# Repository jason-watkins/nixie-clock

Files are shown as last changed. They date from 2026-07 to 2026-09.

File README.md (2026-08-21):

[][cc-by-sa]

# Nixie Clock

USB-C powered nixie tube clock. Four IN-12B digits, two INS-1 colon lamps, K155ID1 BCD decoder/drivers.

## Boards

### Clock Face

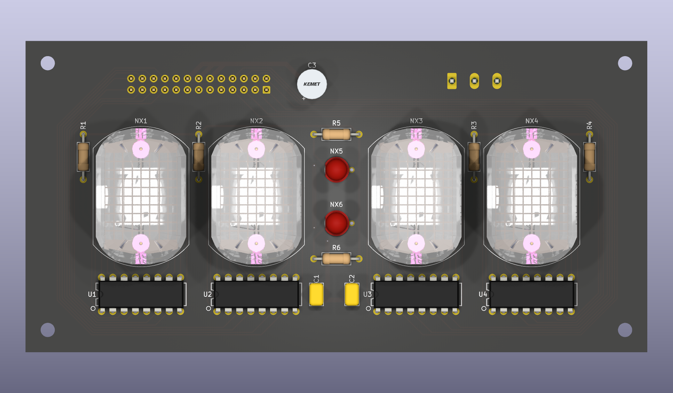
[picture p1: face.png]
Clock face board


### 170V Flyback converter

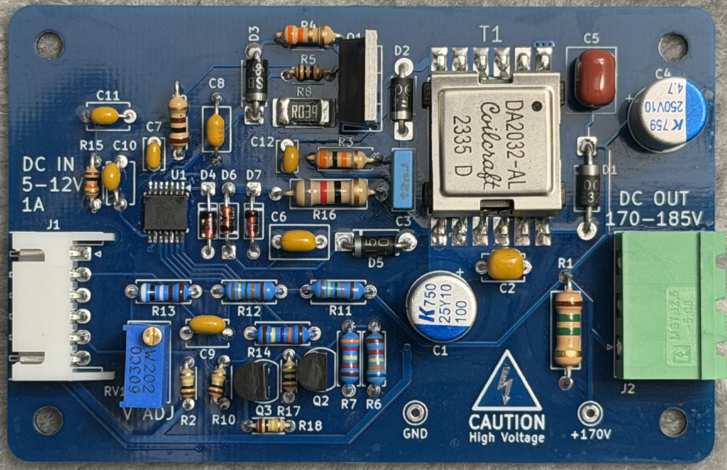
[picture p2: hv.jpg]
170 V flyback converter board


## Power

USB-PD negotiates 5-12V supply and feeds it into 3 converters:

- Flyback boost: 170V for the tube anodes
- 3.3V buck boost for the MCU. Boost exists to make sure a 3.3V FTDI type UART adapter provides the
  full 3.3V to the rail.
- 5V buck for the BCD drivers, bypassed if the source itself is 5V

## Firmware

Written in Rust, bakes in a list of SSID/password pairs at build time, tries
them until one connects, then syncs time from well-known NTP servers and
displays US Pacific time in 24 hour format.

## BCD/Tube Wiring Note

Tube cathodes are not wired to the decoder outputs in numerical order. The layout connects each
cathode to whichever decoder output it reaches most directly. The K155ID1's output order around its
package does not match the IN-12B's cathode order around its pin circle, so wiring it that way is
more trouble than it's worth. Firmware maps from BCD number to tube number in `nixie::Bcd`.

## Repository layout

- `pcb/` KiCad projects. One project each for the clock face, high voltage flyback converter and the
  main board with the MCU, USB-PD, 3.3V and 5V converters.
- `pcb/lib/` project libraries; origins and local changes in [pcb/lib/README.md](pcb/lib/README.md)
- `firmware/` firmware source code
- `docs/` design doc and vendor datasheets
- `scripts/` [make_release.py](scripts/make_release.py), fab exports with enforced revision bookkeeping

## Fab files

    python scripts/make_release.py --check
    python scripts/make_release.py

Writes gerbers, BOM, and placement files in several formats tailored for
different fab houses under `fab/` and tags the commit. The script's docstring
explains the revision rules it enforces.

## Credits

The K155ID1 symbol and its DIP16 footprint started as imports from
[judge2005's Eagle-and-KiCAD-Nixie-Libs](https://github.com/judge2005/Eagle-and-KiCAD-Nixie-Libs)
and were modified here. Full library inventory: [pcb/lib/README.md](pcb/lib/README.md).

## AI use

AI assistance is used to write and edit documentation, build symbols/footprints, and as a sounding
board for design work. All schematic drawing, PCB layout and code is done by hand.

## License

This work is licensed under a
[Creative Commons Attribution-ShareAlike 4.0 International License][cc-by-sa].

[][cc-by-sa]

[cc-by-sa]: http://creativecommons.org/licenses/by-sa/4.0/
[cc-by-sa-image]: https://licensebuttons.net/l/by-sa/4.0/88x31.png
[cc-by-sa-shield]: https://img.shields.io/badge/License-CC%20BY--SA%204.0-lightgrey.svg

except for third-party material carrying its own terms:

- `docs/datasheets/` — manufacturer datasheets and scanned Soviet tube
  documentation, redistributed for reference; sources in
  [docs/tube_notes.md](docs/tube_notes.md).
- `docs/design_analysis/fonts/` — PT Serif and IBM Plex Mono, under the SIL
  Open Font License 1.1.
- The K155ID1 symbol and DIP16 footprint, from judge2005 (no license stated,
  used with attribution); the manufacturer 3D models in
  `pcb/lib/nixie_clock.3dshapes/`; and the section data in
  `cad/ins1/shoulder_profile.py`, sampled from a third-party model. Provenance
  in [pcb/lib/README.md](pcb/lib/README.md).

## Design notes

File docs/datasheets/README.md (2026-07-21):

# Tube datasheets and extracted design values

Scans vendored from Dieter's Nixie Tube Data Archive (tube-tester.com) and
GRA & AFCH. The Soviet originals are image scans (no embedded text).

## IN-12B (ИН-12Б) — digit tubes, NX1–NX4

Source: `IN-12A_IN-12B.pdf` (original scan), `IN-12_english_gra-afch.pdf` (English summary).

| Parameter | Value |
|---|---|
| Typical maintaining (plate) voltage | ~145 V |
| Cathode current, digits | 2.5–3.5 mA |
| Decimal point (LHDP) current | 0.3–0.7 mA |
| Ignition voltage | verify in scan; NOS tubes drift upward with age |
| Digit height | 18 mm |

**Ballast (digit anodes):** R = (170 − 145) / 3 mA ≈ 8.2 kΩ.
At 2.5 mA use 10 kΩ. Dissipation ≈ 75 mW → 0.25 W part is fine.

## IN-6 (ИН-6) — colon dots, NX5–NX6

Source: `IN-6.pdf` (original label sheet, GOST 17821-75).

**Three electrodes** (footprint/symbol updated 2026-07-19 to match):
lead 1 = anode (A), lead 2 = indicator cathode (K), lead 3 = auxiliary
priming cathode (KA). Lead 1 is the physically separate one; count from it.

| Parameter | Value |
|---|---|
| Ignition voltage (either gap) | ≤ 140 V |
| Maintaining voltage @ 0.7 mA | ≤ 88–90 V |
| Permissible anode current | 0.6–0.85 mA |
| Indication current, min | 0.25 mA |
| Factory reference circuit | 200 kΩ from +180 V |

**Ballast (colon anodes):** R = (170 − 88) / 0.7 mA ≈ 117 kΩ → **120 kΩ**
gives ~0.68 mA, mid-range of permissible. Dissipation ≈ 56 mW.
One resistor per tube — never share ballast between gas tubes.

**KA handling:** auxiliary cathode exists to prime fast switching; unused in
always-on service. Leave NC (no-connect flag). Alternative if the third lead
is unwanted: clip it at the tube and leave the KA pad empty.

## Supply-rail note

IN-12 ignition worst case may approach the +170 V rail (some sources quote
up to ~200 V for aged/dark tubes). Design the HV supply with headroom:
adjustable 170–190 V, or verify strike on the actual NOS stock before
freezing the rail at 170 V. IN-6 strikes at ≤140 V — no concern.

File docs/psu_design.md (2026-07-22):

# Power system design

## Summary

The clock runs from a USB-C Power Delivery adapter. A resistor-configured
sink controller negotiates 12 V (9 V fallback) and gates it through a
back-to-back PFET load switch. Three converters hang off the switched rail:

- a 150 kHz flyback producing the nominal 170 V tube-anode rail,
  trimmable 160-196 V
- a fixed 5 V buck for the four K155ID1 binary-coded-decimal drivers
- a fixed 3.3 V buck for the MCU (ESP32 class)

Total draw is about 3 W, dominated by 15 mA at 175 V. The board uses a
single unified ground net.

The high-voltage converter is designed to match the nixie tube aesthetic.
While it is a modern flyback for efficiency, its supporting parts are
primarily through-hole, the chunkier the better, to give the converter a
somewhat retro look. The USB-C and buck sections make no such attempt;
USB-C is anachronistic on this board by definition, so those sections
follow current SMD practice.

Where SMD parts are used, the design is meant to remain hand-solderable.
As a rule of thumb, all SMD components are 0805 or larger. Hand soldering
is the requirement, not necessarily the plan: having the fab populate the
basic parts is an equally valid build path.

## USB-PD input

### Goal and strategy

Accept any Power Delivery adapter without firmware or a host processor.
The controller is configured entirely by resistor straps: it requests 12 V
when offered, falls back to 9 V, and rejects anything else. Downstream
circuits see no voltage until a contract exists, because the output passes
through a load switch the controller only closes after negotiation. On a
plain 5 V charger the board stays off rather than browning out;
the flyback's undervoltage lockout enforces this independently of the
controller. Hot-plugging is the normal operating procedure, so the
connector lines carry dedicated electrostatic-discharge protection. A
single red LED reports faults; there is no power-good indicator because
the display itself shows normal operation.

### Driving part: CYPD3176

The CYPD3176 (Infineon EZ-PD BCR-Plus) does all Power Delivery work in
hardware. Configuration:

| Strap | Setting | Divider (from VDDD) |
|---|---|---|
| VBUS_MIN | 9 V | 5.1 k / 1 k |
| VBUS_MAX | 12 V | 5.1 k / 2.4 k |
| ISNK_COARSE | 1 A | 5.1 k / 1 k |
| ISNK_FINE | +0 mA | strap to ground |
| CHARGING_MODE | float | enables all legacy charger protocols |

The strap dividers source from the chip's own VDDD pin, not the 3.3 V
rail: the pins are read ratiometrically against VDDD (canceling its
tolerance), and the 3.3 V buck sits downstream of the load switch, which
closes only after the contract the straps configure. D+ and D− route from
the connector to the chip because the legacy-protocol support uses them
for charger handshakes; the signaling is quasi-static, so they need no
differential-pair treatment. The connector's duplicate D+/D− pins are
commoned at the receptacle.

The sink-side current trip (CSP pin) is disabled by tying it to VSS.
Recovering from that trip requires an I2C host command, and this board has
no host; a trip would latch the supply off until power cycle. Overcurrent
coverage comes from the adapter's own limit, the chip's overvoltage and
undervoltage monitors, and each converter's cycle-by-cycle current limit.

FAULT drives the indicator LED. It asserts on any failed or lost contract
(no agreement, voltage out of window, insufficient offered current).

### Load switch

Two P-channel MOSFETs share a common gate, sources tied together, so
their body diodes oppose and block in both directions when off. The
chip's VBUS_CTRL output drives the gate with a microamp-class controlled
slew, which is the inrush limiter for the downstream capacitor bank. Gate
network: 1 kΩ series from VBUS_CTRL, 49.9 kΩ gate-source, 10 kΩ gate
pull-up to the raw bus for default-off, two 1 µF ramp capacitors, and a
10 V gate-source zener to protect the gate oxide during surge clamping.

Part requirements: dual PFET, drain-source rating of −30 V so the TVS
clamp voltage (about 24 V) lands inside it, gate-source rating of ±20 V
because the driver swings the gate the full rail, and on-resistance under
100 mΩ per device (the DMP3085LSD class fits). Switching speed is
irrelevant.

### Protection and support sizing

**Bus transient suppressor.** Three voltages define it: standoff at or
above the 13 V maximum rail so it never conducts in operation, breakdown
above standoff, and clamp below every victim rating downstream (the
−30 V switch pair, the flyback controller's 45 V BIAS pin, 25 V
capacitors). A 15 V-standoff unidirectional part clamping near 24 V
satisfies all three.

**Line protection.** One 5 V-standoff unidirectional
electrostatic-discharge diode per line on CC1, CC2, D+, and D−, placed in
the trace path at the connector. These cover discharge strikes only;
VBUS-to-CC cable faults are within the CC pins' 22 V rating.

**Fault LED.** 220 Ω from the FAULT pin. At the pin's guaranteed drive
point (4 mA at VDDD − 0.6 V, roughly 150 Ω effective pin impedance) the
LED runs near 4 mA; a shorted LED draws 9 mA against a 25 mA pin limit.
The LED must be red: only about 2.7 V of drive is guaranteed, which rules
out higher-forward-voltage colors.

**Bypass.** 4.7 µF plus 1 µF on the raw bus at the connector (inside the
USB-C spec's 1-10 µF attach window; capacitance behind the load switch
does not count against it), 1 µF plus two 100 nF on VDDD, 1 µF on VCCD.

## HV flyback converter

### Goal and strategy

Produce the tube-anode rail: nominally 175 V at up to 15 mA (four digits
at 3 mA plus two colon lamps at 0.7 mA is 13.4 mA). The output is
adjustable 160-196 V with a multiturn trimmer to account for unreliable
strike voltage in new-old-stock Soviet tubes.

The converter is a current-mode flyback running in discontinuous
conduction, meaning the transformer transfers all stored energy to the
output every cycle and idles at zero current before the next one. The
mode simplifies the control loop and eliminates diode reverse-recovery
loss. The design window for input is 8.5-13 V,
covering both negotiated voltages with margin.

The converter enables only above 8.1 V input, so a non-Power-Delivery
source leaves the high-voltage section cleanly off.

### Driving parts and configuration

**LM5155** (TI current-mode boost/flyback controller): 1.000 V feedback
reference, 100 mV current-limit sense threshold, 6.85 V internal
gate-drive rail, 45 V-rated BIAS input fed directly from the bus.
Configured for 150 kHz (RT = 147 kΩ), 4.7 ms soft-start (47 nF),
undervoltage lockout via a 143 kΩ / 32.4 kΩ divider (on at 8.1 V, off
near 7.4 V from the pin's 5 µA hysteresis current). PGOOD is pulled up to
VCC through 100 kΩ and broken out for the MCU.

**DA2032-AL** (Coilcraft flyback transformer): 1:10 ratio, 10 µH primary,
3 A peak rating, 0.15 µH maximum leakage. Primary windings paralleled;
secondary returns to the common ground (non-isolated use, shared-ground
feedback). The output reflects 17.5 V onto the primary during
demagnetization.

### Key sizing

**Operating point.** P_out = 2.63 W; at an assumed 85 % efficiency,
P_in ≈ 3.1 W (360 mA at 9 V). Energy per cycle 20.6 µJ gives a 2.0 A
primary peak. Worst-case conduction check at 8.5 V input: 2.39 µs on-time
plus 1.16 µs demagnetization is 3.55 µs of the 6.67 µs period, deep in
discontinuous conduction everywhere.

**Current sense.** 39 mΩ, 1 %. The controller's 100 mV ±7 % threshold
puts the current limit at 2.38-2.74 A: 17 % above the operating peak,
9 % under the core's 3 A rating. Dissipation 19 mW. The sense connection
is Kelvin-routed: the sense trace taps the resistor's own pads so trace
and solder resistance stay out of the measurement.

**Switch.** Off-state stress is input plus reflected voltage plus the
clamped leakage spike, about 48 V worst case. A 100 V logic-level TO-220
FET (IRL540N fits) leaves better than 2× margin. Losses total roughly
0.15 W (conduction 40 mW, gate 73 mW, small switching loss since turn-on
happens at zero current), no heat sink. A 10 Ω series gate resistor damps
the gate loop; turn-on at zero current means the slower edge adds no loss.

**Rectifier.** Reverse stress is V_out plus the turns ratio times maximum
input: 175 + 130 = 305 V, so a 600 V part. It must be ultra fast (about
75 ns recovery); a standard-recovery rectifier at 150 kHz would dissipate
watts. Average current is trivial. A UF4005-class axial part fills the
slot.

**Snubber.** Leakage inductance dumps 0.31 µJ per cycle (46 mW) at
switch-off. A resistor-capacitor-diode clamp across the primary holds the
spike 45 V above the input rail: 27 kΩ (0.5 W part), 10 nF film, and a
fast 100 V diode. The clamp voltage is deterministic, and at this leakage
energy the parts run well inside their ratings.

**Output capacitance.** 4.7 µF 250 V solid polymer plus 100 nF 250 V
film. Droop between demagnetization pulses is 21 mV; capacitance is not
the constraint. The polymer part's equivalent series resistance (its
internal resistance, about 0.5 Ω) lets through 100 mV edges, which the
film bypass absorbs. Polymer rather than wet electrolytic eliminates the
dry-out wear mechanism; the 250 V rating keeps 32 % margin at the trim
ceiling.

**Input capacitance.** 100 µF polymer plus 4.7 µF ceramic at the primary
loop. The 2 A triangular primary pulses must come from local capacitance,
not the cable; ripple demand is about 0.6 A against a multi-amp rating.

**Feedback divider.** Sized for about 100 µA of divider current. The top
leg is two 866 kΩ resistors in series so each body sees 87 V, inside the
element rating of a standard through-hole resistor (small chip resistors
are rated 50-75 V per element, so the divider is through-hole).
Bottom leg 8.87 kΩ plus a 2 kΩ multiturn trimmer spans 160-196 V.

**Bleeder.** 470 kΩ across the output serves two purposes: it discharges
the rail below 50 V within about 3 s of unplugging (2.2 s time constant),
and its 0.37 mA is a minimum load that keeps the loop in regulation with
the tubes unplugged from their sockets. 65 mW, 250 V-rated body.

**Compensation.** The error-amplifier network is 10 kΩ and 100 nF with a
220 pF high-frequency capacitor cancelling the output capacitor's
equivalent-series-resistance zero. Against the roughly 6 Hz load pole
this places the loop zero near 160 Hz and crossover near 1 kHz.

### Bench tuning

The compensation values are starting values. To verify: step the load
between blanked and full display (or switch a resistive dummy load) while
watching the rail. The target is monotonic
recovery with no ringing. If the response rings, increase the 100 nF or
reduce the 10 kΩ; if it is sluggish and margin allows, raise the 10 kΩ.

Two other bench checks. Strike voltage: raise the
trimmer until every digit of the actual tube stock strikes reliably, then
set the rail about 10 V above that point. Lockout: on a 5 V source the
converter must remain completely off.

## LV buck converters

### Goal and strategy

Two copies of one synchronous buck block, identical except for the
regulator: 5 V for the binary-coded-decimal drivers (about 0.1 A, nearly
static), 3.3 V for the MCU (ESP32-class Wi-Fi bursts of 300-500 mA). Identical blocks keep the bill of materials to one set of
support parts. Both rails are switched rather than linear: at 12 V input
a linear 5 V regulator dissipates more power than it delivers, and the
3.3 V rail must supply Wi-Fi bursts without sagging.

The K155ID1 drivers are TTL, which accepts 3.3 V CMOS logic levels
directly (2.0 V input-high threshold), so the rails need no level
shifting between them.

Both bucks switch at 1.1 MHz, two decades above the flyback; the
converters do not interact.

### Driving parts and configuration

AP63205 (5 V) and AP63203 (3.3 V): fixed-output synchronous bucks,
TSOT-26, 2 A rated, internally compensated, 1.1 MHz, built-in 4 ms
soft-start, 22 µA quiescent. Per block: feedback pin tied directly to the
output (fixed-output variants), enable tied to input (auto-start;
sequencing is handled upstream by the load switch), 100 nF bootstrap
capacitor between BST and SW.

### Key sizing

**Inductor.** 4.7 µH, the same part on both rails. Ripple at
12 V input is 0.56 A on the 5 V rail and 0.46 A on 3.3 V, 23-28 % of the
2 A rating. Saturation current must exceed the regulator's worst-case
3.1 A cycle-by-cycle limit (not the load), since the limit is ineffective
once the inductor saturates; the part is specified at 4 A. Shielded or semi-shielded construction, placed away from
the Configuration Channel lines and feedback nets.

**Input capacitor.** 10 µF, 25 V, X7R per block. At 12 V bias a
small-case ceramic delivers roughly half its rated capacitance;
acceptable at these loads with the attach capacitance on the same rail
upstream.

**Output capacitors.** Two 22 µF, 25 V per block. After bias derating
the banks deliver about 26 µF effective at 5 V and 33 µF at 3.3 V,
against a load-transient requirement of 9.5 µF and 21 µF respectively at
the full 2 A rating, inside the recommended 22-68 µF window.
The 25 V rating preserves the capacitance: derating scales with the
fraction of rated voltage in use.

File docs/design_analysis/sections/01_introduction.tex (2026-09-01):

\section{Introduction}
\label{sec:introduction}

The board drives six cold-cathode gas-discharge indicator tubes from a USB-C
Power Delivery source. Four IN-12B tubes show the hours and minutes. Two INS-1
tubes make the colon. One K155ID1 BCD decoder/driver controls each numeric
tube. The MCU commands the driver to select one of ten cathodes.

The 170~V supply powers the tube anodes. The 5~V supply powers the drivers. The
3.3~V supply powers the MCU. The USB-PD input stage supplies all three
converters. Thus, the tube and driver ratings set the requirements for each
upstream converter.

The analysis first derives the tube and driver requirements
(\cref{sec:tubes,sec:bcd-driver}). It then derives the 170~V flyback converter
(\cref{sec:hv-components,sec:hv-converter}). The next sections derive the 5~V
and 3.3~V supplies
(\cref{sec:lv-components,sec:5v-converter,sec:3v3-converter}). The last section
derives the USB-PD input stage.

\paragraph{Method.} Each parameter for a critical named component comes from a
datasheet in \texttt{docs/datasheets/}. Each parameter includes a file and page
reference. Datasheet ranges, tolerances, and test conditions remain with the
parameter. These details identify guaranteed limits, typical values, and test
values.

Parameters without a local datasheet use standard engineering practice. This
rule applies to common resistors, capacitors, and diodes. Package constraints
apply only when a critical part is available in one package. Otherwise, the
analysis applies at the schematic level.

\paragraph{Construction.} The 170~V converter, tube circuits, and driver
circuits use through-hole parts when possible. Larger parts are preferred when
multiple parts meet the requirements. The USB-PD circuit and low-voltage
supplies use surface-mount parts. The assembly supplier installs these parts.
Construction preferences do not change the derived electrical requirements.

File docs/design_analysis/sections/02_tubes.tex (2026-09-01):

\section{Nixie tube characteristics}
\label{sec:tubes}

The design uses six cold-cathode gas-discharge indicator tubes. Four tubes show
the hours and minutes. Two tubes make the colon. \Cref{tab:tube-designators}
defines their designators.

\begin{table}[htbp]
\centering
\caption{Nixie tube designators}\label{tab:tube-designators}
\begin{tabular}{|l|l|}
\hline
\textbf{Designator} & \textbf{Component} \\
\hline
NX1 to NX4 & IN-12B digit tubes (HH:MM display) \\
\hline
NX5 to NX6 & INS-1 colon tubes (colon separator) \\
\hline
\end{tabular}
\end{table}

Both parts have scanned Soviet factory datasheets. The tables copy the values
from these scans. They include the Russian parameter name when the English
meaning is not clear. The datasheets do not always give minimum, typical, and
maximum values. Some values are one-sided limits. The anode-supply design uses
these limits conservatively.

\subsection{IN-12B (digit tubes, NX1 to NX4)}
\label{sec:in12b}

Sources: \texttt{IN-12A\_IN-12B.pdf}, identified as [RU], is the Soviet factory
datasheet for the IN-12A and IN-12B. The IN-12B adds a decimal-point cathode.
The \texttt{IN-12\_english\_gra-afch.pdf} summary, identified as [EN], provides
an English cross-check.

{\footnotesize
\begin{longtable}{|L{3.6cm}|c|c|c|c|L{4.4cm}|c|}
\caption{IN-12B electrical and physical characteristics}\label{tab:in12b}\\
\hline
\textbf{Parameter} & \textbf{Min} & \textbf{Typ} & \textbf{Max} & \textbf{Units} & \textbf{Conditions} & \textbf{Source} \\
\hline
\endfirsthead
\caption[]{IN-12B electrical and physical characteristics (continued)}\\
\hline
\textbf{Parameter} & \textbf{Min} & \textbf{Typ} & \textbf{Max} & \textbf{Units} & \textbf{Conditions} & \textbf{Source} \\
\hline
\endhead
Maintaining (plate) voltage & & \num{145} & & \si{\volt} & ``Typical Plate Voltage'' & [EN] p.1 \\
\hline
Ignition voltage & & & \num{170} & \si{\volt} & discharge-onset voltage (``Напряжение возникновения разряда''); not split by variant & [RU] p.4 \\
\hline
Cathode (digit) current, DC operating & \num{2.5} & & \num{3.5} & \si{\milli\ampere} & ``Ток рабочий, постоянный, для цифр'' & [RU] p.4 \\
\hline
Cathode (digit) current, average (unfiltered half-wave AC) & \num{1} & & \num{2} & \si{\milli\ampere} & ``Ток рабочий, средний\ldots для цифр'' & [RU] p.4 \\
\hline
Cathode (digit) overload current & & & \num{5} & \si{\milli\ampere} & Time-limited; see overload duration below & [RU] p.4 \\
\hline
Decimal-point cathode current, DC operating & \num{0.3} & & \num{0.5} & \si{\milli\ampere} & IN-12B only (pin 12); IN-12A pin 12 unconnected & [RU] p.4 \\
\hline
Decimal-point overload current & & & \num{0.7} & \si{\milli\ampere} & & [RU] p.4 \\
\hline
Overload duration limit, IN-12A & & & \num{30} & min & Applies to the \SI{5}{\milli\ampere} digit overload above & [RU] p.5 \\
\hline
Overload duration limit, IN-12B & & & \num{33} & min & Applies to the \SI{5}{\milli\ampere} digit / \SI{0.7}{\milli\ampere} decimal-point overload above & [RU] p.5 \\
\hline
Anode supply voltage & \num{200} & \num{250} & & \si{\volt} & DC or half-wave-rectified AC; the \num{250}~V recommended value reduces discharge-onset delay time & [RU] p.4, p.5 \\
\hline
Conditioning current, pulsed & \num{1} & & \num{2} & \si{\milli\ampere} & $\geq$\SI{1}{\minute}/cathode, applied once after storage & [RU] p.5 \\
\hline
Conditioning current, DC & \num{2.5} & & \num{3} & \si{\milli\ampere} & $\geq$\SI{1}{\minute}/cathode, applied once after storage & [RU] p.5 \\
\hline
Continuous single-cathode life rating & & & \num{1000} & h & ``Longevity'' mode, one cathode continuously lit & [RU] p.5 \\
\hline
Digit height & & \num{18} & & mm & & [EN] p.1 \\
\hline
Envelope diameter & \num{29} & & \num{31} & mm & $-2$~mm tolerance [RU]; [EN] gives \SI{32}{\milli\meter} & [RU] p.3, [EN] p.1 \\
\hline
\end{longtable}
}

\paragraph{Data not specified.} Neither source specifies total anode current,
interelectrode capacitance, anode-to-cathode capacitance, a ballast resistance,
or a target anode current in the \SIrange{2.5}{3.5}{\milli\ampere} range.

\paragraph{Open item: anode supply voltage.} The datasheet specifies a minimum
anode supply of \SI{200}{\volt} and recommends \SI{250}{\volt}. The derived
anode-rail range is \SIrange{164.8}{191.5}{\volt}
(\cref{sec:hv-converter}). Thus, the design does not meet the specified minimum.

The factory value can apply to unfiltered half-wave AC (inferred). In this
mode, the supply stays near zero during approximately half of each mains cycle.
The peak voltage must then exceed the \SI{145}{\volt} typical maintaining
voltage. This condition gives sufficient average current and reliable ignition.
A regulated DC supply does not have this waveform. The datasheet does not
explain the difference.

\Cref{sec:hv-converter} keeps this item open. During bench adjustment, increase
the output until all installed digits ignite reliably. Then set the output
approximately \SI{10}{\volt} above this value.

\subsection{INS-1 (colon tubes, NX5 to NX6)}
\label{sec:ins1}

Source: \texttt{INS-1.pdf}, Soviet factory datasheet ODO.334.095 TU. Count the
two leads from the indicator dot. Lead 1 is the anode, which is the small
cylinder. Lead 2 is the cathode, which is the large cylinder. The tube has no
auxiliary or priming electrode.

{\footnotesize
\begin{longtable}{|L{4.6cm}|c|c|c|c|L{3.6cm}|c|}
\caption{INS-1 electrical characteristics}\label{tab:ins1}\\
\hline
\textbf{Parameter} & \textbf{Min} & \textbf{Typ} & \textbf{Max} & \textbf{Units} & \textbf{Conditions} & \textbf{Page} \\
\hline
\endfirsthead
\caption[]{INS-1 electrical characteristics (continued)}\\
\hline
\textbf{Parameter} & \textbf{Min} & \textbf{Typ} & \textbf{Max} & \textbf{Units} & \textbf{Conditions} & \textbf{Page} \\
\hline
\endhead
Striking voltage & \num{65} & & \num{90} & \si{\volt} & Discharge-onset voltage (``Напряжение возникновения разряда''); no test current given & 2 \\
\hline
Maintaining voltage & & & \num{55} & \si{\volt} & ``Напряжение поддержания разряда''; single-sided limit, no minimum given & 2 \\
\hline
Optimal indication current & & \num{0.5} & & \si{\milli\ampere} & ``Оптимальным током, обеспечивающим достаточную яркость свечения''; a brightness recommendation, with no band around it & 3 \\
\hline
\end{longtable}
}

\paragraph{Conditioning after storage.} After long storage, operate the tube at
its nominal discharge current for one to two minutes. The datasheet refers to
GOST 11163-84 and OST 11~339.003-75. The IN-12B has a similar instruction
(\cref{sec:in12b}).

\paragraph{Data not specified.} The datasheet gives no minimum maintaining
voltage. It gives no operating-current range around the
\SI{0.5}{\milli\ampere} brightness value. It also gives no maximum switching
frequency, interelectrode capacitance, ballast value, or envelope dimensions.

\Cref{sec:hv-load-colon} sizes the ballast from the
\SI{0.5}{\milli\ampere} value. It also gives the current range caused by output
adjustment. A tube with a maintaining voltage below \SI{55}{\volt} draws more
current through a fixed ballast. The datasheet gives no lower limit for this
calculation.

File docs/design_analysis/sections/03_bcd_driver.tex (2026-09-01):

\section{BCD decoder/driver characteristics}
\label{sec:bcd-driver}

One K155ID1 BCD decoder/driver controls each IN-12B tube
(\cref{sec:tubes}). U1 to U4 are Soviet functional equivalents of the Texas
Instruments SN74141. Each driver has ten open-collector outputs. Each output
connects directly to one tube cathode. The selected output sinks current and
pulls its cathode low. The other nine outputs are high impedance. The circuit
has no high-voltage buffer between the driver and the tube. Thus, the driver
output must tolerate the voltage on an unselected cathode.

\paragraph{Substitution.} No K155ID1 datasheet is in
\texttt{docs/datasheets/}. This analysis assumes that the K155ID1 is
electrically equivalent to the SN74141 (inferred). The values come from
\texttt{SN74141\_TI.pdf}, published in 1972 and revised in 1983. The source has
separate absolute-maximum and operating-characteristic tables. The following
tables keep this separation. \Cref{sec:bcd-voltage-risk} depends on the source
of each off-state voltage. Tags \textbf{[ROC]} and \textbf{[EC]} identify the
two operating tables.

{\footnotesize
\begin{longtable}{|L{4.6cm}|c|c|c|L{4.2cm}|c|}
\caption{SN74141 absolute maximum ratings (substituting for K155ID1)}\label{tab:sn74141-max}\\
\hline
\textbf{Parameter} & \textbf{Min} & \textbf{Max} & \textbf{Units} & \textbf{Conditions} & \textbf{Page} \\
\hline
\endfirsthead
\caption[]{SN74141 absolute maximum ratings (substituting for K155ID1) (continued)}\\
\hline
\textbf{Parameter} & \textbf{Min} & \textbf{Max} & \textbf{Units} & \textbf{Conditions} & \textbf{Page} \\
\hline
\endhead
Supply voltage \(V_{CC}\) & & \num{7} & \si{\volt} & relative to network ground & 2 \\
\hline
Input voltage & & \num{5.5} & \si{\volt} & & 2 \\
\hline
Current into any output (off-state) & & \num{2} & \si{\milli\ampere} & & 2 \\
\hline
Operating free-air temperature & \num{0} & \num{70} & \si{\celsius} & & 2 \\
\hline
Storage temperature & \num{-65} & \num{150} & \si{\celsius} & & 2 \\
\hline
\end{longtable}
}

{\footnotesize
\begin{longtable}{|L{4.6cm}|c|c|c|c|L{3.4cm}|c|}
\caption{SN74141 recommended operating conditions and electrical characteristics (substituting for K155ID1)}\label{tab:sn74141}\\
\hline
\textbf{Parameter} & \textbf{Min} & \textbf{Typ} & \textbf{Max} & \textbf{Units} & \textbf{Conditions} & \textbf{Source} \\
\hline
\endfirsthead
\caption[]{SN74141 recommended operating conditions and electrical characteristics (substituting for K155ID1) (continued)}\\
\hline
\textbf{Parameter} & \textbf{Min} & \textbf{Typ} & \textbf{Max} & \textbf{Units} & \textbf{Conditions} & \textbf{Source} \\
\hline
\endhead
Supply voltage \(V_{CC}\) & \num{4.75} & \num{5} & \num{5.25} & \si{\volt} & & [ROC] p.2 \\
\hline
\textbf{Off-state output voltage} & & & \textbf{\num{60}} & \si{\volt} & & \textbf{[ROC] p.2} \\
\hline
\(V_{IH}\), high-level input voltage & \num{2} & & & \si{\volt} & & [EC] p.2 \\
\hline
\(V_{IL}\), low-level input voltage & & & \num{0.8} & \si{\volt} & & [EC] p.2 \\
\hline
\(V_{IK}\), input clamp voltage & & & \num{-1.5} & \si{\volt} & \(V_{CC}=\)min, \(I_I=-5\)~mA & [EC] p.2 \\
\hline
\(V_{O(on)}\), on-state output voltage & & & \num{2.5} & \si{\volt} & \(V_{CC}=\)min, \(I_O=7\)~mA & [EC] p.2 \\
\hline
\textbf{\(V_{O(off)}\), off-state output voltage, counts 0 to 9} & \textbf{\num{60}} & & & \si{\volt} & \(V_{CC}=\)max, \(I_O=0.5\)~mA & \textbf{[EC] p.2} \\
\hline
\(I_{O(off)}\), off-state reverse current & & & \num{50} & \si{\micro\ampere} & \(V_{CC}=\)max, \(V_O=55\)~V, \(T_A=55\)\si{\celsius} & [EC] p.2 \\
\hline
\(I_{O(off)}\), off-state reverse current, counts 10 to 15 & & \num{5} & \num{15} & \si{\micro\ampere} & \(V_O=30\)~V, \(T_A=70\)\si{\celsius} & [EC] p.2 \\
\hline
\(I_I\), input current at max input voltage & & & \num{1} & \si{\milli\ampere} & \(V_{CC}=\)max, \(V_I=5.5\)~V & [EC] p.2 \\
\hline
\(I_{IH}\), A input & & & \num{40} & \si{\micro\ampere} & \(V_{CC}=\)max, \(V_I=2.4\)~V & [EC] p.2 \\
\hline
\(I_{IH}\), B/C/D input & & & \num{80} & \si{\micro\ampere} & \(V_{CC}=\)max, \(V_I=2.4\)~V & [EC] p.2 \\
\hline
\(I_{IL}\), A input & & & \num{-1.6} & \si{\milli\ampere} & \(V_{CC}=\)max, \(V_I=0.4\)~V & [EC] p.2 \\
\hline
\(I_{IL}\), B/C/D input & & & \num{-3.2} & \si{\milli\ampere} & \(V_{CC}=\)max, \(V_I=0.4\)~V & [EC] p.2 \\
\hline
\(I_{CC}\), supply current & & \num{16} & \num{25} & \si{\milli\ampere} & \(V_{CC}=\)max, inputs grounded, outputs open & [EC] p.2 \\
\hline
\end{longtable}
}

Pin mapping for the 16-pin DIP: BCD inputs A, B, C, and D are on pins 3, 6, 7,
and 4. \(V_{CC}\) is on pin 5. Ground is on pin 12. Outputs 0 to 9 are on pins
16, 15, 8, 9, 13, 14, 11, 10, 1, and 2. The datasheet does not specify package
thermal resistance, maximum junction temperature, ESD rating, or propagation
delay.

\subsection{Off-state output voltage}
\label{sec:bcd-voltage-risk}

The absolute-maximum table gives no off-state output-voltage limit. It gives
only a \SI{2}{\milli\ampere} off-state output-current limit. The only off-state
voltage is \SI{60}{\volt}. This value is a guaranteed operating condition. The
electrical-characteristics table also guarantees no breakdown at
\SI{60}{\volt} with a \SI{0.5}{\milli\ampere} test load. The datasheet does not
specify operation above \SI{60}{\volt}.

Two leakage-current tests use lower voltages. The maximum leakage is
\SI{50}{\micro\ampere} at \SI{55}{\volt}. The typical and maximum leakage is
\SI{5}{\micro\ampere} and \SI{15}{\micro\ampere} at \SI{30}{\volt}. These test
values are not standoff-voltage limits.

The anode rail spans \SIrange{164.8}{191.5}{\volt}
(\cref{sec:hv-converter}). An unselected cathode can see approximately
\SIrange{145}{191.5}{\volt}. This range is 2.4 to 3.2 times the guaranteed
\SI{60}{\volt} standoff.

Amateur Nixie clocks commonly use direct cathode drive at similar rail voltages
(inferred). This use does not prove compliance with the SN74141 rating. The
actual breakdown voltage can exceed the guaranteed value (inferred). Also, an
unselected cathode floats in the tube discharge field (inferred). A resistive
model can therefore overestimate its voltage. These explanations have no cited
source. The item remains open until a K155ID1 datasheet or a measurement gives
a higher verified rating.

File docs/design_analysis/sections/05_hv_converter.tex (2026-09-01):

\section{170~V flyback converter derivation}\label{sec:hv-converter}

The 170~V supply uses an LM51561H flyback controller
(\cref{sec:lm5156h}). This section specifies its circuit requirements and
component values. \Cref{sec:tubes} defines NX1 to NX6.
\Cref{tab:hv-designators} defines the remaining designators.

{\footnotesize
\begin{table}[htbp]
\centering
\caption{170~V flyback converter: component designators}\label{tab:hv-designators}
\begin{tabular}{|l|l|}
\hline
\textbf{Designator} & \textbf{Function} \\
\hline
\des{T}{HV} & Flyback transformer \\

\hline
\des{R}{BALDIG} & Digit-tube anode ballast, one per tube (NX1 to NX4) \\

\hline
\des{R}{BALCOL} & Colon-tube anode ballast, one per tube (NX5 and NX6) \\

\hline
\des{Q}{HVSW} & Primary-side switching FET \\

\hline
\des{R}{HVCS} & Current-sense resistor \\

\hline
\des{R}{HVCSF}, \des{C}{HVCSF} & CS-pin filter \\

\hline
\des{R}{HVD1}, \des{R}{HVD2} & Feedback divider, upper (fixed) \\

\hline
\des{R}{HVD3}, \des{RV}{HVTRIM} & Feedback divider, lower (fixed \& trim) \\

\hline
\des{R}{HVRT} & RT (switching-frequency-set) resistor \\

\hline
\des{R}{HVCOMP}, \des{C}{HVC1}, \des{C}{HVC2} & COMP-pin compensation network \\

\hline
\des{R}{HVGON} & Gate-drive resistor (turn-on) \\

\hline
\des{R}{HVGOFF}, \des{D}{HVGOFF} & Turn-off speedup network (bypasses \des{R}{HVGON} on turn-off only) \\

\hline
\des{D}{HVRECT} & Output rectifier diode \\

\hline
\des{R}{HVCL}, \des{C}{HVCL}, \des{D}{HVCL} & RCD clamp (snubber) network \\

\hline
\des{R}{HVBLEED} & Bleeder resistor \\

\hline
\des{C}{HVSS} & Soft-start capacitor \\

\hline
\des{R}{HVUV1}, \des{R}{HVUV2} & Input UVLO divider \\

\hline
\des{Q}{HVINH}, \des{R}{HVINHPU}, \des{R}{HVINHPD} & Display inhibit shunt and its gate divider \\

\hline
\des{Q}{HVREL}, \des{R}{HVRELPD} & Inhibit release switch and its gate pull-down \\

\hline
\des{R}{HVPG} & PGOOD pull-up resistor \\

\hline
\des{C}{HVVCC} & VCC regulator bypass capacitor \\

\hline
\des{C}{HVPUMP}, \des{R}{HVPUMP} & Bias charge-pump coupling capacitor and series resistor \\

\hline
\des{D}{HVPUMP}, \des{D}{HVRESET} & Charge-pump delivery and reset diodes \\
\hline
\des{D}{HVSTART} & BIAS start-up diode from $V_{\mathrm{BUS}}$ \\
\hline
\des{D}{HVZ} & BIAS clamp zener \\
\hline
\des{C}{HVBIAS} & BIAS reservoir capacitor \\
\hline
\des{C}{HVI1}, \des{C}{HVI2} & Input bulk / high-frequency capacitance \\
\hline
\des{C}{HVO1}, \des{C}{HVO2} & Output capacitance \\

\hline
\end{tabular}
\end{table}
}

\begin{figure}[htbp]
  \centering
  
  \caption{170~V flyback converter: reference schematic}\label{fig:hv}
\end{figure}

\Cref{fig:hv} shows the connections. It does not show the tubes or ballast
resistors \des{R}{BALDIG} and \des{R}{BALCOL}. \Cref{sec:hv-load} derives these
loads on $V_{\mathrm{HV}}$.

The input $V_{\mathrm{BUS}}$ spans \SIrange{4.75}{12.6}{\volt}
(\cref{sec:pd-classes}). The lower limit is the \SI{5}{\volt} contract at
$-5\,\%$. The upper limit is the \SI{12}{\volt} contract at $+5\,\%$. The
nominal input is \SI{9}{\volt}.

Operation at \SI{4.75}{\volt} adds three requirements. The converter needs the
auxiliary bias supply in \cref{sec:hv-house-pump}. It needs the UVLO threshold
in \cref{sec:hv-uvlo}. It also needs the display inhibit in
\cref{sec:hv-inhibit}. The inhibit uses the negotiated current limit because
the contract voltage does not identify the available current.

\subsection{Preliminaries}\label{sec:hv-prelim}

\subsubsection{Switching frequency}\label{sec:hv-fsw-choice}

In DCM, $L_p f_{\mathrm{sw}} I_{\mathrm{pk}}^2 = 2 P_{\mathrm{in}}$. The
transformer sets $L_p$ (\cref{sec:da2032}). The load sets $P_{\mathrm{in}}$
(\cref{sec:hv-budget}). Thus, the switching frequency sets the peak current.
It also sets the margin below the \SI{3.0}{\ampere} saturation rating. Two
constraints limit the frequency. Both scale with $\sqrt{f_{\mathrm{sw}}}$.

Both $t_{\mathrm{on}}$ and $t_{\mathrm{dem}}$ are proportional to
$f_{\mathrm{sw}}^{-1/2}$. The period is proportional to
$f_{\mathrm{sw}}^{-1}$. Therefore, the conduction fraction increases with
$\sqrt{f_{\mathrm{sw}}}$. At the worst condition in \cref{sec:hv-dcm}, DCM
ends at \SI{185}{\kilo\hertz}. The idle fraction falls to $5\,\%$ at
\SI{168}{\kilo\hertz}.

At low frequency, the permitted current-sense resistance decreases
(\cref{sec:hv-cs-sense}). Core protection requires \des{R}{HVCS} to be at least
\SI{37.8}{\milli\ohm}. The power-delivery limit is
$\SI{93}{\milli\volt}/I_{\mathrm{pk}}^{(L\min)}$. This limit increases with
$\sqrt{f_{\mathrm{sw}}}$. The two limits are equal at
\SI{132}{\kilo\hertz}. The specified \SI{39}{\milli\ohm} resistor meets the
power-delivery limit above \SI{141}{\kilo\hertz}.

The loss model does not add a tighter frequency constraint. The design uses
\SI{150}{\kilo\hertz}. This value is inside both permitted ranges. The implemented frequency
is \SI{149.4}{\kilo\hertz}. At this frequency, the commanded peak current is
\SI{2.18}{\ampere}, or $73\,\%$ of $I_{\mathrm{sat}}$.

\subsubsection{RT resistor}\label{sec:hv-fsw}

For the \SI{150}{\kilo\hertz} target of \cref{sec:hv-fsw-choice}, the RT
equation of \cref{sec:lm5156h} gives

\begin{align*}
  R_T &= \frac{2.21\times10^{10}}{f_{RT}} - 955
       = \frac{2.21\times10^{10}}{1.5\times10^{5}} - 955
       = \SI{146.4}{\kilo\ohm}.
\end{align*}
The nearest standard value is $\des{R}{HVRT} = \SI{147}{\kilo\ohm}$. It gives
\begin{align*}
  f_{RT} &= \frac{2.21\times10^{10}}{147\,000 + 955} = \SI{149.4}{\kilo\hertz}
\end{align*}
All subsequent arithmetic uses \SI{149.4}{\kilo\hertz}.

The DA2032-AL is characterized only at \SI{100}{\kilo\hertz}
(\cref{sec:da2032}). The analysis applies its inductance and saturation data at
\SI{149.4}{\kilo\hertz} (inferred). It does not apply the core-loss data at
this frequency. \Cref{sec:hv-op} includes a core-loss allowance.

\subsubsection{Input UVLO}\label{sec:hv-uvlo}

UVLO must release below the \SI{4.75}{\volt} minimum input. The release voltage
must include the LM51561H threshold tolerance. A \SI{4.75}{\volt} release value
could prevent operation at the specified minimum. The design target is
\SI{4.4}{\volt}.

An external divider sets the UVLO/SYNC thresholds. The typical thresholds are
\SI{1.5}{\volt} rising and \SI{1.45}{\volt} falling
(\cref{sec:lm5156h}). The required divider ratio is:
\begin{align*}
  \frac{\des{R}{HVUV1}+\des{R}{HVUV2}}{\des{R}{HVUV2}}
  &= \frac{4.4}{1.5} = 2.93.
\end{align*}

The divider ratio does not set \des{R}{HVUV2}. A value of tens of kilohms gives
low quiescent current. It also gives useful hysteresis from the
\SI{5}{\micro\ampere} pin current (\cref{sec:lm5156h}). The design uses
\SI{32.4}{\kilo\ohm}:
\begin{align*}
  \des{R}{HVUV1} &= \des{R}{HVUV2}\left(\frac{4.4}{1.5} - 1\right)
  = 32.4 \times 1.933 = \SI{62.6}{\kilo\ohm}
  \;\rightarrow\; \SI{63.4}{\kilo\ohm}.
\end{align*}

The same pin has an EN comparator with an approximately
\SI{0.52}{\volt} rising threshold. The divider refers this threshold to
\SI{1.54}{\volt} at $V_{\mathrm{BUS}}$. Thus, EN becomes true before UVLO
releases during a monotonic input ramp. One divider serves both comparators.

\subsubsection{Display inhibit}\label{sec:hv-inhibit}

UVLO prevents operation before the input rail is present. It does not verify
that the source can supply the tube current. The MCU reads the negotiated
USB-PD contract and controls a display-inhibit signal. N-channel MOSFET
\des{Q}{HVINH} is across \des{R}{HVUV2}. It grounds UVLO/SYNC when it is on. The
MCU releases the inhibit. Two requirements set the gate circuit.

\begin{itemize}[nosep]
  \item \textbf{Assert the inhibit before converter operation.} The MCU and
    converter both use $V_{\mathrm{BUS}}$. However, the MCU 3.3~V rail starts
    after $V_{\mathrm{BUS}}$ appears (\cref{sec:3v3-converter}). A gate bias
    from the 3.3~V rail would depend on two converter start times. A gate bias
    from $V_{\mathrm{BUS}}$ rises with the UVLO divider. Resistor ratios then set
    the sequence.
  \item \textbf{Isolate the MCU control pin from the gate node.} The gate bias
    can reach \SI{11.5}{\volt}. The MCU pin limit is \(V_{DD}+0.3\)~V
    (\cref{sec:esp32}). Thus, the control pin and gate cannot use one node.
\end{itemize}

\des{R}{HVINHPU} and \des{R}{HVINHPD} divide $V_{\mathrm{BUS}}$ onto the gate of
\des{Q}{HVINH}. A second N-channel MOSFET, \des{Q}{HVREL}, pulls this gate to
ground when the MCU enables the display. \des{R}{HVRELPD} holds
\des{Q}{HVREL} off when the MCU pin is high impedance. Thus, a high-impedance
MCU pin keeps the display inhibited. \Cref{sec:esp32-usb} gives the same safe
state to the USB data switch.

\paragraph{Gate divider.} $\des{R}{HVINHPU} = \SI{100}{\kilo\ohm}$ and
$\des{R}{HVINHPD} = \SI{1}{\mega\ohm}$ put $0.909\,V_{\mathrm{BUS}}$ on the
gate nominally. The nominal gate voltage spans \SIrange{4.32}{11.5}{\volt}.
Thus, the required
gate rating is $V_{GS} \geq \pm\SI{12}{\volt}$. The pair draws a maximum of
\SI{11.5}{\micro\ampere}.

\paragraph{Ordering.} The earliest UVLO release includes both divider tolerances
and the minimum rising threshold. It occurs at
$V_{\mathrm{BUS}} = \SI{4.16}{\volt}$. The minimum inhibit-gate divider ratio is
0.900. The gate voltage is then \SI{3.74}{\volt}. Therefore, the shunt requires
$V_{GS(th)} \leq \SI{3.74}{\volt}$. The specified
$V_{GS(th)} \leq \SI{2}{\volt}$ meets this limit. It asserts the inhibit by
$V_{\mathrm{BUS}} = \SI{2.22}{\volt}$. The inhibit therefore becomes active at least
\SI{1.94}{\volt} before UVLO can
release. EN can become true first. Until inhibit assertion, the controller stays
in standby and does not switch (\cref{sec:lm5156h}).

\paragraph{Shunt conduction.} At maximum input, \des{Q}{HVINH} sinks
\SI{199}{\micro\ampere}. It must hold UVLO/SYNC below \SI{1.45}{\volt}. Thus,
its channel resistance must be less than \SI{7.3}{\kilo\ohm}. A part with
single-digit ohm resistance at the \SI{3.74}{\volt} minimum required drive meets this
requirement.

\paragraph{Release switch.} \des{Q}{HVREL} blocks a maximum of
\SI{11.5}{\volt} when off. It sinks a maximum of \SI{126}{\micro\ampere} when
on. The MCU supplies a \SI{3.3}{\volt} gate drive. Therefore,
$V_{GS(th)} \leq \SI{2}{\volt}$. One part can serve both switch positions. A
maximum channel resistance of \SI{4.8}{\kilo\ohm} keeps \des{Q}{HVINH} off.
$\des{R}{HVRELPD} = \SI{100}{\kilo\ohm}$ holds \des{Q}{HVREL} off. The MCU
sinks \SI{33}{\micro\ampere} when it turns \des{Q}{HVREL} on.

\subsubsection{Controller housekeeping (BIAS, VCC, PGOOD)}\label{sec:hv-house}

\paragraph{BIAS.}\label{sec:hv-house-bias}
BIAS supplies the internal regulator for the \SI{6.85}{\volt} VCC gate-driver
rail. The datasheet specifies the VCC output at
$V_{\mathrm{BIAS}} = \SI{8}{\volt}$ (\cref{sec:lm5156h}). A direct connection
to $V_{\mathrm{BUS}}$ cannot maintain this condition below approximately
\SI{8}{\volt}. Therefore, the charge pump in \cref{sec:hv-house-pump} supplies
BIAS. A diode-OR connection from $V_{\mathrm{BUS}}$ supplies start-up current.

\paragraph{VCC regulator capacitor.}\label{sec:hv-house-vcc} The datasheet
requires \SIrange{1}{4.7}{\micro\farad} (\ds{lm5156h.pdf}{14}). The design uses
$\des{C}{HVVCC} = \SI{2.2}{\micro\farad}$. This value allows for the DC-bias
derating of a small ceramic capacitor.

\paragraph{PGOOD pull-up.}\label{sec:hv-house-pgood} PGOOD is an open-drain
output (\cref{sec:lm5156h}). The datasheet recommends a pull-up of at least
\SI{10}{\kilo\ohm}. The pull-up must also charge the pin before the
\SI{25}{\micro\second} deglitch interval ends. The design uses
$\des{R}{HVPG} = \SI{100}{\kilo\ohm}$ to the 3.3~V rail. With
\SI{20}{\pico\farad} of stray capacitance, the time constant is approximately
\SI{2}{\micro\second}. The pull-up voltage meets the PGOOD voltage limits. The
low-state current is \SI{33}{\micro\ampere}, below the
\SI{1}{\milli\ampere} limit.

\paragraph{Spread spectrum (DITHOFF).}\label{sec:hv-house-dithoff}
DITHOFF controls the spread-spectrum function (\ds{lm5156h.pdf}{3}). The
modulation span is $0.156 f_{\mathrm{sw}}$, or approximately
\SI{23}{\kilo\hertz}. It combines a triangular sweep with cycle-to-cycle random
modulation (\ds{lm5156h.pdf}{17}).

The dither decreases the DCM idle time. At the top of the dither range,
$t_{\mathrm{on}}+t_{\mathrm{dem}}$ decreases by $3.7\,\%$. The period decreases
by $7.2\,\%$. Thus, the minimum DCM idle fraction decreases from $10.5\,\%$ to
$7.0\,\%$ (\cref{sec:hv-dcm}). The design does not need spread-spectrum
operation. DITHOFF connects to VCC to disable this function.

\subsubsection{Auxiliary bias charge pump}\label{sec:hv-house-pump}

\paragraph{Requirement.} The gate drive above the Miller plateau turns
\des{Q}{HVSW} off. The plateau and \des{D}{HVGOFF} drop subtract
\SI{3.5}{\volt} from VCC. The remaining voltage drives
$\des{R}{HVGOFF}+R_{\mathrm{int}} = \SI{4.8}{\ohm}$. Thus,
$t_{\mathrm{ovl}} = Q_{GD}/I_{\mathrm{gate}}$. Turn-off overlap is the largest
loss term. The commanded peak current must remain below the
\SI{2.36}{\ampere} minimum current limit (\cref{sec:hv-cs-sense}). Solving the
loss iteration limits overlap to \SI{118}{\nano\second}. This condition
requires at least \SI{4.52}{\volt} of gate drive. A direct BIAS feed from
$V_{\mathrm{BUS}}$ gives only \SI{4.20}{\volt} at minimum input. It cannot meet
the requirement.

Therefore, the switch node supplies BIAS through a charge pump. During the off
time, the node is one tenth of the output voltage above $V_{\mathrm{BUS}}$
(\cref{sec:hv-op-converge}). This level is approximately \SI{24}{\volt} at
minimum input. The pump keeps BIAS above \SI{8}{\volt}. At this voltage, the
datasheet specifies the regulated \SI{6.85}{\volt} VCC output.

\paragraph{Topology.} \des{C}{HVPUMP} and \des{R}{HVPUMP} couple the switch
drain to the pump node. \des{D}{HVPUMP} transfers charge to BIAS.
\des{C}{HVBIAS} stores the charge. \des{D}{HVRESET} returns the pump node to
ground during each on time. \des{D}{HVSTART} supplies BIAS from
$V_{\mathrm{BUS}}$ before switching starts.

During the on time, the drain is near ground. \des{D}{HVRESET} holds the pump
node one diode drop below the drain. This condition charges \des{C}{HVPUMP} to
approximately \SI{0.9}{\volt}. At turn-off, the drain rises to
$V_{\mathrm{BUS}} + V_{\mathrm{refl}}$. The pump node rises with it.
\des{D}{HVPUMP} conducts until the node falls to $V_{\mathrm{BIAS}} + V_F$.

The pump needs no regulation loop, because the controller fixes the charge it
must deliver:
\begin{align*}
  Q_{\mathrm{BIAS}} &= Q_G + \frac{I_Q}{f_{\mathrm{sw}}}
  = 40 + \frac{580\,\si{\micro\ampere}}{149.4\,\si{\kilo\hertz}}
  = \SI{43.9}{\nano\coulomb}
  \quad (I_{\mathrm{BIAS}} = \SI{6.56}{\milli\ampere}),
\end{align*}
so BIAS settles wherever the delivered packet equals that demand:
\begin{align*}
  V_{\mathrm{BIAS}} &= (V_{\mathrm{BUS}} + V_{\mathrm{refl}})
  - \SI{0.9}{\volt} - V_{F} - \frac{Q_{\mathrm{BIAS}}}{k\,\des{C}{HVPUMP}},
  &
  k &= 1 - e^{-t_{\mathrm{dem}}/(\des{R}{HVPUMP}\des{C}{HVPUMP})},
\end{align*}
with $k$ the fraction of the packet transferred inside the demagnetization
window. \des{D}{HVSTART} reverse-biases once the pump lifts BIAS past
$V_{\mathrm{BUS}}$, and must be a Schottky: at \SI{4.75}{\volt} a silicon drop
would leave only \SI{0.55}{\volt} above the controller's \SI{3.5}{\volt} BIAS
minimum during start-up.

\paragraph{Sizing.} \des{R}{HVPUMP}'s time constant must be long against the
\SI{10}{\nano\second} leakage spike (\cref{sec:hv-clamp}) and short against
$t_{\mathrm{dem}}$, so the packet completes inside the shelf. $\des{R}{HVPUMP} =
\SI{82}{\ohm}$ gives $\tau = \SI{385}{\nano\second}$, between that spike and a
$\ge\SI{940}{\nano\second}$ window, and limits the current drawn from the switch
node to \SI{118}{\milli\ampere}.

\des{C}{HVPUMP} is set by the worst delivery corner, the bottom of the input
window at the lowest trim setpoint (\SI{164.8}{\volt},
\cref{tab:hv-ballast-divider}), where the reflected shelf and the load are both
smallest, shortening $t_{\mathrm{dem}}$ to \SI{940}{\nano\second} and $k$ to
\num{0.92}. BIAS must stay at or above \SI{8}{\volt}, the condition at which the
datasheet specifies the \SI{6.85}{\volt} VCC output, and $\des{C}{HVPUMP} =
\SI{4.7}{\nano\farad}$ holds \SI{9.09}{\volt} there even at the $-5\,\%$ limit
of a C0G tolerance. The dielectric is specified because the pump meters charge:
a class-II part's voltage coefficient would change the delivered packet with
operating point.

Across the rest of the window BIAS rises with the input, reaching
\SI{20.4}{\volt} at \SI{12.6}{\volt} in, well inside the pin's \SI{60}{\volt}
recommended range. \des{D}{HVZ}, a \SI{30}{\volt} zener, bounds a fault that
drives the reflected voltage above that range and conducts no current in normal
operation. \des{Q}{HVSW} bounds the fault in turn: the drain reaches its
\SI{100}{\volt} rating at roughly \SI{520}{\volt} out, where the shelf is
\SI{65}{\volt} and the pump meters $k\,\des{C}{HVPUMP}(V_{\mathrm{shelf}} -
\SI{1.6}{\volt} - V_Z) = \SI{149}{\nano\coulomb}$ against the
\SI{43.9}{\nano\coulomb} demand. The zener sinks the \SI{105}{\nano\coulomb}
surplus, $30 \times 105\,\si{\nano\coulomb} \times 149.4\,\si{\kilo\hertz} =
\SI{471}{\milli\watt}$, and a \SI{0.5}{\watt} part covers it as a transient:
charging $C_{\mathrm{out}}$ to \SI{520}{\volt} at the current limit takes about
\SI{140}{\milli\second}.

\des{C}{HVBIAS} carries the controller between packets, at a droop of
$I_{\mathrm{BIAS}}/(\des{C}{HVBIAS} f_{\mathrm{sw}}) = \SI{88}{\milli\volt}$ for
\SI{0.5}{\micro\farad}, negligible against the regulator's \SI{2.2}{\volt} of
headroom at the worst corner, so \SI{0.5}{\micro\farad} \emph{effective} is the
floor. A class-II ceramic at \SI{20.4}{\volt} of bias retains well over half its
value on a \SI{50}{\volt} rating, so \SI{1}{\micro\farad} X7R keeps that floor.
The pump stops during pulse skipping at light load. BIAS then draws current
through \des{D}{HVSTART}. The reduced gate voltage increases turn-off loss, but
the peak current is low.

The pump diodes hold the pump node between $-V_F$ and
$V_{\mathrm{BIAS}}+V_F$. Each diode blocks at most \SI{21.1}{\volt} during
normal operation. \des{D}{HVZ} limits the fault stress to
\SI{30.7}{\volt}. With \SI{20}{\percent} derating, require a
\SI{40}{\volt} rating. Each diode must recover before the next switching edge.

\paragraph{Cost.} Charge enters at the shelf potential and leaves at the
\SI{6.85}{\volt} rail. Thus, the loss is
$Q_{\mathrm{BIAS}}f_{\mathrm{sw}}(V_{\mathrm{shelf}}-\SI{6.85}{\volt})$.
Relative to a direct BIAS feed from $V_{\mathrm{BUS}}$, the increment is:
\begin{align*}
  I_{\mathrm{BIAS}} V_{\mathrm{refl}}
  &= \SI{6.56}{\milli\ampere} \times \SI{19.25}{\volt}
  = \SI{126}{\milli\watt},
\end{align*}
constant across the input window because the shelf tracks $V_{\mathrm{BUS}}$.
\des{C}{HVPUMP} redistributes that loss without changing it: a larger value
settles BIAS higher, moving dissipation out of \des{R}{HVPUMP} and into the
controller's internal regulator. At \SI{12.6}{\volt} in, the split is
\SI{89}{\milli\watt} inside the package and the remainder in \des{R}{HVPUMP}.
Gate charge reduces the overhead because the pump supplies it from the shelf
potential. \Cref{sec:hv-summary} includes this effect.

\subsection{Output voltage}\label{sec:hv-setpoint}

\subsubsection{Output setpoint}\label{sec:hv-ignition}

The IN-12B ignition voltage is at most \SI{170}{\volt}
(\cref{sec:in12b}). This value sets the minimum converter output. The INS-1
limit of \SI{90}{\volt} does not constrain the design. A
\SI{15}{\volt} margin gives an adjustment range of
\SIrange{170}{185}{\volt}. One fixed digit ballast cannot keep the current in
range across this full voltage span (\cref{sec:hv-load-digit}). Therefore,
\cref{sec:hv-divider-split} specifies matched ballast and \des{R}{HVD3} values.
The INS-1 has no rated current range. One ballast value serves all output
settings.

\subsubsection{Interpretation of the datasheet's 200/250~V anode-supply figures}\label{sec:hv-anode-figures}

The IN-12B datasheet specifies a minimum anode supply of \SI{200}{\volt}. It
recommends \SI{250}{\volt} DC. Both values exceed the derived range. These
values can apply to unfiltered half-wave AC (inferred). In that mode, the tube
ignites during each mains cycle and conducts near the voltage peak. The supply
then needs more peak voltage to give sufficient average current.

\subsubsection{Operating points used throughout this section}\label{sec:hv-points}

Two operating points recur, bracketing the trim range:
\begin{description}
  \item[Nominal] $V_{\mathrm{BUS}} = \SI{9}{\volt}$, the intermediate USB-PD
  contract; output at \SI{170}{\volt}, the IN-12B's guaranteed ignition ceiling
  (\cref{sec:hv-ignition}); tube currents at their expected values.
  \item[Design-max envelope] $V_{\mathrm{BUS}} = \SI{4.75}{\volt}$ (bottom of
    the input window, worst case for duty cycle and primary conduction), output
    at \SI{191.5}{\volt}, and every digit tube simultaneously at its
    datasheet-maximum \SI{3.5}{\milli\ampere}, which is what the widest-ballast
    row of \cref{tab:hv-ballast-divider} reaches at exactly that current.
\end{description}

In DCM, the energy packet sets peak current:
$I_{\mathrm{pk}} = \sqrt{2P_{\mathrm{in}}/(L_p f_{\mathrm{sw}})}$. Checks that
depend on input voltage use both limits. The \SI{4.75}{\volt} limit maximizes
duty cycle, conduction loss, and on time. The \SI{12.6}{\volt} limit maximizes
commutation voltage, reverse stress, and sense-current slew rate.

\paragraph{Achieved tuning range.}\label{sec:hv-achieved-range}
Select the digit ballast and feedback resistor together from
\cref{tab:hv-ballast-divider}. Each row maps the rated
\SIrange{2.5}{3.5}{\milli\ampere} current range to a different voltage range.
Thus, $V_{\mathrm{HV}}$ can be set from \SI{164.8}{\volt} to
\SI{191.5}{\volt}. Component stress checks use this full range. Functional
checks use the required \SIrange{170}{185}{\volt} range.

\subsection{Ballast sizing}\label{sec:hv-load}

\subsubsection{Digit tubes (NX1 to NX4, ballast \des{R}{BALDIG})}\label{sec:hv-load-digit}

Each IN-12B anode connects to $V_{\mathrm{HV}}$ through its ballast. The
selected cathode returns through a K155ID1 output. The rated DC cathode current
is $I_K \in \SIrange{2.5}{3.5}{\milli\ampere}$ (\cref{sec:in12b}). The ballast
equation is
\begin{align*}
  R_A &= \frac{V_{\mathrm{rail}} - V_M - V_K}{I_K},
\end{align*}
with maintaining voltage $V_M = \SI{145}{\volt}$ (typical, no tabulated spread;
\cref{sec:in12b}) and $V_K$ the K155ID1's on-state drop at the selected output.
The driver specifies a maximum $V_K$ of \SI{2.5}{\volt} at
\SI{7}{\milli\ampere} (\cref{sec:bcd-driver}). The operating current is less
than half this test current. Therefore, the analysis uses an expected
\SI{1.0}{\volt} drop (inferred). At the smallest ballast, a
\SI{1.5}{\volt} error changes current by approximately
\SI{0.20}{\milli\ampere}. This error is less than the
\SI{0.5}{\milli\ampere} half-width of the rated range.

One ballast value cannot keep the cathode current in its rated range across all
output settings. \Cref{sec:hv-divider-split} therefore gives matched ballast
and \des{R}{HVD3} values. For each row, $V_{\mathrm{min}}$ and
$V_{\mathrm{max}}$ give exactly \SI{2.5}{\milli\ampere} and
\SI{3.5}{\milli\ampere}. The trimmer end stops extend past both targets with
worst-case component tolerances.

The installed \des{R}{BALDIG} value is \SI{7.50}{\kilo\ohm}. The table also
defines permissible alternative values through \SI{13.00}{\kilo\ohm}. Each
alternative requires the matching \des{R}{HVD3}. Calculations that depend on the
design envelope cover the full table. Worst-case dissipation grows with $R_A$ at the shared
\SI{3.5}{\milli\ampere} rated maximum, so the largest entry bounds every row:
\begin{align*}
  I_K^2 R_A = 3.5^2 \times 13.00 \approx \SI{159}{\milli\watt},
\end{align*}
still well inside a DIN0207 axial part's $\approx\SI{0.6}{\watt}$ rating
($\approx$27\,\%).

The IN-12B decimal-point cathode has no driver signal and carries no current.

\subsubsection{Colon tubes (NX5 and NX6, ballast \des{R}{BALCOL})}\label{sec:hv-load-colon}

Each INS-1 anode connects to $V_{\mathrm{HV}}$ through its ballast. Its cathode
connects directly to ground. The colon tubes have no driver. They illuminate
when the high-voltage rail is on. The ballast equation has no driver drop. One
resistor value serves both tubes.

The INS-1 maintaining voltage is at most \SI{55}{\volt}
(\cref{sec:ins1}). Use of this limit gives the minimum calculated current. The
datasheet gives no operating-current range. It gives only a
\SI{0.5}{\milli\ampere} optimum brightness current. The ballast gives this
current at the \SI{177.5}{\volt} center of the output range:
\begin{align*}
  R_A &= \frac{\SI{177.5}{\volt} - \SI{55}{\volt}}{\SI{0.5}{\milli\ampere}}
       = \SI{245}{\kilo\ohm}.
\end{align*}
The nearest standard value is $\des{R}{BALCOL} = \SI{240}{\kilo\ohm}$. Current
spans \SIrange{0.479}{0.542}{\milli\ampere} across the required output range.
It spans \SIrange{0.458}{0.569}{\milli\ampere} across the full adjustment
range. These limits are $8.5\,\%$ below and $14\,\%$ above the optimum.

The datasheet does not give a minimum maintaining voltage. A lower maintaining
voltage increases current through a fixed ballast. For example, a
\SI{45}{\volt} maintaining voltage gives \SI{0.61}{\milli\ampere} at maximum
output. The datasheet gives no maximum current for comparison. Therefore, this
upper current is open.

\paragraph{Ballast tolerance.} \des{R}{BALCOL} has a $5\,\%$ tolerance. This
tolerance gives a current range of \SIrange{0.436}{0.599}{\milli\ampere}. The
datasheet gives no rated range that this variation can exceed. Two resistors at
opposite tolerance limits differ in current by \SI{10.5}{\percent}. A $1\,\%$
pair would differ by $2\,\%$. The datasheet does not relate this current
difference to brightness. A \SI{5}{\volt} difference in maintaining voltage
also causes a $4\,\%$ current difference at midrange. The visible colon
ballasts use carbon-film bodies as a construction preference.

\subsection{Feedback divider design}\label{sec:hv-divider}

\subsubsection{Divider current selection}\label{sec:hv-divider-current}

Two limits set the divider current.

\textbf{Power loss.} The divider loads $V_{\mathrm{HV}}$ whenever the converter
operates. A divider current that is 100 times less than the tube current has a
small power cost.

\textbf{Feedback-node impedance.} A high resistance increases error from FB
bias or leakage current. It also increases coupling from switching noise. The
datasheet gives no FB leakage value. The analysis assumes nanoampere-scale
leakage for this device class (inferred). A \SI{100}{\micro\ampere} divider
current makes this leakage negligible.

At the \SI{170}{\volt} reference point that sets a target total divider
resistance of $(170-1)\,\si{\volt}/\SI{100}{\micro\ampere} \approx
\SI{1.69}{\mega\ohm}$.

\subsubsection{Resistor split and trim range}\label{sec:hv-divider-split}

The divider is $R_{\mathrm{upper}}$ to FB to $R_{\mathrm{lower}}$ to ground.
Its equation is $V_{\mathrm{out}} =
V_{\mathrm{REF}}(1+R_{\mathrm{upper}}/R_{\mathrm{lower}})$. At
\SI{170}{\volt}, the required ratio is 169. The lower resistance is less than
$1\,\%$ of the total. It sets the adjustment range but has little effect on
divider current. Two equal upper resistors share the voltage stress
(\cref{sec:hv-divider-stress}). Therefore, $\des{R}{HVD1} =
\des{R}{HVD2} = \SI{845}{\kilo\ohm}$.

$R_{\mathrm{lower}}$ contains fixed resistor \des{R}{HVD3} and trimmer
\des{RV}{HVTRIM} in series. A \SI{2}{\kilo\ohm} trimmer reaches each row's
$V_{\min}$ and $V_{\max}$ with worst-case divider tolerances. Select
\des{R}{HVD3} so that all three targets remain inside the usable trimmer span.
Adjust the output by measurement.

\begin{table}[htbp]
\centering
\caption{Digit-ballast / \des{R}{HVD3} pairing table (component tolerances: \des{R}{HVD1}/\des{R}{HVD2}
    $\pm1\,\%$ each, \des{R}{HVD3} $\pm1\,\%$, $V_{\mathrm{REF}}$ $\pm1\,\%$,
    \des{RV}{HVTRIM} total resistance assumed $\pm10\,\%$, all stacked
    worst-case additive)}
\label{tab:hv-ballast-divider}
\begin{tabular}{|c|c|c|c|c|c|c|}
\hline
\textbf{$R_A$} & \textbf{$V_{\min}$} & \textbf{$V_{\mathrm{typ}}$} &
\textbf{$V_{\max}$} & \textbf{\des{R}{HVD3}} & \textbf{$V_{\mathrm{floor,wc}}$} &

\textbf{$V_{\mathrm{ceil,wc}}$} \\
(\si{\kilo\ohm}) & (\si{\volt}) & (\si{\volt}) & (\si{\volt}) &
(\si{\kilo\ohm}) & (\si{\volt}) & (\si{\volt}) \\
\hline
7.50  & 164.8 & 168.5 & 172.2 & 9.09 & 146.5 & 192.6 \\
\hline
8.20  & 166.5 & 170.6 & 174.7 & 8.87 & 149.4 & 197.3 \\
\hline
9.10  & 168.8 & 173.3 & 177.8 & 8.87 & 149.4 & 197.3 \\
\hline
10.00 & 171.0 & 176.0 & 181.0 & 8.66 & 152.3 & 202.1 \\
\hline
11.00 & 173.5 & 179.0 & 184.5 & 8.45 & 155.3 & 207.1 \\
\hline
12.00 & 176.0 & 182.0 & 188.0 & 8.25 & 158.3 & 212.1 \\
\hline
13.00 & 178.5 & 185.0 & 191.5 & 8.25 & 158.3 & 212.1 \\
\hline
\end{tabular}
\end{table}

$V_{\min}$, $V_{\mathrm{typ}}$, and $V_{\mathrm{max}}$ are adjustment targets.
They give \SIlist{2.5;3.0;3.5}{\milli\ampere} through the applicable ballast.
Measure the output and adjust it to a target. Divider tolerance does not change
these measured targets. $V_{\mathrm{floor,wc}}$ and
$V_{\mathrm{ceil,wc}}$ are calculated end-stop limits. Start with the
smallest-$R_A$ row. Use a larger ballast only if the installed tubes do not
ignite in that row's range.

\paragraph{User-guide requirement.} The hardware user guide must include
\cref{tab:hv-ballast-divider}. It must identify each row as an acceptable
ballast and \des{R}{HVD3} pair. It must require voltage adjustment with the
tubes removed. The end-stop values are informational. Adjustment to an end stop
is not permitted. The guide must also state that the trimmer range compensates
for component tolerance. The end stops are excluded from operating and stress
analyses.

Divider current at each row's nominal point ranges
\SIrange{99.1}{108.9}{\micro\ampere}, matching the \SI{100}{\micro\ampere}
target of \cref{sec:hv-divider-current} across the whole table.

\subsubsection{Divider element stress}\label{sec:hv-divider-stress}

\des{R}{HVD1} and \des{R}{HVD2} split $(V_{\mathrm{out}}-1)$ evenly:
\SI{84.5}{\volt} each at the \SI{170}{\volt} reference point, \SI{95.25}{\volt}
at the \SI{191.5}{\volt} design-max envelope (\cref{sec:hv-achieved-range}),
against the \SI{250}{\volt} limiting element voltage of the specified DIN0207
axial metal film parts. Dissipation is $95.25^2/\SI{845}{\kilo\ohm} =
\SI{10.7}{\milli\watt}$. \des{R}{HVD3} and \des{RV}{HVTRIM} see about
\SI{1}{\volt}.

\subsection{Aggregate current and power budget}\label{sec:hv-budget}

The bleeder \des{R}{HVBLEED} completes the load list at \SI{1.5}{\mega\ohm},
sized in \cref{sec:hv-bleeder} against the output-discharge and minimum-load
requirements.

{\footnotesize
\begin{table}[htbp]
\centering
\caption{$V_{\mathrm{HV}}$: aggregate anode current budget}\label{tab:hv-current-budget}
\begin{tabular}{|l|r|r|}
\hline
\textbf{Load element} & \textbf{Nominal (\SI{170}{\volt})} & \textbf{Design-max (\SI{191.5}{\volt})} \\
\hline
NX1 to NX4 digit cathodes & $4 \times 3.20 = \SI{12.80}{\milli\ampere}$
  & $4 \times 3.50 = \SI{14.00}{\milli\ampere}$ \\
\hline
NX5 and NX6 colon anodes & $2 \times 0.479 = \SI{0.96}{\milli\ampere}$
  & $2 \times 0.569 = \SI{1.14}{\milli\ampere}$ \\
\hline
Bleeder \des{R}{HVBLEED} (\SI{1.5}{\mega\ohm}) & \SI{0.11}{\milli\ampere} & \SI{0.13}{\milli\ampere} \\

\hline
Feedback divider ($\approx\SI{1.70}{\mega\ohm}$) & \SI{0.10}{\milli\ampere} & \SI{0.11}{\milli\ampere} \\
\hline
Total $I_{\mathrm{out}}$ & \SI{13.97}{\milli\ampere} & \SI{15.38}{\milli\ampere} \\
\hline
$P_{\mathrm{out}} = V_{\mathrm{out}} I_{\mathrm{out}}$ & \SI{2.38}{\watt} & \SI{2.94}{\watt} \\
\hline
\end{tabular}
\end{table}
}

The nominal-point digit and colon currents follow from the specified ballast
values (\cref{sec:hv-load-digit,sec:hv-load-colon}) at \SI{170}{\volt}; the
divider's \SI{0.10}{\milli\ampere} is under 1\,\% of total output current at
either operating point, as \cref{sec:hv-divider-current} assumed.

\textbf{The maximum-design point can occur.} With a
\SI{13.00}{\kilo\ohm} ballast and a \SI{191.5}{\volt} output, each digit tube
draws \SI{3.5}{\milli\ampere}. Thus, all four tubes can operate at their rated
maximum current at the same time. The INS-1 has no rated maximum current
(\cref{sec:ins1}).

\subsection{Operating point and efficiency}\label{sec:hv-op}

\subsubsection{Component values for the loss model}\label{sec:hv-op-inputs}

The loss model uses the following values. Their cross-referenced sections
derive them from the converged peak current.
\begin{itemize}[nosep]
  \item \des{Q}{HVSW} is an IRL540N-type commodity through-hole logic-level power MOSFET;
  \item $\des{R}{HVGON} = \SI{10}{\ohm}$, governing turn-on;
  \item \des{D}{HVGOFF} (SB240S-E3/54) and $\des{R}{HVGOFF} = \SI{3.3}{\ohm}$,
    the turn-off speedup network, sized in
    \cref{sec:hv-op-losses,sec:hv-switch};
  \item $\des{R}{HVCS} = \SI{39}{\milli\ohm}$, the current-sense resistor,
    derived in \cref{sec:hv-cs};
  \item $\des{R}{HVCL} = \SI{30}{\kilo\ohm}$, $\des{C}{HVCL} =
    \SI{12}{\nano\farad}$, the RCD clamp network, sized in
    \cref{sec:hv-clamp}.
\end{itemize}

\subsubsection{Loss mechanisms}\label{sec:hv-op-losses}

In DCM, the converter transfers a fixed magnetizing-energy packet in each
cycle:
\begin{align*}
  P_{\mathrm{in}} = \tfrac{1}{2} L_p I_{\mathrm{pk}}^2 f_{\mathrm{sw}}
  \quad\Longrightarrow\quad
  I_{\mathrm{pk}} = \sqrt{\frac{2 P_{\mathrm{in}}}{L_p f_{\mathrm{sw}}}},
  \qquad
  P_{\mathrm{in}} = \frac{P_{\mathrm{out}}}{\eta}.
\end{align*}
Calculate efficiency by iteration. Start with an efficiency value. Calculate
$P_{\mathrm{in}}$ and $I_{\mathrm{pk}}$. Then calculate each loss and update
the efficiency. Repeat these calculations until they converge. The loss models
are as follows.
\begin{description}[style=nextline]
  \item[Primary conduction] Triangular current over $t_{\mathrm{on}}$:
    $I_{\mathrm{rms}} = I_{\mathrm{pk}}\sqrt{D/3}$ through
    $R_{DS(\mathrm{on})} + \des{R}{HVCS} + R_{\mathrm{DCR,pri}}
     = 55 + 39 + 13 = \SI{107}{\milli\ohm}$. The datasheet tabulates
    $R_{DS(\mathrm{on})}$ at only two $V_{GS}$ points, both at
    $T_J=\SI{25}{\celsius}$: \SI{53}{\milli\ohm} at $V_{GS}=\SI{5.0}{\volt}$ and
    \SI{44}{\milli\ohm} at $V_{GS}=\SI{10}{\volt}$
    (\ds{infineon-irl540n-datasheet-en.pdf}{2}), so interpolating to the
    \SI{6.85}{\volt} gate rail gives a cold value of
    $\approx\SI{49.7}{\milli\ohm}$. It then rises with junction temperature
    (\ds{infineon-irl540n-datasheet-en.pdf}{3}, Fig.\,4, read as a linear
    approximation between its $1.0\times$-at-\SI{25}{\celsius} and
    $2.4\times$-at-\SI{175}{\celsius} anchors), which \des{Q}{HVSW}'s own
    dissipation sets. Solved self-consistently against the design-max loss
    budget below (\SI{25}{\celsius} ambient assumed), the converged point is
    $T_J \approx \SI{37}{\celsius}$, $R_{DS(\mathrm{on})} \approx
    \SI{55}{\milli\ohm}$.

  \item[Turn-off overlap]
    The IRL540N datasheet (\ds{infineon-irl540n-datasheet-en.pdf}{2}) specifies
    the gate-drain (Miller) charge only as a guaranteed maximum, $Q_{GD} \le
    \SI{38}{\nano\coulomb}$, with no typical value tabulated; its gate-charge
    curve (\ds{infineon-irl540n-datasheet-en.pdf}{4}, Fig.\,6) shows the Miller
    plateau sitting at $V_{\mathrm{plateau}} \approx \SI{3}{\volt}$. The same
    datasheet's resistive-load switching-time table gives $t_f =
    \SI{62}{\nano\second}$ typical at its own test condition
    ($R_G=\SI{5.0}{\ohm}$, $V_{GS}$ pulse $=\SI{5.0}{\volt}$), which implies a
    typical $Q_{GD} \approx t_f \times (5.0-3.0)/5.0\,\si{\ohm} \approx
    \SI{25}{\nano\coulomb}$ at that test point. The LM51561H's output stage adds
    an internal pull-down resistance in series with $\des{R}{HVGON}$. Its datasheet
    (\ds{lm5156h.pdf}{6}, MOSFET DRIVER) gives the low-state output's voltage
    drop under an externally forced \SI{100}{\milli\ampere} as \SI{0.15}{\volt},
    implying $R_{\mathrm{int}} \approx \SI{1.5}{\ohm}$ for this pull-down path
    (the table's two rows are ambiguous about which pin state pairs with
    which current direction, so this is the best available reading).
    Turn-off overlap dominates the loss budget, so that edge is given a faster
    discharge path of its own. \des{D}{HVGOFF} in series with
    \des{R}{HVGOFF} bypasses $\des{R}{HVGON}$ for the discharge direction only:
    its anode sits at the gate, its cathode at the
    $\des{R}{HVGON}$/driver-output node, so it blocks during turn-on, leaving
    that edge unchanged, and conducts during turn-off. \des{R}{HVGOFF} is sized
    against the driver's \SI{1.5}{\ampere} peak source/sink capability
    (\ds{lm5156h.pdf}{29}), the binding current being the brief pre-plateau
    discharge from the fully-enhanced gate, which exceeds the plateau current:
    \begin{align*}
      I_{\mathrm{gate}}^{\mathrm{peak}} &= \frac{V_{\mathrm{drive}} -
        V_{F(\des{D}{HVGOFF})}}{\des{R}{HVGOFF} + R_{\mathrm{int}}}
        = \frac{6.85 - 0.5}{3.3+1.5} \approx \SI{1.32}{\ampere}
        \quad (88\,\% \text{ of the } \SI{1.5}{\ampere} \text{ rating}),
    \end{align*}
    using $V_{F(\des{D}{HVGOFF})} \approx \SI{0.5}{\volt}$, interpolated below
    the sole tabulated point ($\SI{0.55}{\volt}$ at \SI{2}{\ampere}). The
    \SI{12}{\percent} headroom rests on that interpolation and on the
    $R_{\mathrm{int}}$ estimate; both are derived, neither measured.
    At the lower Miller-plateau voltage, the turn-off gate current is
    $I_{\mathrm{gate}} = (6.85-3.0-0.5)/(3.3+1.5) \approx \SI{698}{\milli\ampere}$,
    giving
    \begin{align*}
      t_{\mathrm{ovl}}^{\mathrm{typ}} &= \frac{Q_{GD}^{\mathrm{typ}}}{I_{\mathrm{gate}}}
        \approx \SI{36}{\nano\second}, &
      t_{\mathrm{ovl}}^{\max} &= \frac{Q_{GD}^{\max}}{I_{\mathrm{gate}}}
        \approx \SI{54}{\nano\second}.
    \end{align*}
    With the commutation voltage $V_{\mathrm{com}} = V_{\mathrm{BUS}} +
    V_{\mathrm{refl}}$, $E_{\mathrm{off}} \approx \tfrac{1}{2} I_{\mathrm{pk}}
    V_{\mathrm{com}} t_{\mathrm{ovl}}$. The convergence below uses
    $t_{\mathrm{ovl}}^{\mathrm{typ}}$; \cref{sec:hv-switch} checks
    \des{Q}{HVSW}'s dissipation at $t_{\mathrm{ovl}}^{\max}$. Turn-on is
    near-lossless in DCM (zero current; $C_{oss}$ discharge contributes a few
    milliwatts) and is governed by $\des{R}{HVGON}$ alone.
    \item[Gate drive and controller]
    $P = (Q_G f_{\mathrm{sw}} + I_Q)(V_{\mathrm{BUS}} + V_{\mathrm{refl}})$
    with $Q_G \approx \SI{40}{\nano\coulomb}$ at the \SI{6.85}{\volt} VCC rail
    (scaled from the \SI{10}{\volt} datasheet point, inferred) and controller
    operating current $I_Q \le \SI{580}{\micro\ampere}$ (\ds{lm5156h.pdf}{5}). Gate
    charge is drawn through the internal VCC regulator from BIAS, which the
    charge pump of \cref{sec:hv-house-pump} lifts from the switch node, so the
    charge is drawn at the reflected shelf, well above $V_{\mathrm{BUS}}$. It is
    the largest single term in the budget below.

  \item[RCD clamp] Leakage energy $\tfrac{1}{2} L_{\mathrm{lk}} I_{\mathrm{pk}}^2$
    per cycle, dissipated in \des{R}{HVCL} with the clamp-voltage multiplier
    derived in \cref{sec:hv-clamp}.
  \item[Rectifier] $V_F \approx \SI{1.0}{\volt}$ (ultrafast-diode class figure at
    $\sim$\SI{0.2}{\ampere}) times $I_{\mathrm{out}}$; recovery loss is negligible
    because in DCM the secondary current reaches zero before the switch turns on.
  \item[Secondary conduction] $I_{s,\mathrm{rms}}^2 \times \SI{1.60}{\ohm}$ DCR.
  \item[Capacitor ESR] Input $\approx\SI{40}{\milli\ohm}$ and output
  $\approx\SI{0.5}{\ohm}$, both the polymer parts' own; \des{C}{HVI2}'s
  impedance stays above the input figure below \SI{850}{\kilo\hertz}, past the
  ripple's dominant harmonics.
  \item[Core] Uncharacterized at this frequency; a \SI{50}{\milli\watt} allowance
    is carried.
\end{description}

\subsubsection{Converged operating point (design-max envelope)}\label{sec:hv-op-converge}

Iterating at the design-max envelope ($P_{\mathrm{out}} = \SI{2.94}{\watt}$,
$V_{\mathrm{BUS}} = \SI{4.75}{\volt}$, $V_{\mathrm{out}} = \SI{191.5}{\volt}$,
reflected voltage $V_{\mathrm{refl}} = (191.5+1)/10 = \SI{19.25}{\volt}$,
$t_{\mathrm{ovl}} = t_{\mathrm{ovl}}^{\mathrm{typ}} = \SI{36}{\nano\second}$),
the loop converges to $\eta = \SI{83.3}{\percent}$:
\begin{align*}
  P_{\mathrm{in}} &= \frac{2.945}{0.833} = \SI{3.54}{\watt}, &
  E_{\mathrm{cyc}} &= \frac{3.54}{149.4\times10^{3}} = \SI{23.7}{\micro\joule},\\
  I_{\mathrm{pk}} &= \sqrt{\frac{2 \times 23.7\,\si{\micro\joule}}
  {\SI{10}{\micro\henry}}} = \SI{2.18}{\ampere}, &
  t_{\mathrm{on}} &= \frac{L_p I_{\mathrm{pk}}}{V_{\mathrm{BUS}}}
                   = \frac{10\,\si{\micro\henry} \times 2.18}{4.75}
                   = \SI{4.58}{\micro\second},\\
                   D &= t_{\mathrm{on}} f_{\mathrm{sw}} = 0.68, &
                   I_{\mathrm{rms,pri}} &= I_{\mathrm{pk}}\sqrt{D/3} = \SI{1.04}{\ampere},\\
                   I_{\mathrm{in}} &= \frac{P_{\mathrm{in}}}{V_{\mathrm{BUS}}}
                   = \SI{744}{\milli\ampere}.
\end{align*}
Converged loss budget at this point:

{\footnotesize
\begin{table}[htbp]
\centering
\caption{170~V flyback converter: loss budget at the design-max envelope}\label{tab:hv-loss-budget}
\begin{tabular}{|l|r|}
\hline
\textbf{Mechanism} & \textbf{Loss} \\
\hline
Bias draw through the charge pump (\cref{sec:hv-house-pump}) & \SI{157}{\milli\watt} \\

\hline
MOSFET turn-off overlap ($t_{\mathrm{ovl}}=\SI{36}{\nano\second}$) & \SI{140}{\milli\watt} \\

\hline
Primary conduction (FET 60, \des{R}{HVCS} 42, DCR 14) & \SI{116}{\milli\watt} \\

\hline
RCD clamp (\des{R}{HVCL}) & \SI{86}{\milli\watt} \\

\hline
Core allowance (uncharacterized) & \SI{50}{\milli\watt} \\
\hline
Capacitor ESR (input + output) & \SI{22}{\milli\watt} \\

\hline
Rectifier \des{D}{HVRECT} conduction & \SI{15}{\milli\watt} \\

\hline
Secondary DCR & \SI{4}{\milli\watt} \\
\hline
Total & \SI{590}{\milli\watt} \\

\hline
$\eta = 2.945/(2.945+0.590)$ & \SI{83.3}{\percent} \\

\hline
\end{tabular}
\end{table}
}

\paragraph{Efficiency curve.}\label{sec:hv-op-curve}
The charge pump holds the gate rail constant (\cref{sec:hv-house-pump}).
Turn-off overlap and bias loss increase with
$V_{\mathrm{BUS}} + V_{\mathrm{refl}}$. Together, they increase from
\SI{297}{\milli\watt} to \SI{400}{\milli\watt}. Primary conduction and
capacitor ESR decrease with duty cycle. Together, they decrease from
\SI{138}{\milli\watt} to \SI{57}{\milli\watt}. The other modeled losses total
\SI{155}{\milli\watt}. The total loss is
$A(V_{\mathrm{BUS}}+V_{\mathrm{refl}})+B/V_{\mathrm{BUS}}+C$. Here,
$A=\SI{12.4}{\milli\watt\per\volt}$ and
$B=\SI{683}{\milli\watt\volt}$. The minimum occurs at
$\sqrt{B/A}=\SI{7.4}{\volt}$:

{\footnotesize
  \begin{table}[htbp]
    \centering
    \caption{Design-max efficiency across the input window}\label{tab:hv-eta-line}
    \begin{tabular}{|l|c|c|c|c|c|}
      \hline
      $V_{\mathrm{BUS}}$ & \SI{4.75}{\volt} & \SI{7}{\volt} & \SI{9}{\volt} &
      \SI{11}{\volt} & \SI{12.6}{\volt} \\
      \hline
      Duty & 0.68 & 0.46 & 0.36 & 0.30 & 0.26 \\
      \hline
      Total loss & \SI{590}{\milli\watt} & \SI{578}{\milli\watt} &
      \SI{583}{\milli\watt} & \SI{596}{\milli\watt} & \SI{610}{\milli\watt} \\
      \hline
      $\eta$ & \SI{83.3}{\percent} & \SI{83.6}{\percent} & \SI{83.5}{\percent} &
      \SI{83.2}{\percent} & \SI{82.8}{\percent} \\
      \hline
    \end{tabular}
  \end{table}
}

The convergence above uses $t_{\mathrm{ovl}}^{\mathrm{typ}}$; across the
\SIrange{36}{54}{\nano\second} spread the design-max efficiency band runs
\SIrange{81.4}{83.3}{\percent}. \Cref{sec:hv-switch} checks \des{Q}{HVSW}'s
dissipation at $t_{\mathrm{ovl}}^{\max}$, and \cref{sec:hv-cs-sense} folds the
same spread into its current-limit margin as a tolerance term.

The two largest losses depend on the \des{Q}{HVSW} gate charge. Bias loss
depends on $Q_G$. Turn-off overlap depends on $Q_{GD}$. Together, these losses
are \SI{297}{\milli\watt} of the \SI{590}{\milli\watt} total. Both values are
derived. Measure converter efficiency to verify this loss model.

\subsubsection{Nominal-point efficiency}\label{sec:hv-op-nominal}

The same procedure at the nominal point ($\SI{2.38}{\watt}$, \SI{170}{\volt})
gives, at each contract:

{\footnotesize
  \begin{table}[htbp]
    \centering
    \caption{Nominal-point ($\SI{2.38}{\watt}$, \SI{170}{\volt}) operating figures}\label{tab:hv-nominal-line}
    \begin{tabular}{|l|c|c|c|}
      \hline
      $V_{\mathrm{BUS}}$ & \SI{4.75}{\volt} & \SI{9}{\volt} & \SI{12.6}{\volt} \\
      \hline
      $\eta$ & \SI{82.7}{\percent} & \SI{82.5}{\percent} & \SI{81.7}{\percent} \\
      \hline
      $P_{\mathrm{in}}$ & \SI{2.87}{\watt} & \SI{2.88}{\watt} & \SI{2.91}{\watt} \\
      \hline
      $I_{\mathrm{pk}}$ & \SI{1.96}{\ampere} & \SI{1.96}{\ampere} & \SI{1.97}{\ampere} \\
      \hline
      Duty & 0.62 & 0.33 & 0.23 \\
      \hline
      $I_{\mathrm{rms,pri}}$ & \SI{0.89}{\ampere} & \SI{0.65}{\ampere} & \SI{0.55}{\ampere} \\
      \hline
      $I_{\mathrm{in}}$ average & \SI{605}{\milli\ampere} & \SI{320}{\milli\ampere} &
      \SI{231}{\milli\ampere} \\
      \hline
    \end{tabular}
  \end{table}
}

Nominal efficiency is lower than maximum-load efficiency. The main losses are
proportional to $\sqrt{P}$. Bias current does not decrease with load. Therefore,
the \SIrange{143}{195}{\milli\watt} bias loss is a larger fraction of the
\SI{2.38}{\watt} nominal output. The nominal efficiency is
0.6 to 1.1 percentage points lower than the maximum-load efficiency.

The $I_{\mathrm{in}}$ row is what \cref{sec:hv-inhibit}'s current test is against.
A \SI{5}{\volt} contract must carry \SI{605}{\milli\ampere} at the nominal point
and \SI{744}{\milli\ampere} at the design-max envelope, so a
\SI{3}{\ampere} \SI{5}{\volt} contract qualifies and a default
\SI{500}{\milli\ampere} port does not.

\subsubsection{Peak current at minimum inductance}\label{sec:hv-op-lmin}

With the minimum-tolerance inductance ($L_p = \SI{9}{\micro\henry}$ at rated peak
current, \cref{sec:da2032}), the same energy packet requires
\begin{align*}
  I_{\mathrm{pk}}^{(L\min)} &= \sqrt{\frac{2 \times 23.7\,\si{\micro\joule}}
                                          {\SI{9}{\micro\henry}}}
                             = \SI{2.29}{\ampere},
\end{align*}
the worst-case commanded peak used in \cref{sec:hv-cs}.

\subsection{DCM verification}\label{sec:hv-dcm}

DCM requires $t_{\mathrm{on}} + t_{\mathrm{dem}} < T$. The remaining time must
include the drain ring-down. For the 1:10 turns ratio, the demagnetization time
is
\begin{align*}
  t_{\mathrm{dem}} &= \frac{n L_p I_{\mathrm{pk}}}{V_{\mathrm{out}} + V_F}.
\end{align*}
The binding corner maximizes $t_{\mathrm{on}} + t_{\mathrm{dem}}$: maximum
inductance ($\SI{11}{\micro\henry}$, $+10\,\%$), minimum input
(\SI{4.75}{\volt}), design-max load:
\begin{align*}
  I_{\mathrm{pk}} &= \sqrt{\frac{2\times23.7\,\si{\micro\joule}}{\SI{11}{\micro\henry}}}
  = \SI{2.07}{\ampere},\\
  t_{\mathrm{on}} &= \frac{11\,\si{\micro\henry}\times 2.07}{4.75}
  = \SI{4.80}{\micro\second}, &
  t_{\mathrm{dem}} &= \frac{10 \times 11\,\si{\micro\henry} \times 2.07}{192.5}
  = \SI{1.19}{\micro\second},\\
  t_{\mathrm{on}} + t_{\mathrm{dem}} &= \SI{5.99}{\micro\second}
  = 0.89\,T, &
  t_{\mathrm{idle}} &= \SI{0.71}{\micro\second}.
\end{align*}

\textbf{DCM has a minimum idle fraction of $10.5\,\%$.} The secondary circuit
sets demagnetization time, which does not depend on input voltage. On time is
inversely proportional to $V_{\mathrm{BUS}}$. Therefore, minimum input gives
the smallest idle fraction. At \SI{12.6}{\volt}, duty falls to 0.26. A lighter
load also increases the idle fraction.

CCM operation invalidates the energy-packet loss model and the single-pole
plant in \cref{sec:hv-comp}. It also invalidates the rectifier-recovery and
slope-compensation conclusions. The \SI{0.71}{\micro\second} idle time can end
during drain ring-down. This timing adds only a few milliwatts because DCM
turn-on current is zero.

The 0.72 duty cycle does not cause subharmonic oscillation in DCM. The
$D>0.5$ threshold applies to CCM. In DCM, the current returns to zero during
each cycle. Therefore, the design does not require $R_{SL}$
(\cref{sec:hv-cs}).

Duty at the worst corner remains under the controller's $\approx$0.91 maximum
near this frequency, and $t_{\mathrm{on}} \ge \SI{4.8}{\micro\second}$ is well
above the $\approx\SI{165}{\nano\second}$ minimum on-time (\cref{sec:lm5156h}).

\subsection{Current sensing and current limit}\label{sec:hv-cs}

\subsubsection{CS filter}\label{sec:hv-cs-filter}

With the \SI{100}{\milli\volt} (93 to 107) current-limit threshold of
\cref{sec:lm5156h} and \des{R}{HVCS} $= \SI{39}{\milli\ohm}$ (declared in
\cref{sec:hv-op-inputs}):
\begin{align*}
  I_{\mathrm{lim}}^{\mathrm{typ}} &= \frac{\SI{100}{\milli\volt}}{\SI{39}{\milli\ohm}}
    = \SI{2.56}{\ampere},\\
  I_{\mathrm{lim}}^{\min} &= \frac{\SI{93}{\milli\volt}}{39\,\si{\milli\ohm}\times1.01}
    = \SI{2.36}{\ampere}, &
  I_{\mathrm{lim}}^{\max} &= \frac{\SI{107}{\milli\volt}}{39\,\si{\milli\ohm}\times0.99}
    = \SI{2.77}{\ampere}.
\end{align*}
The CS pin connects to the sense node through \des{R}{HVCSF}.
\des{C}{HVCSF} connects the pin to ground. The circuit does not use $R_{SL}$.
Thus, the current-limit threshold does not depend on duty cycle. The minimum
on-time and off-time criteria have large margins. Two other requirements set
$\tau = \des{R}{HVCSF}\des{C}{HVCSF}$.

\textbf{Upper limit: current-limit error.} The filter delays the sampled current
by $\Delta I_{\mathrm{delay}} = (V_{\mathrm{BUS}}/L_p)\,\tau$. Current continues
to increase during this delay. Limit the increase to half of the current-limit
tolerance range, or \SI{0.205}{\ampere}:
\begin{align*}
  \tau < \frac{\SI{0.205}{\ampere}}{(V_{\mathrm{BUS}}/L_p)_{\max}}
       = \frac{\SI{0.205}{\ampere}}{\SI{1.40}{\ampere\per\micro\second}}
       = \SI{146}{\nano\second},
\end{align*}
evaluated at the fastest observed slope (\SI{12.6}{\volt}, \SI{9}{\micro\henry}).

\textbf{Lower limit: spike attenuation.} Gate current and $C_{oss}$ discharge
cause a turn-on current spike. The spike duration is tens of nanoseconds
(inferred). The filter time constant must be comparable to this duration.

$\des{R}{HVCSF} = \SI{100}{\ohm}$ and
$\des{C}{HVCSF} = \SI{470}{\pico\farad}$. Both values are in the TI
recommended ranges. Their time constant is
\begin{align*}
  \tau = \des{R}{HVCSF}\des{C}{HVCSF} = 100 \times 470\,\si{\pico\farad} = \SI{47}{\nano\second},
\end{align*}
This value is comparable to the inferred spike duration. It is less than the
\SI{146}{\nano\second} maximum. The resulting current error is approximately
\SI{66}{\milli\ampere}. A \SI{50}{\nano\second} comparator and driver delay
(inferred) adds \SI{70}{\milli\ampere}. The total overshoot is approximately
\SI{0.14}{\ampere}.
\Cref{sec:hv-cs-sense} uses this value.

\subsubsection{Sense resistor and limit thresholds}\label{sec:hv-cs-sense}

\des{R}{HVCS} carries the switch current to ground; with the current-limit
thresholds of \cref{sec:hv-cs-filter} and the filter's overshoot $\Delta I_{\mathrm{ovs}}
\approx \SI{0.14}{\ampere}$, the sense resistor must satisfy two opposing
constraints:
\begin{align*}
  \text{power delivery:}\quad
    R_{S} &< \frac{\SI{93}{\milli\volt}}{1.01 I_{\mathrm{pk}}^{(L\min)}}
          = \frac{93\,\si{\milli\volt}}{1.01\times2.29\,\si{\ampere}} = \SI{40.2}{\milli\ohm},\\
  \text{core protection:}\quad
    R_{S} &> \frac{\SI{107}{\milli\volt}}{0.99(I_{\mathrm{sat}} - \Delta I_{\mathrm{ovs}})}
          = \frac{107\,\si{\milli\volt}}{0.99(3.0 - 0.14)\,\si{\ampere}} = \SI{37.8}{\milli\ohm},
\end{align*}
a \SI{2.4}{\milli\ohm} nominal window; neither bound depends on
$V_{\mathrm{out}}$. \SI{39}{\milli\ohm} (declared in \cref{sec:hv-op-inputs})
sits inside it, \SI{1.2}{\milli\ohm} under the power-delivery ceiling and
\SI{1.2}{\milli\ohm} above the core-protection floor. Both bounds are
worst-case-additive: minimum datasheet threshold, \des{R}{HVCS} at its own
tolerance extreme, and, on the power-delivery side, $L_p$ at its $-10\,\%$
extreme, all stacked simultaneously in the same direction.

\SI{39}{\milli\ohm} is the only standard value in this range.

\textbf{Tolerance combination.} An insufficient margin causes the current
limit to end a switching cycle early. The result is reduced output energy and
display brightness. It does not cause component damage. Therefore, this check
also uses a root-sum-square (RSS) tolerance combination. Turn-off overlap is an
independent part-to-part variation. Include it in the RSS calculation.

The nominal margin is $M_{\mathrm{nom}}=\SI{0.389}{\ampere}$. It uses
$\SI{100}{\milli\volt}/\SI{39}{\milli\ohm}$ and nominal $L_p$. It also uses
the typical turn-off overlap. The individual changes are:
\begin{align*}
  \Delta_{\mathrm{threshold}} &= \SI{-0.180}{\ampere}, &
  \Delta_{R_S} &= \SI{-0.025}{\ampere}, &
  \Delta_{L_p} &= \SI{-0.118}{\ampere}, &
  \Delta_{t_{\mathrm{ovl}}} &= \SI{-0.026}{\ampere}.
\end{align*}
Worst-case-additive sums these directly: $M_{\mathrm{wc}} = 0.389 - 0.180 - 0.025
- 0.118 - 0.026 = \SI{+0.040}{\ampere}$ ($+1.7\,\%$ of $I_{\mathrm{lim,min}}$).
RSS combines the same four in quadrature:
\begin{align*}
  M_{\mathrm{RSS}} &= M_{\mathrm{nom}} - \sqrt{\Delta_{\mathrm{threshold}}^2 +
    \Delta_{R_S}^2 + \Delta_{L_p}^2 + \Delta_{t_{\mathrm{ovl}}}^2}
    = 0.389 - 0.218 = \SI{+0.171}{\ampere}
    \quad (+7.2\,\% \text{ of } I_{\mathrm{lim,min}}),
\end{align*}
The threshold specification dominates the combination. \textbf{The RSS treatment
is scoped to this one check}; every voltage- and thermal-rating margin elsewhere
remains worst-case-additive, because those checks guard against destructive
outcomes.

Both tolerance methods give a positive margin. The additive margin is
$1.7\,\%$. The RSS margin is $7.2\,\%$. The bias current decreases this margin
because it increases input power and commanded peak current.

\paragraph{What hiccup changes about that.}\label{sec:hv-cs-hiccup}
On the LM51561H, sixty-four \emph{consecutive} limited cycles trip the fault
timer (\cref{sec:hv-ss}), after which the converter stops for
\SI{219}{\milli\second} and retries. A board that exhausts this margin at the
top of its trim range on a \SI{5}{\volt} contract blinks at roughly
\SI{4.6}{\hertz}.

The fault requires 64 consecutive limited cycles. Eight unlimited cycles reset
the counter. Thus, intermittent limiting does not cause hiccup. Continuous
limiting requires the maximum load and output setting. A lower output setting
or a larger ballast decreases peak current.

\textbf{The hardware user guide must include this condition.} If the display
blinks at maximum adjustment on a \SI{5}{\volt} supply, decrease the output.
Alternatively, install a larger ballast. Measure current limit with the
selected transformer to verify the calculated margin.

On the other side, the maximum clamped peak plus overshoot reaches
$2.77 + 0.14 = \SI{2.91}{\ampere}$ against the \SI{3.0}{\ampere} transformer
rating: a 3\,\% margin, acceptable because the \SI{3.0}{\ampere} figure is a
soft-saturation point, with $L$ already specified at \SI{9}{\micro\henry}
there.

\des{R}{HVCS} dissipation is $I_{\mathrm{rms}}^2 R_S = 1.04^2 \times 0.039 =
\SI{42}{\milli\watt}$ at the design-max envelope, trivial in a 2512.

\subsection{RCD clamp}\label{sec:hv-clamp}

At turn-off, the leakage inductance carries $I_{\mathrm{pk}}$. This inductance
is not coupled to the secondary. \des{D}{HVCL} directs its current into
\des{C}{HVCL}. \des{R}{HVCL} discharges the capacitor between cycles. The
network returns to $V_{\mathrm{BUS}}$. Thus, \des{C}{HVCL} withstands only
$V_{\mathrm{cl}}$. The resistor also returns the discharged energy to the input
rail.

\subsubsection{Leakage energy and the sizing current}

Per cycle the leakage inductance delivers $E_{\mathrm{lk}} = \tfrac{1}{2}
L_{\mathrm{lk}} I_{\mathrm{pk}}^2$ into the clamp. Two currents matter:
\begin{itemize}[nosep]
  \item \textbf{Normal design-max operation}, $I_{\mathrm{pk}} =
    \SI{2.18}{\ampere}$ (\cref{sec:hv-op-converge}):
    $E_{\mathrm{lk}} = \tfrac{1}{2}\times\SI{0.15}{\micro\henry}\times 2.18^2
    \approx \SI{0.355}{\micro\joule}$, $E_{\mathrm{lk}} f_{\mathrm{sw}}
    \approx \SI{53.0}{\milli\watt}$. This sets the clamp's steady dissipation
    carried in the loss budget (\cref{sec:hv-op-losses}).
  \item \textbf{Worst case}: the current limit bounds the current at turn-off,
    so the sizing case is the guaranteed-maximum
    clamped peak including the CS filter's overshoot, \SI{2.91}{\ampere}
    (\cref{sec:hv-cs-sense}). Hiccup bounds how long the converter holds that
    peak (\cref{sec:hv-ss}) but not the peak itself.
    $E_{\mathrm{lk}} = \tfrac{1}{2}\times\SI{0.15}{\micro\henry}\times 2.91^2
    \approx \SI{0.635}{\micro\joule}$, $E_{\mathrm{lk}} f_{\mathrm{sw}}
    \approx \SI{94.9}{\milli\watt}$.
\end{itemize}
Clamp sizing controls the \des{Q}{HVSW} drain-voltage rating. Thus, it uses the
worst-case current. The loss budget uses the normal maximum-load current.

\subsubsection{Clamp energy multiplier}

The clamp absorbs more than the leakage energy. While \des{D}{HVCL} conducts,
the leakage current decreases linearly from $I_{\mathrm{pk}}$ to zero. The
driving voltage is $V_{\mathrm{cl}}-V_{\mathrm{refl}}$. Here,
$V_{\mathrm{refl}}=\SI{19.25}{\volt}$ (\cref{sec:hv-op-converge}):
\begin{align*}
  t_1 = \frac{L_{\mathrm{lk}} I_{\mathrm{pk}}}{V_{\mathrm{cl}} - V_{\mathrm{refl}}}.
\end{align*}
The delivered charge is $Q_{\mathrm{cl}}=\tfrac{1}{2}I_{\mathrm{pk}}t_1$.
It enters the clamp at $V_{\mathrm{cl}}$:
\begin{align*}
  E_{\mathrm{cl}} = V_{\mathrm{cl}} Q_{\mathrm{cl}}
    = \tfrac{1}{2} L_{\mathrm{lk}} I_{\mathrm{pk}}^2 \cdot
      \frac{V_{\mathrm{cl}}}{V_{\mathrm{cl}} - V_{\mathrm{refl}}}
    = E_{\mathrm{lk}} \cdot
      \frac{V_{\mathrm{cl}}}{V_{\mathrm{cl}} - V_{\mathrm{refl}}}.
\end{align*}
At steady state this equals \des{R}{HVCL}'s dissipation, giving the design
equation the rest of this section solves:
\begin{align*}
  \frac{V_{\mathrm{cl}}^2}{\des{R}{HVCL}}
    = E_{\mathrm{lk}} f_{\mathrm{sw}}
      \frac{V_{\mathrm{cl}}}{V_{\mathrm{cl}} - V_{\mathrm{refl}}}.
\end{align*}

\subsubsection{Target clamp voltage}

Clamp effectiveness sets the minimum $V_{\mathrm{cl}}$. Use at least twice the
reflected voltage (inferred). Switch stress sets the maximum. The total stress
includes $V_{\mathrm{BUS,max}}$, $V_{\mathrm{cl}}$, and the \des{D}{HVCL}
forward drop:
\begin{align*}
  V_{DS,\mathrm{pk}} = V_{\mathrm{BUS,max}} + V_{\mathrm{cl}} + V_{F(\des{D}{HVCL})}.
\end{align*}
This section limits semiconductor voltage stress to $80\,\%$ of the rating.
The analysis assumes a \SI{1.5}{\volt} \des{D}{HVCL} forward drop. This value
is near the high end for a small fast rectifier at ampere-level pulse current
(inferred). With $V_{\mathrm{BUS,max}} = \SI{12.6}{\volt}$:
\begin{align*}
  V_{\mathrm{cl}}^{\max} = (1-m)\times\SI{100}{\volt} - V_{\mathrm{BUS,max}}
    - V_{F(\des{D}{HVCL})} = 80 - 12.6 - 1.5 = \SI{65.9}{\volt}.
\end{align*}
This value is 3.4 times the reflected voltage. Therefore, switch stress sets the
limit. A higher clamp voltage decreases clamp loss and decreases switch margin.
The target is $V_{\mathrm{cl}} = \SI{65.9}{\volt}$.

\subsubsection{\des{R}{HVCL}}

Solving the energy-balance equation for \des{R}{HVCL} at the target, with the
worst-case-corner clamp power:
\begin{align*}
  \des{R}{HVCL} = \frac{V_{\mathrm{cl}}(V_{\mathrm{cl}} - V_{\mathrm{refl}})}
    {E_{\mathrm{lk}} f_{\mathrm{sw}}}
    = \frac{65.9 \times 46.65}{\SI{94.9}{\milli\watt}} \approx \SI{32.4}{\kilo\ohm}.
\end{align*}
Rounding down to the standard value $\des{R}{HVCL} = \SI{30}{\kilo\ohm}$
preserves margin; re-solving the same equation for the resulting clamp voltage
at each of the two operating points,
\begin{align*}
  V_{\mathrm{cl}}^2 - V_{\mathrm{refl}} V_{\mathrm{cl}}
    - E_{\mathrm{lk}} f_{\mathrm{sw}} \des{R}{HVCL} = 0
  \;\Longrightarrow\;
  V_{\mathrm{cl}}^{\mathrm{lim}} = \SI{63.8}{\volt}, \qquad
  V_{\mathrm{cl}}^{\mathrm{dm}} = \SI{50.7}{\volt}
\end{align*}
(sustained current-limit corner and normal design-max operation,
respectively). At the current-limit corner, switch stress is
$V_{DS,\mathrm{pk}} = 12.6 + 63.8 + 1.5 = \SI{77.9}{\volt}$ against the
\SI{100}{\volt} rating. The margin is \SI{22.1}{\percent}. During normal
operation, the clamp voltage is \SI{50.7}{\volt}. This is 2.6 times the
reflected voltage. The clamp dissipates \SI{85.5}{\milli\watt}
(\cref{sec:hv-op-losses}). At the current-limit corner, dissipation is
\SI{136}{\milli\watt}. Hiccup limits this condition to a
\SI{0.2}{\percent} duty cycle (\cref{sec:hv-ss}). Require a
\SI{0.18}{\watt} power rating and an \SI{80}{\volt} voltage rating.

\subsubsection{\des{C}{HVCL}}

The preceding calculations use a constant clamp voltage. Clamp ripple adds to
peak drain stress. Limit ripple to $2\,\%$ of $V_{\mathrm{cl}}$ at the
worst-case current. This limit keeps the stress error small.

The charge delivered during each cycle follows from
$E_{\mathrm{cl}}=V_{\mathrm{cl}}Q_{\mathrm{cl}}$:
\begin{align*}
  Q_{\mathrm{cl}} = \frac{E_{\mathrm{lk}}}{V_{\mathrm{cl}} - V_{\mathrm{refl}}}
    = \frac{\SI{0.635}{\micro\joule}}{44.55} \approx \SI{14.3}{\nano\coulomb}.
\end{align*}
At a $2\,\%$ ripple target ($\Delta V \le \SI{1.28}{\volt}$ at
$V_{\mathrm{cl}}^{\mathrm{lim}} = \SI{63.8}{\volt}$):
\begin{align*}
  \des{C}{HVCL}^{\min} = \frac{Q_{\mathrm{cl}}}{\Delta V}
    = \frac{\SI{14.3}{\nano\coulomb}}{\SI{1.28}{\volt}} \approx \SI{11.2}{\nano\farad}.
\end{align*}
Rounding up to $\des{C}{HVCL} = \SI{12}{\nano\farad}$ gives actual ripple
$Q_{\mathrm{cl}}/\des{C}{HVCL} \approx \SI{1.19}{\volt}$ ($1.9\,\%$) and a
discharge time constant $\tau = \des{R}{HVCL} \des{C}{HVCL} \approx
\SI{360}{\micro\second}$, about $54$ switching periods: the near-DC node the
treatment above assumes. Its voltage rating follows the corner clamp voltage,
$\ge\SI{80}{\volt}$.

\subsubsection{\des{D}{HVCL} requirements}

The design does not specify a part for \des{D}{HVCL}. It must meet these
requirements:
\begin{itemize}[nosep]
  \item \textbf{Reverse voltage.} It must block $V_{\mathrm{BUS,max}} +
    V_{\mathrm{cl}}^{\mathrm{lim}} = 12.6 + 63.8 = \SI{76.4}{\volt}$ during the
    on-time; at the same $20\,\%$ voltage-derating standard used throughout
    this section, that requires a rated reverse voltage of at least
    \SI{95.5}{\volt}, i.e.\ a $\ge\SI{100}{\volt}$-class part.
  \item \textbf{Forward current.} The leakage current decreases from
    \SI{2.91}{\ampere} to zero in approximately \SI{9.8}{\nano\second}. The
    charge is \SI{14.3}{\nano\coulomb}. Its average is approximately
    \SI{2.1}{\milli\ampere}. A rectifier that meets the voltage requirement will
    typically meet this short-pulse requirement (inferred).
  \item \textbf{Reverse recovery.} \des{D}{HVCL} must block again before the
    next turn-on, and the off-interval never falls below
    \SI{4.0}{\micro\second} (\cref{sec:hv-dcm}). A fast
    ($\le\SI{500}{\nano\second}$) or ultrafast ($\le\SI{75}{\nano\second}$) part
    clears that; a standard-recovery part is comparable to the window itself and
    is excluded.
\end{itemize}

\subsection{Switch (\des{Q}{HVSW}) stress and losses}\label{sec:hv-switch}

The clamp sets the maximum drain stress. The worst case is the sustained
current-limit condition (\cref{sec:hv-clamp}):
\begin{align*}
  V_{DS,\mathrm{pk}} &= V_{\mathrm{BUS,max}} + V_{\mathrm{cl}}^{\mathrm{lim}}
    + V_{F(\des{D}{HVCL})} = 12.6 + 63.8 + 1.5 = \SI{77.9}{\volt}
\end{align*}
This stress gives a $22.1\,\%$ margin below the IRL540N
\SI{100}{\volt} rating. It meets the $20\,\%$ derating target. In normal
maximum-load operation, the peak is approximately \SI{64.8}{\volt}. Peak current
spans \SIrange{2.2}{2.9}{\ampere}, below the \SI{36}{\ampere} rating. The
\SI{6.85}{\volt} gate supply fully enhances the logic-level MOSFET. It also
stays inside the $\pm\SI{16}{\volt}$ gate rating.

Total switch dissipation at design-max, at the typical turn-off overlap
($t_{\mathrm{ovl}}^{\mathrm{typ}}=\SI{36}{\nano\second}$, \cref{sec:hv-op-losses}):
conduction \SI{60}{\milli\watt} + turn-off \SI{140}{\milli\watt} + $C_{oss}$ few
\si{\milli\watt} $\approx \SI{0.20}{\watt}$, a rise of $\approx\SI{12}{\kelvin}$
on a free-standing vertical TO-220 at $\theta_{JA} \approx
\SI{62}{\kelvin\per\watt}$. At the maximum \SI{54}{\nano\second} turn-off
overlap, conduction loss is \SI{62}{\milli\watt}. Turn-off loss is
\SI{215}{\milli\watt}. Total dissipation is approximately
\SI{0.28}{\watt}, and the temperature rise is approximately
\SI{17}{\kelvin}.

\textbf{Turn-off overlap is the largest converter loss.}
\des{D}{HVGOFF} and \des{R}{HVGOFF} decrease gate-discharge resistance from
approximately \SI{11.5}{\ohm} to \SI{4.8}{\ohm}. They decrease overlap from
\SIrange{75}{114}{\nano\second} to
\SIrange{36}{54}{\nano\second}. \des{D}{HVGOFF} is reverse-biased during
turn-on. Thus, \des{R}{HVGON} controls turn-on.

\subsection{Output rectifier (\des{D}{HVRECT})}\label{sec:hv-rect}

Reverse stress occurs during the on-time:
\begin{align*}
  V_R &= V_{\mathrm{out}} + n V_{\mathrm{BUS,max}}
       = 191.5 + 10 \times 12.6 = \SI{317.5}{\volt}
\end{align*}
at the maximum output (\cref{sec:hv-achieved-range}). Secondary-side ringing
keeps the total below \SI{345}{\volt}. The UF4005 rating is
\SI{600}{\volt}, which gives at least \SI{42}{\percent} margin. Average forward
current is \SI{15}{\milli\ampere} (\cref{sec:hv-budget}). Peak forward current
is \SI{0.22}{\ampere}. Conduction loss is approximately
\SI{15}{\milli\watt}. In DCM, diode current reaches zero during the idle
interval. Thus, the switch does not hard-commutate the diode.

\subsection{Input and output capacitance}\label{sec:hv-caps}

\subsubsection{Input}

\des{C}{HVI1} is the \SI{100}{\micro\farad} polymer-aluminum bulk capacitor.
\des{C}{HVI2} is a \SI{4.7}{\micro\farad} ceramic capacitor. It closes the
high-frequency primary loop. \des{C}{HVBIAS} bypasses BIAS
(\cref{sec:hv-house-bias}). The primary RMS current is
\SI{1.04}{\ampere}. Its DC component is \SI{0.74}{\ampere}. Thus, the capacitor
bank carries \SI{0.73}{\ampere} RMS. \textbf{Use a polymer-aluminum bulk
capacitor.} A small general-purpose \SI{100}{\micro\farad} aluminum
electrolytic typically has a \SIrange{0.3}{0.5}{\ampere} ripple rating at
\SI{150}{\kilo\hertz} (inferred). This rating is insufficient. The calculated
bus ripple is
\begin{align*}
  \Delta V \approx
  \frac{(I_{\mathrm{pk}}/2 - I_{\mathrm{in}})\,t_{\mathrm{on}}}{C_{\mathrm{in}}}
  + I_{\mathrm{pk}}\,\mathrm{ESR}
  \approx \frac{\SI{1.57}{\micro\coulomb}}{\SI{105}{\micro\farad}} + 2.18\times0.04
  \approx \SI{102}{\milli\volt}\ \text{peak-to-peak},
\end{align*}
unobjectionable on a USB-PD input.

\subsubsection{Output}

$C_{\mathrm{out}} = \des{C}{HVO1}\,(\SI{4.7}{\micro\farad}$, radial polarized, polymer
aluminum$) + \des{C}{HVO2}\,(\SI{100}{\nano\farad}\ \text{film})$.

The tube ballasts make the load approximately constant current. The rail does
not need hold-up energy or a transient reservoir. It needs only
switching-ripple control. Capacitive ripple per cycle is
\begin{align*}
  \Delta V_{\mathrm{cap}} &=
  \frac{I_{\mathrm{out}}\,(T - t_{\mathrm{dem}})}{C_{\mathrm{out}}}
  = \frac{15.4\,\si{\milli\ampere} \times 5.6\,\si{\micro\second}}
         {\SI{4.8}{\micro\farad}}
  = \SI{18}{\milli\volt},
\end{align*}
exceeded by the ESR step $I_{s,\mathrm{pk}}\times\mathrm{ESR} \approx 0.22 \times
0.5 \approx \SI{108}{\milli\volt}$ peak-to-peak ($0.06\,\%$ of the rail) at
\des{C}{HVO1}'s $\approx\SI{0.5}{\ohm}$ ESR, with the film part shunting the
fast edges.
Through a \SI{10}{\kilo\ohm} ballast (\cref{sec:hv-load-digit}) this modulates
tube current by $\sim$\SI{11}{\micro\ampere} at \SI{150}{\kilo\hertz},
optically invisible. The small capacitance is sufficient, and beneficial: it
keeps the stored energy at \SI{69}{\milli\joule}, the start-up rise time at
\SI{17}{\milli\second} (\cref{sec:hv-ss}), and the bleed-down inside seconds
(\cref{sec:hv-bleeder}).

\textbf{\des{C}{HVO1} requires a \SI{250}{\volt} rating.} A
\SI{160}{\volt} part cannot withstand the \SI{191.5}{\volt} maximum setting.
The \SI{250}{\volt} rating gives at least $23\,\%$ margin. The selected part
must also have approximately \SI{0.5}{\ohm} ESR or less.

\subsection{Bleeder (\des{R}{HVBLEED}) and minimum load}\label{sec:hv-bleeder}

\des{R}{HVBLEED} discharges $C_{\mathrm{out}}$ after shutdown. It also supplies
the minimum load that prevents pulse skipping.

\subsubsection{Discharge}\label{sec:hv-bleeder-discharge}

Stored energy is modest, $\tfrac{1}{2} C_{\mathrm{out}} V^2 =
\tfrac{1}{2}\times\SI{4.8}{\micro\farad}\times 170^2 = \SI{69}{\milli\joule}$
(\cref{sec:hv-caps}), but the node must still bleed down after shutdown.
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

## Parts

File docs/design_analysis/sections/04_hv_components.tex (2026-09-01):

\section{170~V converter: driving component characteristics}
\label{sec:hv-components}

The 170~V anode supply uses a current-mode flyback converter. Its main parts
are a TI LM51561H controller and a Coilcraft DA2032-AL transformer.
\Cref{sec:hv-converter} uses these characteristics and assigns the designators.

\subsection{LM51561H flyback controller}
\label{sec:lm5156h}

Source: \texttt{lm5156h.pdf}, Texas Instruments SNVSBV2, 2020-09. The LM5156H
and LM51561H use the same datasheet and pinout. All table values apply to both
parts. The LM51561H enables hiccup-mode overload protection. The LM5156H
disables it (p.~2). \Cref{sec:hv-ss} specifies the LM51561H. Pin numbers apply
to the 14-pin HTSSOP PWP package.

{\footnotesize
\begin{longtable}{|L{4.4cm}|c|c|c|c|L{3.8cm}|c|}
\caption{LM51561H electrical characteristics}\label{tab:lm5156h}\\
\hline
\textbf{Parameter} & \textbf{Min} & \textbf{Typ} & \textbf{Max} & \textbf{Units} & \textbf{Conditions} & \textbf{Page} \\
\hline
\endfirsthead
\caption[]{LM51561H electrical characteristics (continued)}\\
\hline
\textbf{Parameter} & \textbf{Min} & \textbf{Typ} & \textbf{Max} & \textbf{Units} & \textbf{Conditions} & \textbf{Page} \\
\hline
\endhead
FB reference voltage \(V_{REF}\) & \num{0.99} & \num{1.00} & \num{1.01} & \si{\volt} & \(T_J=-40\) to \SI{125}{\celsius} & 7 \\
\hline
Current-limit threshold \(V_{CLTH}\) (CS to PGND) & \num{93} & \num{100} & \num{107} & \si{\milli\volt} & \(R_T=9.09\)~k\(\Omega\), \(V_{BIAS}=12\)~V; fixed DC threshold & 7 \\
\hline
Peak slope-comp current \(I_{SLOPE}\) (optional, external \(R_{SL}\) only) & \num{22.5} & \num{30} & \num{37.5} & \si{\micro\ampere} & \(R_T=220\)~k\(\Omega\); \(I_{SLOPE}=30\,\si{\micro\ampere}\times f_{RT}/f_{SYNC}\) & 7, 20 \\
\hline
RT resistor equation & \multicolumn{4}{L{5.0cm}|}{\(R_T = \dfrac{2.21\times10^{10}}{f_{RT}\,[\mathrm{Hz}]} - 955\)~\(\Omega\)} & Characterized points: 220~k\(\Omega\)\(\to\)100~kHz, 9.09~k\(\Omega\)\(\to\)2.2~MHz & 16 \\
\hline
Soft-start current \(I_{SS}\) & \num{9} & \num{10} & \num{11} & \si{\micro\ampere} & & 7 \\
\hline
Soft-start time, boost topology & \multicolumn{4}{L{5.0cm}|}{\(t_{SS} = \dfrac{C_{SS}}{I_{SS}}\left(1-\dfrac{V_{SUPPLY}}{V_{LOAD}}\right)V_{REF}\)} & No flyback-specific equation given (see note) & 16 \\
\hline
Enable (EN) threshold, rising & \num{0.4} & \num{0.52} & \num{0.7} & \si{\volt} & Same physical pin as UVLO/SYNC (pin 14) & 5 \\
\hline
Enable (EN) threshold, falling & & \num{0.49} & & \si{\volt} & Same physical pin as UVLO/SYNC (pin 14) & 5 \\
\hline
UVLO/SYNC threshold, rising & \num{1.425} & \num{1.5} & \num{1.575} & \si{\volt} & Separate comparator, same pin as EN & 6 \\
\hline
UVLO/SYNC threshold, falling & \num{1.370} & \num{1.45} & \num{1.520} & \si{\volt} & Separate comparator, same pin as EN & 6 \\
\hline
UVLO hysteresis current \(I_{UVLO}\) & \num{4} & \num{5} & \num{6} & \si{\micro\ampere} & \(V_{UVLO}=1.6\)~V; sets external divider hysteresis & 6 \\
\hline
BIAS absolute maximum & \num{-0.3} & & \num{65} & \si{\volt} & & 4 \\
\hline
BIAS recommended operating & \num{3.5} & & \num{60} & \si{\volt} & When VCC is supplied from the internal regulator; \num{2.97} to \num{16}~V if BIAS is tied to VCC & 14 \\
\hline
VCC (internal gate-drive rail) regulation & \num{6.5} & \num{6.85} & \num{7} & \si{\volt} & \(V_{BIAS}=8\)~V, no load: the only condition at which the rail is specified & 5 \\
\hline
VCC regulation, loaded & \num{6.5} & & & \si{\volt} & \(V_{BIAS}=8\)~V, \(I_{VCC}=35\)~mA & 5 \\
\hline
VCC UVLO threshold, rising & \num{2.75} & \num{2.85} & \num{2.95} & \si{\volt} & \num{0.063}~V hysteresis falling & 5 \\
\hline
BIAS operating current \(I_{Q}\) & & \num{490} & \num{580} & \si{\micro\ampere} & \(V_{BIAS}=12\)~V, \(V_{FB}=V_{REF}\), \(R_T=220\)~k\(\Omega\) & 5 \\
\hline
VCC absolute maximum & \num{-0.3} & & \num{18}\footnotemark & \si{\volt} & or \(V_{BIAS}+0.3\)~V, whichever is lower & 4 \\
\hline
PGOOD absolute maximum & \num{-0.3} & & \num{18} & \si{\volt} & Open-drain; cannot exceed \(V_{BIAS}+0.3\)~V, internal diode path to BIAS & 4, 25 \\
\hline
PGOOD recommended pull-up & \num{10} & & & \si{\kilo\ohm} & & 25 \\
\hline
PGOOD pull-down \(r_{DS(on)}\) & & \num{90} & & \si{\ohm} & 1~mA sinking & 6 \\
\hline
PGOOD assert condition & \multicolumn{4}{L{5.0cm}|}{FB $>$ \(V_{UVTH}\) AND VCC $>$ VCC-UVLO AND UVLO/EN above threshold} & 25~\si{\micro\second} deglitch & 25 \\
\hline
PGOOD undervoltage threshold \(V_{UVTH}\) (\% of \(V_{REF}\), falling) & \num{87} & \num{90} & \num{93} & \% & \num{95}\% rising & 6 \\
\hline
Overvoltage threshold \(V_{OVTH}\) (\% of \(V_{REF}\), rising) & \num{107} & \num{110} & \num{113} & \% & \num{105}\% falling & 6 \\
\hline
Hiccup enable cycles & & \num{64} & & cycles & LM51561H only; counts current-limited cycles after soft start finishes & 6, 25 \\
\hline
Hiccup off-time & & \num{32768} & & cycles & LM51561H only; SS pulled down, then restart & 25 \\
\hline
Hiccup timer reset cycles & & \num{8} & & cycles & Consecutive cycles without current limiting & 6, 25 \\
\hline
Spread-spectrum modulation depth & & \multicolumn{2}{c|}{\(0.156 \times f_{SW}\)} & & Triangular sweep plus cycle-by-cycle randomization; disabled by tying DITHOFF to VCC & 17 \\
\hline
DITHOFF threshold, rising / falling & & \num{1.7} / \num{1.2} & & \si{\volt} & Dithers below 1.0~V, stops above 2.0~V & 6, 17 \\
\hline
Minimum on-time \(t_{ON(MIN)}\) & & \num{50} & & \si{\nano\second} & At \(R_T=9.09\)~k\(\Omega\) (2.2~MHz); \(\approx\)165~ns read from Fig.~8-12 near 150~kHz & 6, 9 \\
\hline
Maximum duty cycle \(D_{MAX}\), at \(R_T=9.09\)~k\(\Omega\) & \num{80} & \num{85} & \num{90} & \% & \(V_{BIAS}=4\)~V; frequency-dependent, \(\approx\)91 to 92\% typical near 150~kHz (inferred) & 6 \\
\hline
Maximum duty cycle \(D_{MAX}\), at \(R_T=220\)~k\(\Omega\) & \num{90} & \num{93} & \num{96} & \% & \(V_{BIAS}=4\)~V; frequency-dependent & 6 \\
\hline
GATE absolute maximum & \multicolumn{4}{c|}{No explicit positive max beyond VCC rail} & \(-1\)~V, 50~ns transient & 4 \\
\hline
CS absolute maximum (DC) & \num{-0.3} & & \num{0.3} & \si{\volt} & \(-1\)~V, 50~ns transient & 4 \\
\hline
RT, SS pin absolute maximum & \num{-0.3} & & \num{3.8} & \si{\volt} & FB is \num{4.0}~V; not intended for external drive & 4 \\
\hline
\end{longtable}
}
\footnotetext{Whichever is lower: \(\SI{18}{\volt}\) or \(V_{BIAS}+0.3\)~V.}

\paragraph{Current-limit slope compensation.} The \SI{100}{\milli\volt}
current-limit threshold is a fixed DC level at the CS pin. The peak-current
equation subtracts slope compensation only when optional resistor \(R_{SL}\) is
installed. TI recommends that the designer omit this resistor for an accurate
limit across \(V_{IN}\). A separate internal slope ramp enters only the PWM/COMP
comparator. It prevents subharmonic oscillation. It does not enter the
current-limit comparator. Thus, \cref{sec:hv-cs} uses the fixed
\SI{100}{\milli\volt} threshold.

\paragraph{Soft-start formula.} The datasheet gives soft-start equations only
for boost and SEPIC converters. Its nonisolated flyback example connects
FB, SS, and COMP as in the boost circuit. However, the boost equation assumes
an input-to-output conduction path. A flyback transformer has no such path.
Thus, \cref{sec:hv-ss} derives the time from the SS charging current. The
LM51561H soft start must continue until the output reaches regulation.
Otherwise, hiccup protection operates at each start.

\paragraph{EN and UVLO comparators.} Pin 14 has separate EN and UVLO
comparators. The approximately \SI{0.5}{\volt} EN threshold controls shutdown
and standby. The approximately \SI{1.5}{\volt} rising and
\SI{1.45}{\volt} falling UVLO thresholds control standby and operation. An
input divider sets the UVLO voltage. Its design uses the UVLO threshold and
hysteresis current.

\paragraph{Maximum duty cycle.} The frequency-dependent \(D_{MAX}\) is
approximately \SIrange{91}{92}{\percent} near \SI{150}{\kilo\hertz}
(inferred). This limit constrains the transformer turns ratio at minimum input
voltage. \Cref{sec:hv-dcm} checks the design against this limit.

\subsection{DA2032-AL flyback transformer}
\label{sec:da2032}

Source: \texttt{da2032.pdf} (Coilcraft).

{\footnotesize
\begin{longtable}{|L{4.6cm}|c|c|c|c|L{3.6cm}|c|}
\caption{DA2032-AL electrical characteristics}\label{tab:da2032}\\
\hline
\textbf{Parameter} & \textbf{Min} & \textbf{Typ} & \textbf{Max} & \textbf{Units} & \textbf{Conditions} & \textbf{Page} \\
\hline
\endfirsthead
\caption[]{DA2032-AL electrical characteristics (continued)}\\
\hline
\textbf{Parameter} & \textbf{Min} & \textbf{Typ} & \textbf{Max} & \textbf{Units} & \textbf{Conditions} & \textbf{Page} \\
\hline
\endhead
Turns ratio & \multicolumn{4}{c|}{1:10} & Only configuration offered; requires the two primary windings connected in parallel & 1 \\
\hline
Primary inductance \(L_P\), at 0~A & \num{9.0} & \num{10.0} & \num{11.0} & \si{\micro\henry} & 100~kHz, 0.1~V\textsubscript{rms}, 0~A\textsubscript{dc}; primaries in parallel (\(\pm10\%\)) & 1 \\
\hline
Primary inductance at \(I_{pk}\) & \num{9.0} & & & \si{\micro\henry} & At \(I_{pk}=3.0\)~A & 1 \\
\hline
Leakage inductance & & & \num{0.150} & \si{\micro\henry} & Referred to primary; primaries in parallel, secondary shorted & 1 \\
\hline
Peak primary current & & & \num{3.0} & \si{\ampere} & Rating point for the \(L_P\)-at-\(I_{pk}\) spec; no separate \(I_{sat}\) given & 1 \\
\hline
DCR, primary & & & \num{0.013} & \si{\ohm} & \SI{25}{\celsius}; primaries in parallel & 1 \\
\hline
DCR, secondary & & & \num{1.60} & \si{\ohm} & \SI{25}{\celsius} & 1 \\
\hline
Interwinding isolation & & & \num{1500} & \si{\volt_{rms}} & 1-minute withstand & 1 \\
\hline
Winding-to-core isolation & & & \num{750} & \si{\volt_{rms}} & 1-minute withstand & 1 \\
\hline
Interwinding capacitance & & \num{67} & & \si{\pico\farad} & 100~kHz, 0.1~V\textsubscript{rms}, pin 3 to pin 1 & 1 \\
\hline
Ambient/storage temperature, component & \num{-40} & & \num{125} & \si{\celsius} & & 1 \\
\hline
Ambient/storage temperature, tape \& reel & \num{-40} & & \num{80} & \si{\celsius} & & 1 \\
\hline
\end{longtable}
}

The secondary is on pins 1 and 12. The primary windings are on pins 3 to 10.
The polarity dot identifies pin 1. The datasheet gives no operating-frequency
range. It characterizes inductance and interwinding capacitance at
\SI{100}{\kilo\hertz}. Thus, operation at \SI{150}{\kilo\hertz} is an
extrapolation (inferred).

The datasheet gives no saturation current. It specifies a minimum inductance
of \SI{9.0}{\micro\henry} at \SI{3.0}{\ampere}. This analysis uses
\SI{3.0}{\ampere} as the effective peak-current rating (inferred). The
isolation ratings assume an isolated circuit. This board connects the
secondary return to primary ground. This external connection removes circuit
isolation. The transformer windings remain galvanically separate. The
datasheet does not prohibit this connection.

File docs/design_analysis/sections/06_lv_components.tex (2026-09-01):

\section{5~V and 3.3~V converters: driving component characteristics}
\label{sec:lv-components}

The two low-voltage supplies use different converter types. A TPS629203
synchronous buck converter supplies 5~V to the four K155ID1 drivers. Its input
is always higher than its output. A TPS63070 four-switch buck-boost converter
supplies 3.3~V to the MCU. Its input can be above or below 3.3~V
(\cref{sec:3v3-diodeor}). The following characteristics support both converter
designs.

\subsection{TPS629203 synchronous buck converter}
\label{sec:tps629203}

Source: \texttt{tps629203.pdf}, Texas Instruments SLVSGE2, 2022-03. The device
is a synchronous buck converter with internal compensation. DCS-Control changes
between pulse-width modulation and power-save operation. The device needs no
external bootstrap capacitor. A resistor at FB/VSET selects an external divider
or one of 18 preset output voltages. A resistor at MODE/S-CONF selects feedback,
frequency, output-discharge, and modulation options.

{\footnotesize
\begin{longtable}{|L{4.4cm}|c|c|c|c|L{3.6cm}|c|}
\caption{TPS629203 electrical characteristics}\label{tab:tps629203}\\
\hline
\textbf{Parameter} & \textbf{Min} & \textbf{Typ} & \textbf{Max} & \textbf{Units} & \textbf{Conditions} & \textbf{Page} \\
\hline
\endfirsthead
\caption[]{TPS629203 electrical characteristics (continued)}\\
\hline
\textbf{Parameter} & \textbf{Min} & \textbf{Typ} & \textbf{Max} & \textbf{Units} & \textbf{Conditions} & \textbf{Page} \\
\hline
\endhead
Input voltage range & \num{3.0} & & \num{17} & \si{\volt} & & 4 \\
\hline
Output voltage range & \num{0.4} & & \num{5.5} & \si{\volt} & & 4 \\
\hline
Output current & \num{0} & & \num{0.3} & \si{\ampere} & & 4 \\
\hline
VIN, EN, PG, MODE/S-CONF absolute maximum & \num{-0.3} & & \num{18} & \si{\volt} & & 4 \\
\hline
FB/VSET, VOS absolute maximum & \num{-0.3} & & \num{6} & \si{\volt} & & 4 \\
\hline
Effective input capacitance & \num{3} & \num{4.7} & & \si{\micro\farad} & & 4 \\
\hline
Effective output capacitance & \num{10} & \num{22} & \num{100} & \si{\micro\farad} & capacitors directly at the output & 4 \\
\hline
Output inductance & \num{1.0} & \num{2.2} & \num{4.7} & \si{\micro\henry} & nominal inductance value; \SI{1.0}{\micro\henry} not recommended for 1-MHz operation & 4 \\
\hline
Output voltage regulation & \num{-1} & & \num{1} & \% & VSET configuration; \(T_J=-40\) to \SI{125}{\celsius} & 5, 6 \\
\hline
Output voltage regulation & \num{-0.75} & & \num{0.75} & \% & VSET configuration; \(T_J=\SI{25}{\celsius}\) & 5 \\
\hline
Feedback regulation voltage \(V_{FB}\) & & \num{0.6} & & \si{\volt} & adjustable configuration selected & 6 \\
\hline
Feedback voltage regulation & \num{-1} & & \num{0.5} & \% & FB option; \(T_J=-40\) to \SI{125}{\celsius} & 6 \\
\hline
Switching frequency & & \num{2.5} & & \si{\mega\hertz} & 2.5-MHz selection, FPWM mode & 5 \\
\hline
Switching frequency & & \num{1.0} & & \si{\mega\hertz} & 1.0-MHz selection, FPWM mode & 5 \\
\hline
Minimum on time \(T_{ON(MIN)}\) & & \num{40} & & \si{\nano\second} & & 5 \\
\hline
High-side FET current limit \(I_{LIM}\) & \num{0.8} & \num{1.1} & \num{1.4} & \si{\ampere} & & 6 \\
\hline
Low-side FET current limit & \num{0.5} & \num{0.9} & \num{1.3} & \si{\ampere} & & 6 \\
\hline
Low-side FET sink current limit & \num{0.8} & \num{1} & \num{1.2} & \si{\ampere} & & 6 \\
\hline
High-side \(R_{DS(ON)}\) & & \num{250} & & \si{\milli\ohm} & & 6 \\
\hline
Low-side \(R_{DS(ON)}\) & & \num{85} & & \si{\milli\ohm} & & 6 \\
\hline
Quiescent current \(I_Q\) & & \num{4} & & \si{\micro\ampere} & \(I_{OUT}=0\)~mA, device not switching & 5 \\
\hline
Shutdown current into VIN & & \num{0.25} & \num{1.5} & \si{\micro\ampere} & EN = 0~V & 5 \\
\hline
Undervoltage lockout, rising & \num{2.85} & \num{2.95} & \num{3.0} & \si{\volt} & \(V_{IN}\) rising & 5 \\
\hline
Undervoltage lockout, falling & \num{2.65} & \num{2.75} & \num{2.85} & \si{\volt} & \(V_{IN}\) falling & 5 \\
\hline
EN input threshold, high & \num{0.97} & \num{1.0} & \num{1.03} & \si{\volt} & & 5 \\
\hline
EN input threshold, low & \num{0.87} & \num{0.9} & \num{0.93} & \si{\volt} & & 5 \\
\hline
EN input leakage current & & \num{3} & \num{300} & \si{\nano\ampere} & EN = \(V_{IN}\) & 5 \\
\hline
Start-up delay \(T_{delay}\) & & \num{1000} & \num{1800} & \si{\micro\second} & \(I_O=0\)~mA, EN rising edge until start switching, VSET configuration & 6 \\
\hline
Soft-start time \(T_{SS}\) & & \num{600} & \num{700} & \si{\micro\second} & \(I_O=0\)~mA after \(T_{delay}\), from first switching pulse until target \(V_O\) & 6 \\
\hline
Active discharge resistance & & \num{7.5} & \num{20} & \si{\ohm} & Discharge = ON option selected, EN = LOW & 6 \\
\hline
Thermal shutdown threshold & & \num{170} & & \si{\celsius} & \(T_J\) rising & 6 \\
\hline
Thermal shutdown hysteresis & & \num{20} & & \si{\celsius} & \(T_J\) falling & 6 \\
\hline
Minimum off time & & \num{80} & & \si{\nano\second} & & 17 \\
\hline
Internal propagation delay \(t_{PD}\) & & \num{50} & & \si{\nano\second} & & 14 \\
\hline
Maximum ripple current & & & \num{1.6} & \si{\ampere} & to avoid continuous operation of the negative current limit at \(I_O=0\)~A & 14 \\
\hline
Inductor saturation margin & \num{20} & & & \% & above the calculated maximum inductor current & 22 \\
\hline
Dynamic peak current & \multicolumn{4}{L{5.0cm}|}{\(I_{peak} = I_{LIMH} + \dfrac{V_{IN}-V_{OUT}}{L}\times t_{PD}\)} & & 14, 15 \\
\hline
Power-save on-time, 2.5-MHz selection & \multicolumn{4}{L{5.0cm}|}{\(T_{ON} = \SI{100}{\nano\second}\times\dfrac{V_{IN}}{V_{IN}-V_{OUT}}\)} & & 16 \\
\hline
Power-save peak inductor current & \multicolumn{4}{L{5.0cm}|}{\(I_{L(peak)} = \dfrac{V_{IN}-V_{OUT}}{L}\times T_{ON}\)} & & 16 \\
\hline
Power-save output ripple & \multicolumn{4}{L{5.0cm}|}{\(\Delta V = \dfrac{L\,V_{IN}^2}{200\,C}\left(\dfrac{1}{V_{IN}-V_{OUT}}+\dfrac{1}{V_{OUT}}\right)\)} & & 16 \\
\hline
Power-save entry threshold & \multicolumn{4}{L{5.0cm}|}{\(I_{load(PSM)} = \tfrac{1}{2}\Delta I_L\)} & suspended when \(V_{IN}\) falls within \SI{15}{\percent} of \(V_{OUT}\) & 16, 22 \\
\hline
Switching frequency with efficiency enhancement & \multicolumn{4}{L{5.0cm}|}{\(f_{SW}\,[\si{\mega\hertz}] = 10\,V_{OUT}\dfrac{V_{IN}-V_{OUT}}{V_{IN}^2}\)} & & 16 \\
\hline
Minimum input for regulation & \multicolumn{4}{L{5.0cm}|}{\(V_{IN(min)} = V_{OUT}+I_{OUT}(R_{DS(on)}+R_L)\)} & 100\,\% duty-cycle mode & 17 \\
\hline
Output voltage programming & \multicolumn{4}{L{5.0cm}|}{\(R_1 = R_2\left(\dfrac{V_{OUT}}{V_{FB}}-1\right)\)} & adjustable configuration; \(R_2\leq300\)~\si{\kilo\ohm} & 20 \\
\hline
VSET resistor for \SI{5.0}{\volt} output & & \num{80.6} & & \si{\kilo\ohm} & E96, 1\,\% accuracy, temperature coefficient at or better than $\pm200$~ppm/\si{\celsius} & 13 \\
\hline
MODE/S-CONF resistor, VSET with efficiency enhancement and discharge & & \num{27.4} & & \si{\kilo\ohm} & E96, 1\,\%, $\pm200$~ppm/\si{\celsius}; auto PFM/PWM, \(f_{SW}\) up to \SI{2.5}{\mega\hertz} & 11 \\
\hline
Effective capacitance derating & \num{-50} & & \num{20} & \% & basis of the recommended filter table & 21 \\
\hline
ESD rating, HBM & & & \num{2000} & \si{\volt} & $\pm$, either polarity & 4 \\
\hline
ESD rating, CDM & & & \num{500} & \si{\volt} & $\pm$, either polarity & 4 \\
\hline
\(\theta_{JA}\) (SOT-5X3, 8 pins) & & \num{120} & & \si{\celsius\per\watt} & JEDEC PCB & 4 \\
\hline
\(\theta_{JA}\) (SOT-5X3, 8 pins) & & \num{60} & & \si{\celsius\per\watt} & TPS6292xx EVM & 4 \\
\hline
\end{longtable}
}

\paragraph{Output-voltage tolerance.} The internal divider gives a
$\pm1\,\%$ output tolerance across the junction-temperature range. With an
external divider, the feedback-reference tolerance and divider-ratio tolerance
both affect the output. Therefore, \cref{sec:5v-vset} uses the internal divider.

\paragraph{Configuration sampling.} The device reads MODE/S-CONF and VSET once
during start-up. It does not read them during operation. Resistor configuration
also disables dynamic mode changes. Both resistors must be E96 $1\,\%$ parts.
Their temperature coefficient must be no more than
$\pm200$~ppm/\si{\celsius}.

\paragraph{Efficiency-enhancement frequency.} The device changes switching
frequency with conversion ratio. This action keeps inductor ripple approximately
constant. Therefore, \cref{sec:5v-op} calculates frequency across the input
range.

\paragraph{Ripple-current limit.} Inductor ripple must not exceed
\SI{1.6}{\ampere}. Above this value, the low-side negative current limit can
operate continuously at no load. This value sets the minimum inductance for a
given input voltage.

\subsection{TPS63070 buck-boost converter}
\label{sec:tps63070}

Source: \texttt{tps63070.pdf}, Texas Instruments SLVSC58B Rev. B, 2019-03. The
device is a four-switch buck-boost converter. It has synchronous rectification
and internal loop compensation. It changes automatically between buck and boost
operation. This design uses the adjustable variant. An external divider sets
the output from an \SI{800}{\milli\volt} reference.

{\footnotesize
\begin{longtable}{|L{4.4cm}|c|c|c|c|L{3.6cm}|c|}
\caption{TPS63070 electrical characteristics}\label{tab:tps63070}\\
\hline
\textbf{Parameter} & \textbf{Min} & \textbf{Typ} & \textbf{Max} & \textbf{Units} & \textbf{Conditions} & \textbf{Page} \\
\hline
\endfirsthead
\caption[]{TPS63070 electrical characteristics (continued)}\\
\hline
\textbf{Parameter} & \textbf{Min} & \textbf{Typ} & \textbf{Max} & \textbf{Units} & \textbf{Conditions} & \textbf{Page} \\
\hline
\endhead
Input voltage range, running & \num{2.0} & & \num{16} & \si{\volt} & once started; \(V_{OUT}\geq3.0\)~V & 6 \\
\hline
Input voltage range, start-up & \num{3.0} & & \num{16} & \si{\volt} & for start-up & 6 \\
\hline
Output voltage range & \num{2.5} & & \num{9} & \si{\volt} & & 7 \\
\hline
Feedback voltage \(V_{FB}\) & & \num{800} & & \si{\milli\volt} & & 7 \\
\hline
Output current & & & \num{2} & \si{\ampere} & \(V_{IN}\geq4.5\)~V or \(V_{OUT}\geq4.5\)~V, and boost factor \((V_{OUT}/V_{IN})\leq1\) & 6 \\
\hline
Feedback voltage accuracy, PWM & \num{-1} & & \num{1} & \% & TPS63070/TPS630702; PS/SYNC = GND (PWM mode) & 7 \\
\hline
Feedback voltage accuracy, PFM & \num{-1} & & \num{3} & \% & TPS63070/TPS630702; PS/SYNC = VIN (PFM mode); \(V_{IN}\geq3\)~V & 7 \\
\hline
Feedback leakage & & & \num{100} & \si{\nano\ampere} & for adjustable version; \(V_{FB}=0.8\)~V & 7 \\
\hline
Oscillator frequency & \num{2100} & \num{2400} & \num{2700} & \si{\kilo\hertz} & & 7 \\
\hline
Average positive input current limit & \num{3050} & \num{3600} & \num{4150} & \si{\milli\ampere} & \(V_{IN}=5.0\)~V; \(V_{OUT}=6.5\)~V; \(T_J=0\) to \SI{125}{\celsius} & 7 \\
\hline
Start-up current limit & & \num{1} & & \si{\ampere} & while power good is low & 15 \\
\hline
PFM-to-PWM transition & & \num{650} & & \si{\milli\ampere} & inductor current & 14 \\
\hline
Quiescent current into VIN & & \num{54} & \num{103} & \si{\micro\ampere} & \(I_{OUT}=0\)~mA, \(V_{EN}=V_{IN}=6\)~V, PFM, \(V_{OUT}=5\)~V & 6 \\
\hline
Quiescent current into VOUT & & \num{5} & \num{9} & \si{\micro\ampere} & \(I_{OUT}=0\)~mA, \(V_{EN}=6\)~V, \(V_{OUT}=5\)~V, PFM & 6 \\
\hline
Undervoltage lockout threshold & \num{1.7} & \num{1.85} & \num{1.95} & \si{\volt} & VIN voltage falling & 6 \\
\hline
Undervoltage lockout hysteresis & \num{525} & & \num{850} & \si{\milli\volt} & VIN voltage rising & 6 \\
\hline
EN, PS/SYNC threshold, rising & \num{0.77} & \num{0.8} & \num{0.83} & \si{\volt} & & 6 \\
\hline
EN, PS/SYNC threshold, falling & \num{0.67} & \num{0.7} & \num{0.73} & \si{\volt} & & 6 \\
\hline
EN, PS/SYNC, VSEL input current & & & \num{0.2} & \si{\micro\ampere} & & 6 \\
\hline
Power good threshold, rising & \num{94.5} & \num{96} & \num{98.5} & \% & rising \(V_{OUT}\) & 6 \\
\hline
Power good threshold, falling & \num{90} & \num{92} & \num{94.5} & \% & falling \(V_{OUT}\) & 6 \\
\hline
PG output low voltage \(V_{OL}\) & & & \num{0.4} & \si{\volt} & \(I_{PG}=-1\)~mA & 6 \\
\hline
PG sink current \(I_{PG}\) & & \num{1} & & \si{\milli\ampere} & & 6 \\
\hline
PG output leakage current & & & \num{0.2} & \si{\micro\ampere} & PG pin high impedance; \(V_{PG}=5\)~V & 6 \\
\hline
High-side \(R_{DS(ON)}\), buck & & \num{50} & \num{80} & \si{\milli\ohm} & \(V_{IN}=5\)~V & 7 \\
\hline
Low-side \(R_{DS(ON)}\), buck & & \num{100} & \num{160} & \si{\milli\ohm} & \(V_{IN}=5\)~V & 7 \\
\hline
High-side \(R_{DS(ON)}\), boost & & \num{40} & \num{70} & \si{\milli\ohm} & \(V_{IN}=5\)~V & 7 \\
\hline
Low-side \(R_{DS(ON)}\), boost & & \num{80} & \num{125} & \si{\milli\ohm} & \(V_{IN}=5\)~V & 7 \\
\hline
Soft-start time, buck mode & & \num{400} & & \si{\micro\second} & 5\% to 95\% of \(V_{OUT}\); \(V_{IN}=7.2\)~V, \(V_{OUT}=3.3\)~V, \(I_{OUT}=500\)~mA & 7 \\
\hline
Soft-start time, boost mode & & \num{850} & & \si{\micro\second} & 5\% to 95\% of \(V_{OUT}\); \(V_{IN}=3.0\)~V, \(V_{OUT}=3.3\)~V, \(I_{OUT}=250\)~mA & 7 \\
\hline
Start-up delay & & \num{70} & & \si{\micro\second} & from \(V_{EN}=V_{IH}\) to switching & 7 \\
\hline
Effective inductance & \num{0.7} & \num{1.5} & \num{2.8} & \si{\micro\henry} & & 4 \\
\hline
Effective inductance tolerance & \num{-30} & & \num{20} & \% & anticipated, including current derating & 17 \\
\hline
Capacitance at VIN pin & \num{4.7} & \num{10} & & \si{\micro\farad} & & 4 \\
\hline
Capacitance at VAUX pin & & \num{100} & & \si{\nano\farad} & & 4 \\
\hline
Total capacitance at VOUT pin & \num{15} & \num{47} & \num{470} & \si{\micro\farad} & for the nominal inductance of \SI{1.5}{\micro\henry} & 4 \\
\hline
Recommended output capacitance, \(L=\SI{1.5}{\micro\henry}\) & \multicolumn{4}{L{5.0cm}|}{\num{47}, \num{68}, or \SI{100}{\micro\farad} nominal} & typical application: \SI{47}{\micro\farad} & 17 \\
\hline
Duty cycle in buck mode & \num{30} & & & \% & over recommended operating conditions & 4 \\
\hline
Duty cycle in buck mode, relaxed & \num{20} & & & \% & effective \(C_{OUT}\geq40\)~\si{\micro\farad}; effective \(L=0.7\) to \(1.8\)~\si{\micro\henry} & 4 \\
\hline
Output filter ratio & \multicolumn{4}{L{5.0cm}|}{\(C_{OUT,\mathrm{eff}} \geq 10 \times L_{\mathrm{eff}}\)} & \si{\micro\farad} against \si{\micro\henry}; adjustable version & 17 \\
\hline
Output voltage programming & \multicolumn{4}{L{5.0cm}|}{\(R_1 = R_2\left(\dfrac{V_{OUT}}{0.8\,\mathrm{V}}-1\right)\)} & \(R_2\leq400\)~\si{\kilo\ohm} for \(\geq2\)~\si{\micro\ampere} divider current & 17 \\
\hline
Boost duty cycle & \multicolumn{4}{L{5.0cm}|}{\(D = \dfrac{V_{OUT}-V_{IN}}{V_{OUT}}\)} & & 18 \\
\hline
Boost peak inductor current & \multicolumn{4}{L{5.0cm}|}{\(I_{PEAK} = \dfrac{I_{OUT}}{\eta(1-D)} + \dfrac{V_{IN} D}{2 f L}\)} & evaluate at the minimum input reached in boost mode & 18 \\
\hline
Inductor saturation margin & \num{20} & & & \% & above the calculated peak & 18 \\
\hline
Right-half-plane zero & \multicolumn{4}{L{5.0cm}|}{\(f_{RHPZ} = \dfrac{(1-D)^2 V_{OUT}}{2\pi I_{OUT} L}\)} & recommended above \SI{400}{\kilo\hertz} & 18 \\
\hline
PFM output voltage offset & & \num{1} & & \% & above nominal & 14 \\
\hline
PFM output ripple & & \num{50} & & \si{\milli\volt} & peak-to-peak, \SI{22}{\micro\farad} effective capacitance & 14 \\
\hline
\(V_{IN}\), PS/SYNC, EN, VSEL absolute maximum & \num{-0.3} & & \num{20} & \si{\volt} & & 4 \\
\hline
L2, PG, VOUT, FB absolute maximum & \num{-0.3} & & \num{12} & \si{\volt} & & 4 \\
\hline
AUX absolute maximum & \num{-0.3} & & \num{7} & \si{\volt} & & 4 \\
\hline
ESD rating, HBM & & & \num{2000} & \si{\volt} & $\pm$, either polarity & 4 \\
\hline
ESD rating, CDM & & & \num{500} & \si{\volt} & $\pm$, either polarity & 4 \\
\hline
\(\theta_{JA}\) (VQFN, 13 pins) & & \num{63} & & \si{\celsius\per\watt} & & 5 \\
\hline
\end{longtable}
}

\paragraph{Input range.} The device takes its internal supply from the higher
of VIN and VOUT. It needs \SI{3.0}{\volt} to start. After start-up, it operates
to \SI{2.0}{\volt} input when VOUT is at least \SI{3.0}{\volt}. Therefore, an
input source must supply at least \SI{3.0}{\volt} at start-up.
\Cref{sec:3v3-diodeor} applies this requirement.

\paragraph{Output-current condition.} The \SI{2}{\ampere} value applies only in
buck operation when VIN or VOUT is at least \SI{4.5}{\volt}. The datasheet does
not give a guaranteed value outside these conditions. It gives only application
curves.

\paragraph{Power Save Mode.} Below approximately
\SI{650}{\milli\ampere} of inductor current, the converter skips cycles. The
output is then approximately \SI{1}{\percent} above nominal. Feedback tolerance
changes from $\pm1\,\%$ to $+3/-1\,\%$. PS/SYNC selects this mode. A low level
at PS/SYNC disables it.

\paragraph{Adjustable-variant tolerance.} For the adjustable part, the
datasheet specifies $V_{FB}$ tolerance. Divider-ratio tolerance and
\SI{100}{\nano\ampere} feedback leakage also affect the output.
\Cref{sec:3v3-fb,sec:3v3-cout} include both effects.

\paragraph{Package.} The part is available only in a 13-pin VQFN with a
$2.5\times3$~\si{\milli\meter} body. Therefore, this package is a design
requirement.

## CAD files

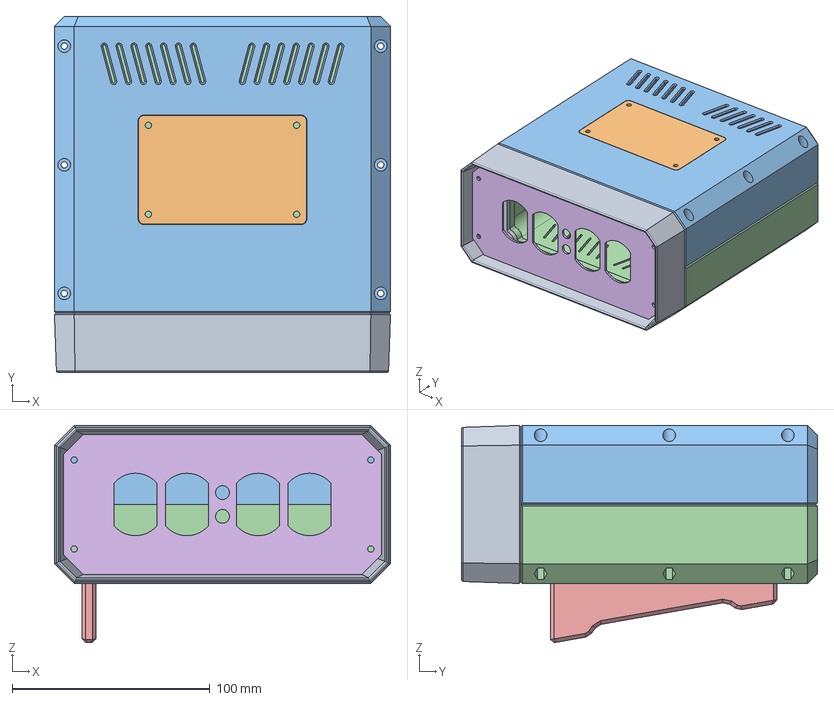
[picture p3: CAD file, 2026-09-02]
cad/case/Case.FCStd
170.0 x 180.0 x 109.9 mm
FaceFrame
AcryclicPanel
SleeveTop
SleeveBottom
Foot
FaceAcrylic

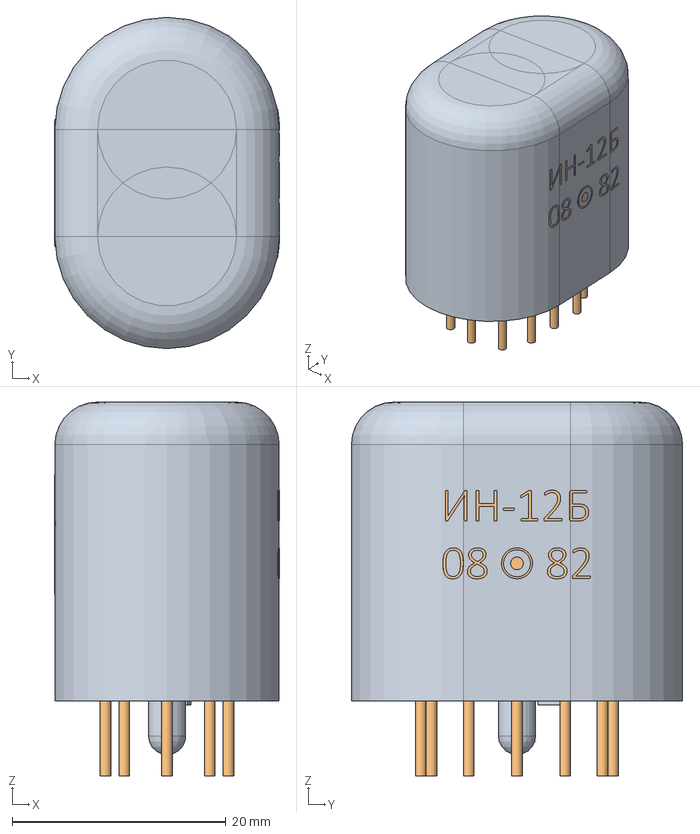
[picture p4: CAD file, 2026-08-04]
cad/in12/IN12.FCStd
21.1 x 31.0 x 35.0 mm
Glass
Pins
Anode
Cathodes
Shields
Bars
Plate
Spacers
Getter
Marks

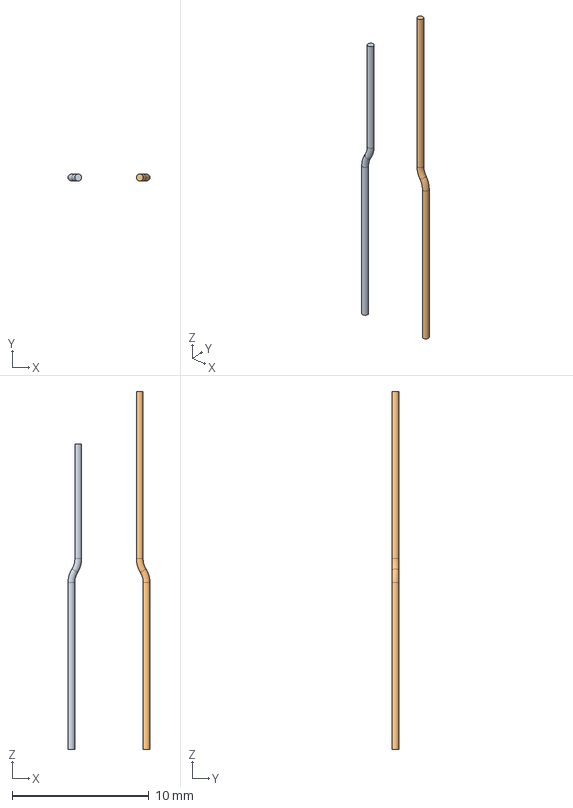
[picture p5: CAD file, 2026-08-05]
cad/ins1/INS1-Wires.step
6.00 x 0.5 x 26.2 mm

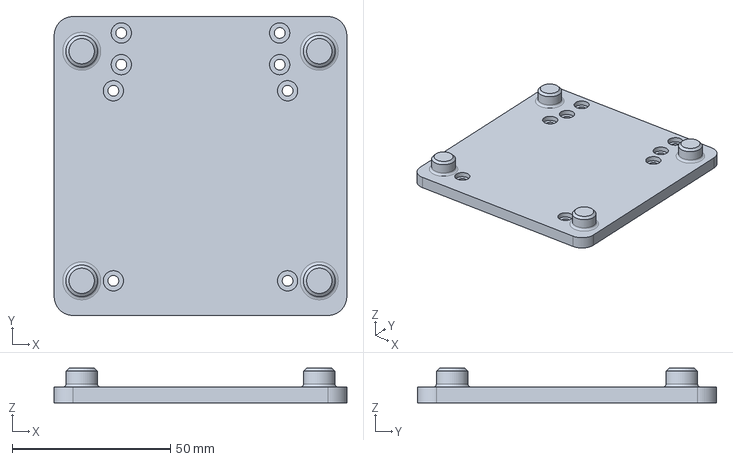
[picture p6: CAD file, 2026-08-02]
cad/test_base/print/base.step
92.4 x 94.4 x 11.0 mm

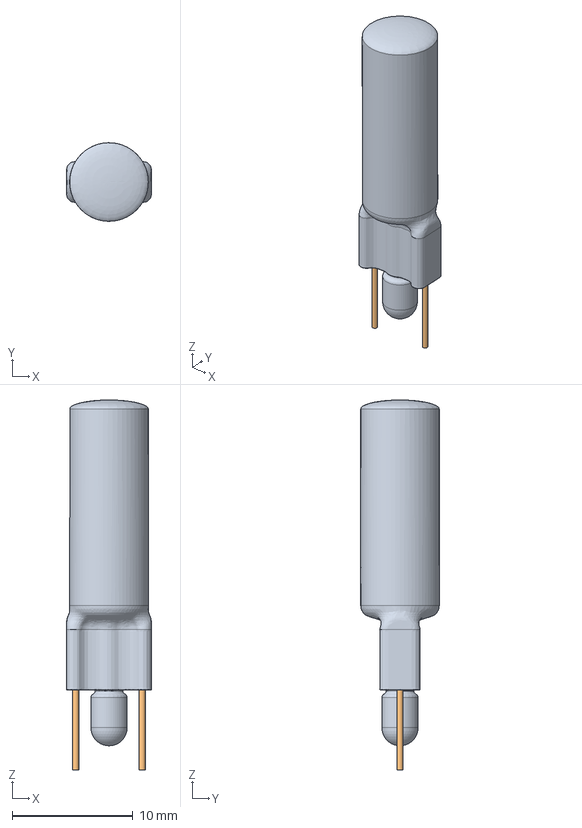
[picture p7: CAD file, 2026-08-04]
cad/ins1/INS1.FCStd
7.00 x 6.50 x 30.6 mm
Glass
Wires
Micas
Anode
Cathode
Glow

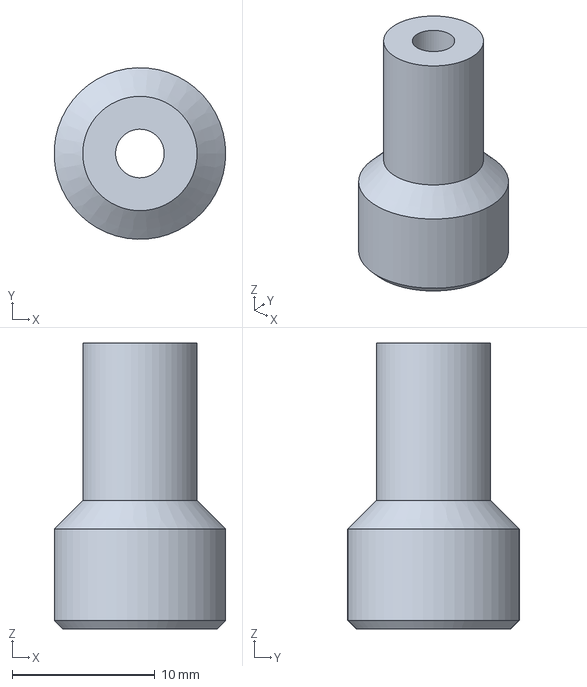
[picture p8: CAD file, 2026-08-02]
cad/test_base/print/riser.step
12.0 x 12.0 x 20.0 mm

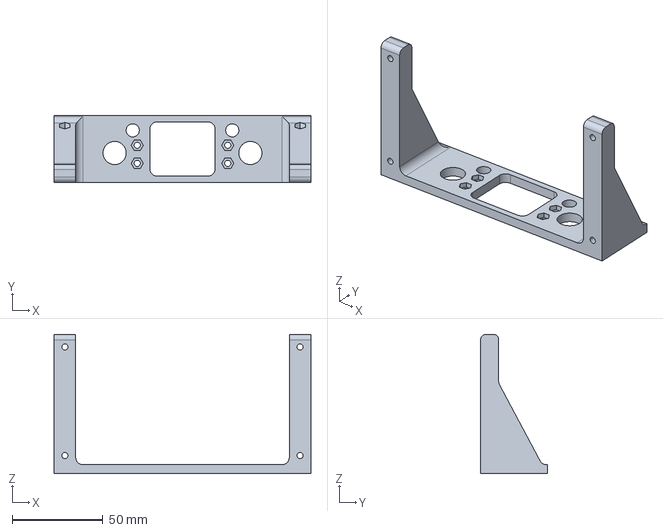
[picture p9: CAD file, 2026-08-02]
cad/test_base/print/face.step
142.0 x 36.9 x 77.0 mm

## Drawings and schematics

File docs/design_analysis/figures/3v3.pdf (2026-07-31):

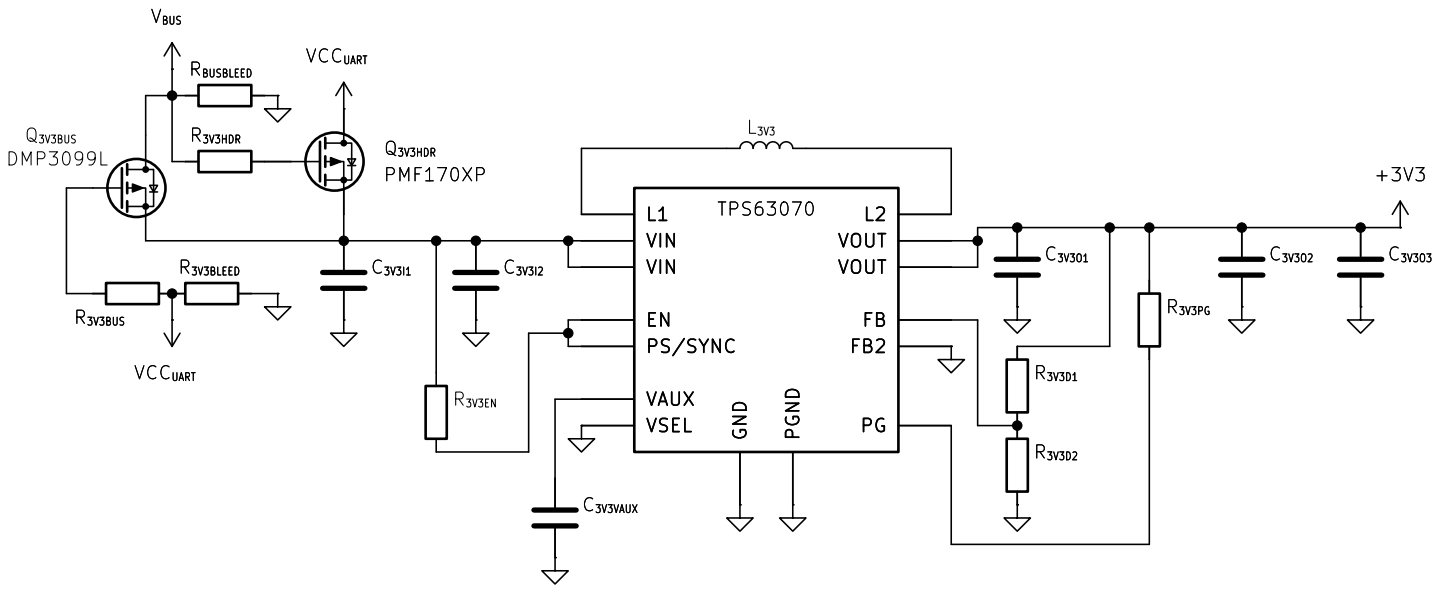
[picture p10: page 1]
C3V3O3 PS/SYNC; VAUX; GND; L1 VIN VIN; VSEL; TPS63070; +3V3 C3V3VAUX R3V3EN VCCUART VBUS; C3V3O1 Q3V3BUS DMP3099L R3V3BUS; R3V3HDR RBUSBLEED; Q3V3HDR PMF170XP; R3V3BLEED; C3V3O2 VCCUART; R3V3D2 R3V3D1 TPS63070 PS/SYNC; VBUS R3V3BUS; VCCUART R3V3HDR RBUSBLEED; C3V3I1 VCCUART; C3V3VAUX C3V3I2

VOUT VOUT L2 PGND

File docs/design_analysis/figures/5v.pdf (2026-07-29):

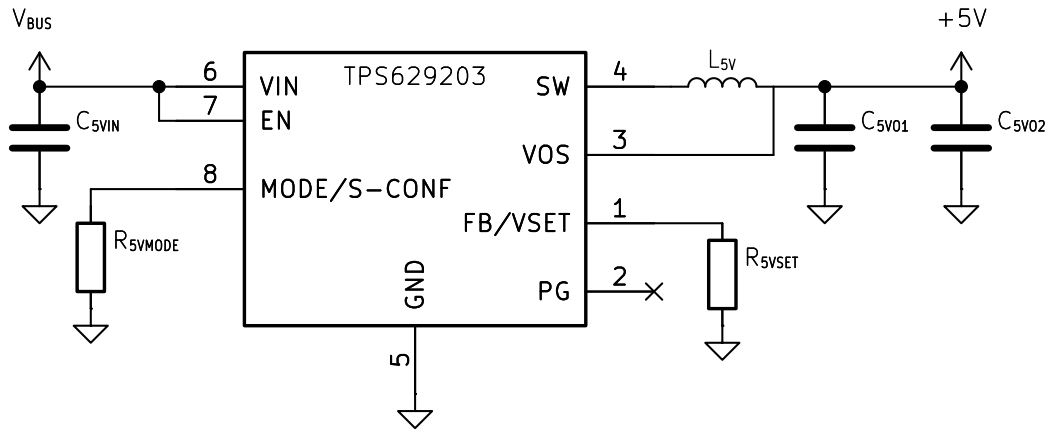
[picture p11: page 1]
VBUS; C5VIN; C5VO1 R5VSET L5V R5VMODE; FB/VSET; VOS; 4 GND; VIN 6; MODE/S-CONF 8; TPS629203; +5V C5VO2 VBUS; C5VO1 R5VSET R5VMODE

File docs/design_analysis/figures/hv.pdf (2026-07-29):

2

4

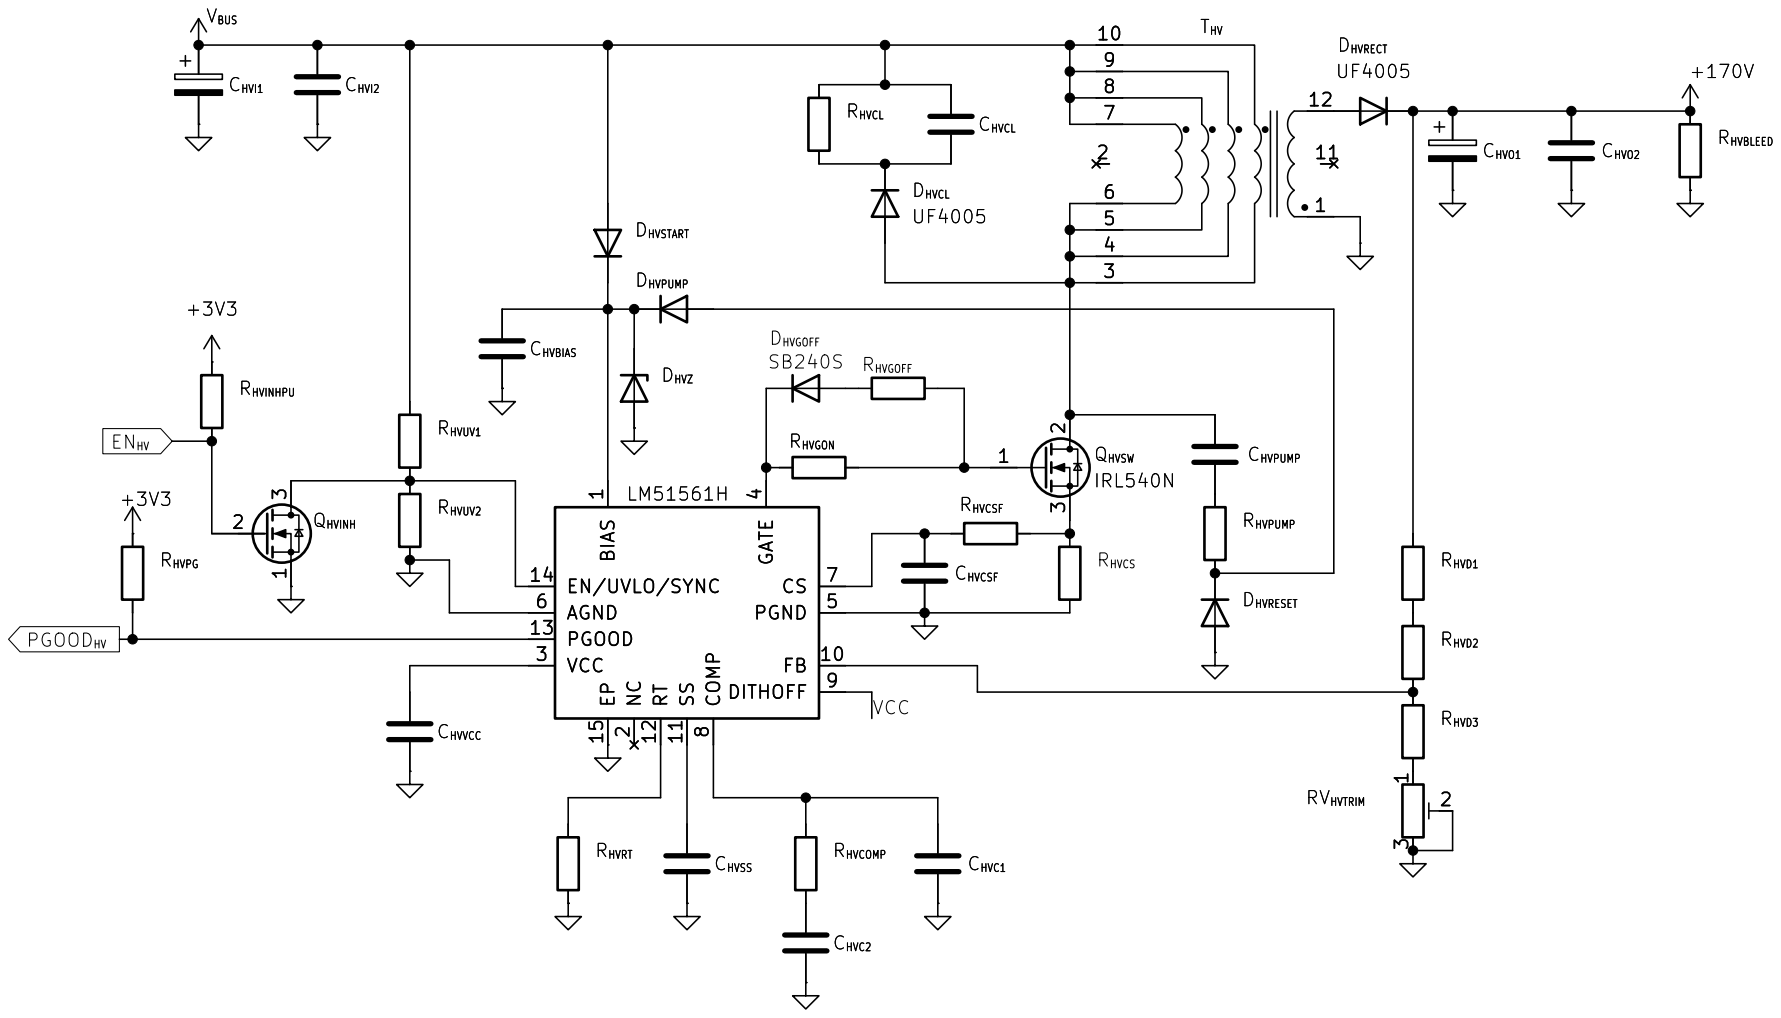
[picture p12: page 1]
RHVBLEED CHVO2; +170V CHVI2 +3V3; RHVINHPU; RHVD1 VBUSCHVI1; RHVUV1; RHVD2 CHVO1 RHVUV2; DHVCL UF4005 CHVVCC; THV CHVBIAS; CHVCL; DHVRECT UF4005; VCC 3; GATE 4 PGND 5; AGND 6; CS 7 COMP; 8 DITHOFF 9; EN/UVLO/SYNC 14; RHVCOMP CHVC2; CHVC11; 2 3 QHVSW; IRL540N; RHVCSF; RHVPUMP CHVPUMP RHVCS; DHVRESET; +170V CHVO1 THV; 12 DHVRECT UF4005 +3V3; RHVINHPU +3V3; RHVUV1 RHVUV2; CHVBIAS QHVINH 1; CHVC1; QHVSW; 3 RHVD3 RHVD1 RHVD2

3 RHVPG CHVVCC CHVI2 VBUSCHVI1 CHVCL DHVCL UF4005 RHVGON RHVCL DHVSTART DHVZ DHVPUMP CHVSS RHVRT CHVCSF LM51561H BIAS

3 QHVINH RHVPG RHVGOFF RHVGON RHVCL DHVSTART DHVZ DHVGOFF SB240S DHVPUMP CHVSS RHVRT CHVCSF BIAS

3 RVHVTRIM RHVD3 PGOODHV ENHV VCC

2 RHVCSF 3 RHVPUMP CHVPUMP DHVRESET RVHVTRIM 1

FB 10 SS 11 RT 12 PGOOD 13

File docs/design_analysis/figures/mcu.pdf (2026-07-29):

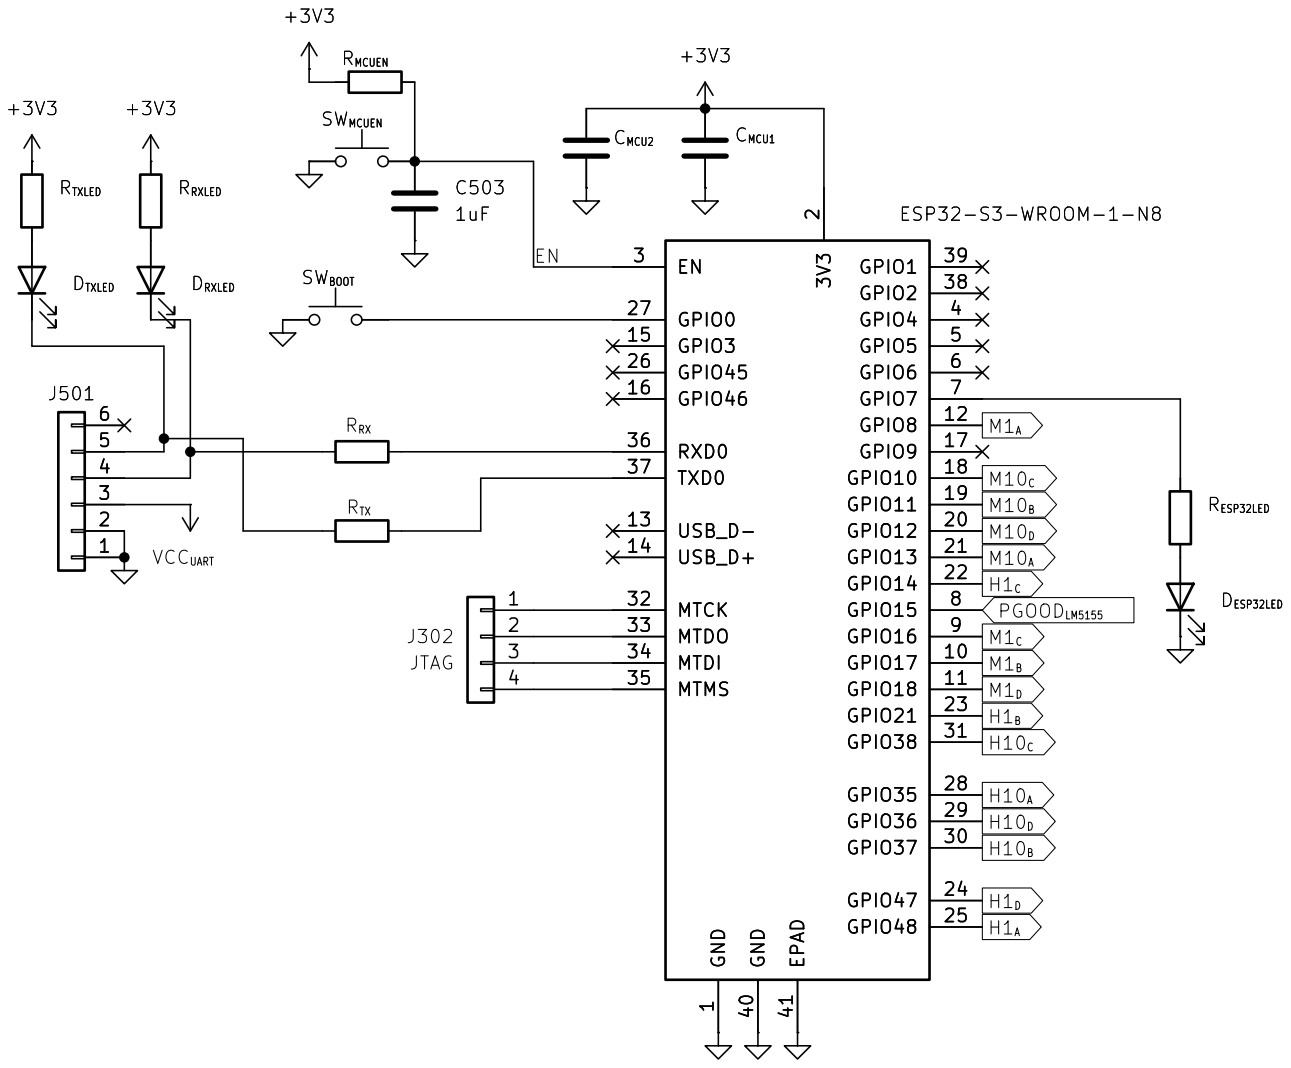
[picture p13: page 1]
SWBOOTRTX RMCUEN SWMCUEN DTXLED +3V3; GND; GPIO4; 4 GPIO5; 5 GPIO6; 6 GPIO7; 7 GPIO15; 8 GPIO16; 9 GPIO17; 10 GPIO18; 11 GPIO8; 12 USB_D- 13; USB_D+ 14; GPIO3 15; GPIO46 16; GPIO9; 17 GPIO10; 18 GPIO11; 19 GPIO12; 20 GPIO13; 21 GPIO14; 22 GPIO21; 23 GPIO47; 24 GPIO48; 25 GPIO45 26; GPIO0 27; GPIO35; 28 GPIO36; 29 GPIO37; 30 GPIO38; 31 MTCK 32; MTDO 33; MTDI 34; MTMS 35; RXD0 36; TXD0 37; GPIO2; 38 GPIO1; 39 GND 40; EPAD 41; ESP32-S3-WROOM-1-N8 RTXLED; RRXLED +3V3; DRXLED; CMCU2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

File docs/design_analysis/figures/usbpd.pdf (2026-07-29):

DBUSG RBUSBIAS | VDDD
RBUSOFF RBUSG | DBUSG VDDD | VDDD

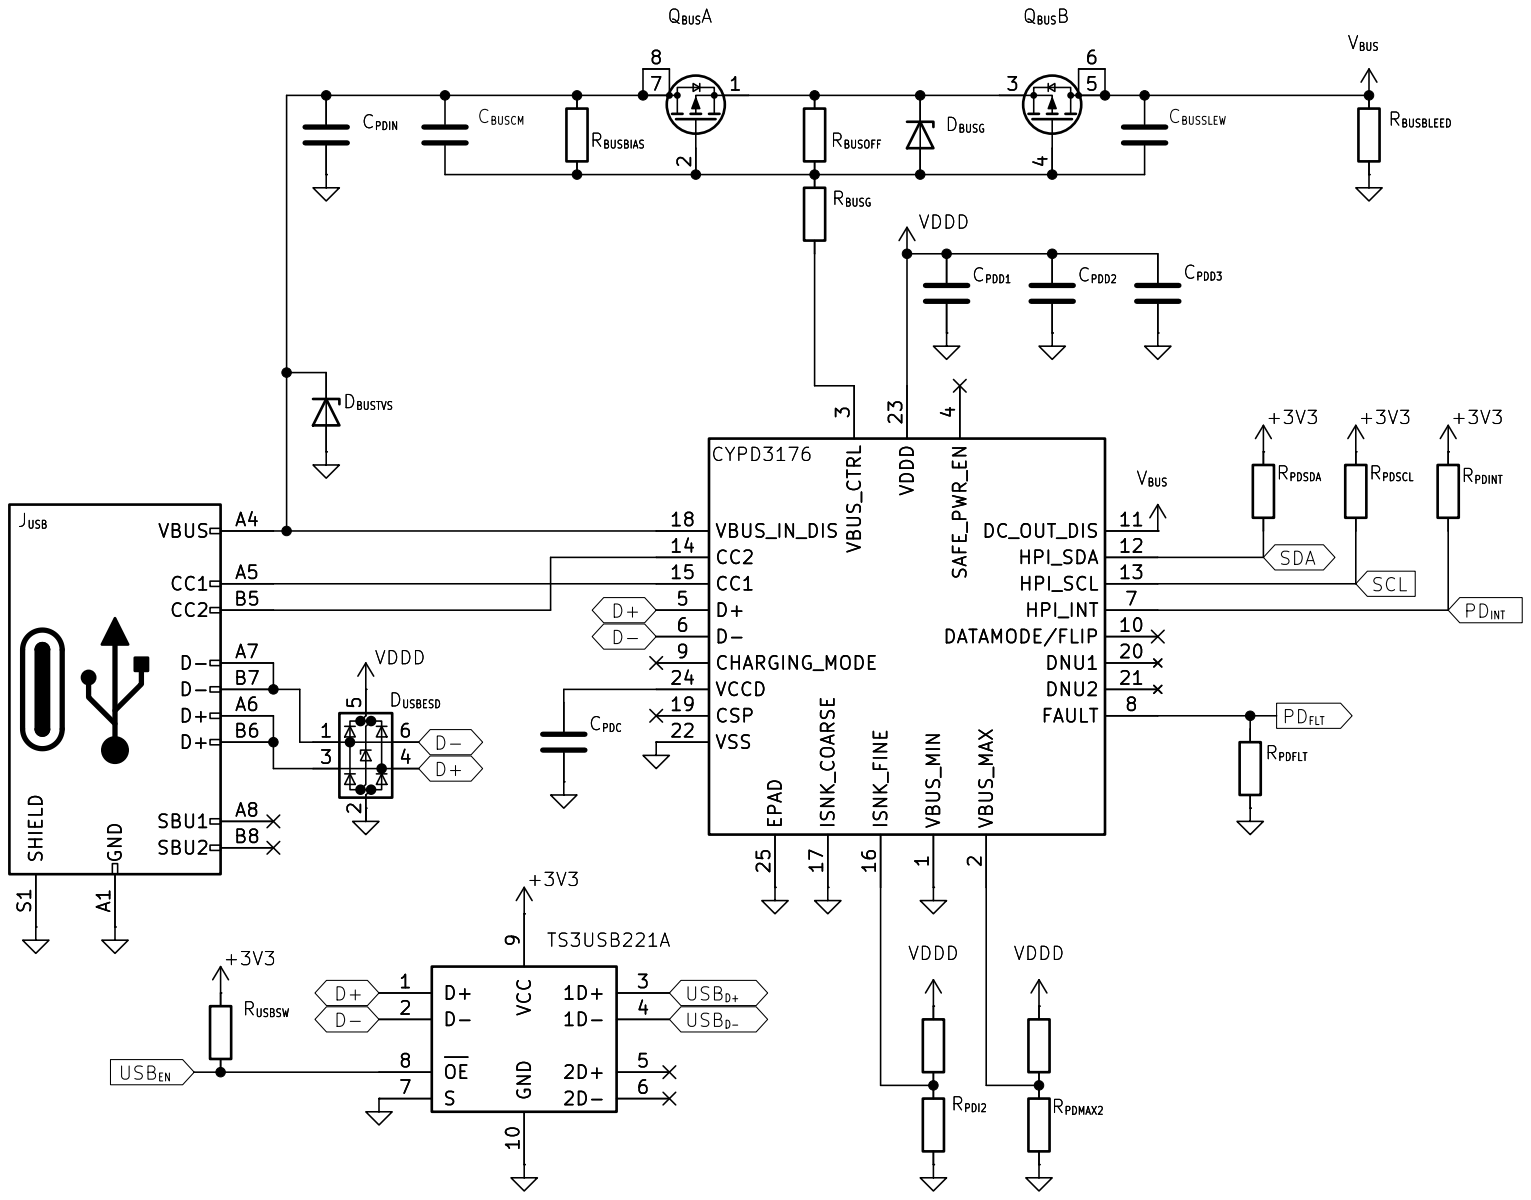
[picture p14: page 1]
CBUSCM; VDDD; DBUSTVS; CPDD2 1; 8 QBUSA; RPDI2; RPDFLT VBUS_MIN; 1 VBUS_MAX; 2 VBUS_CTRL 3 SAFE_PWR_EN; 4 D+ 5 D- 6 HPI_INT 7; FAULT; 8 CHARGING_MODE 9; DATAMODE/FLIP 10 DC_OUT_DIS 11 HPI_SDA 12 HPI_SCL 13 CC2 14 CC1 15; ISNK_FINE 16 ISNK_COARSE 17; VBUS_IN_DIS 18 CSP 19; DNU1 20 DNU2 21; VSS 22; VDDD 23; VCCD 24; EPAD 25 CYPD3176; 6 QBUSB; RPDMAX2; CPDIN; VBUS CPDD1 VDDD; VCC; 9 GND 10; TS3USB221A; RBUSOFF RBUSG; CPDC GND A1; VBUS; SBU1; SBU2; B8 SHIELD S1; JUSB; +3V3 RUSBSW; RPDSDA +3V3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

9 GND 10 RPDFLT RPDI2 RPDMAX2 VDDD

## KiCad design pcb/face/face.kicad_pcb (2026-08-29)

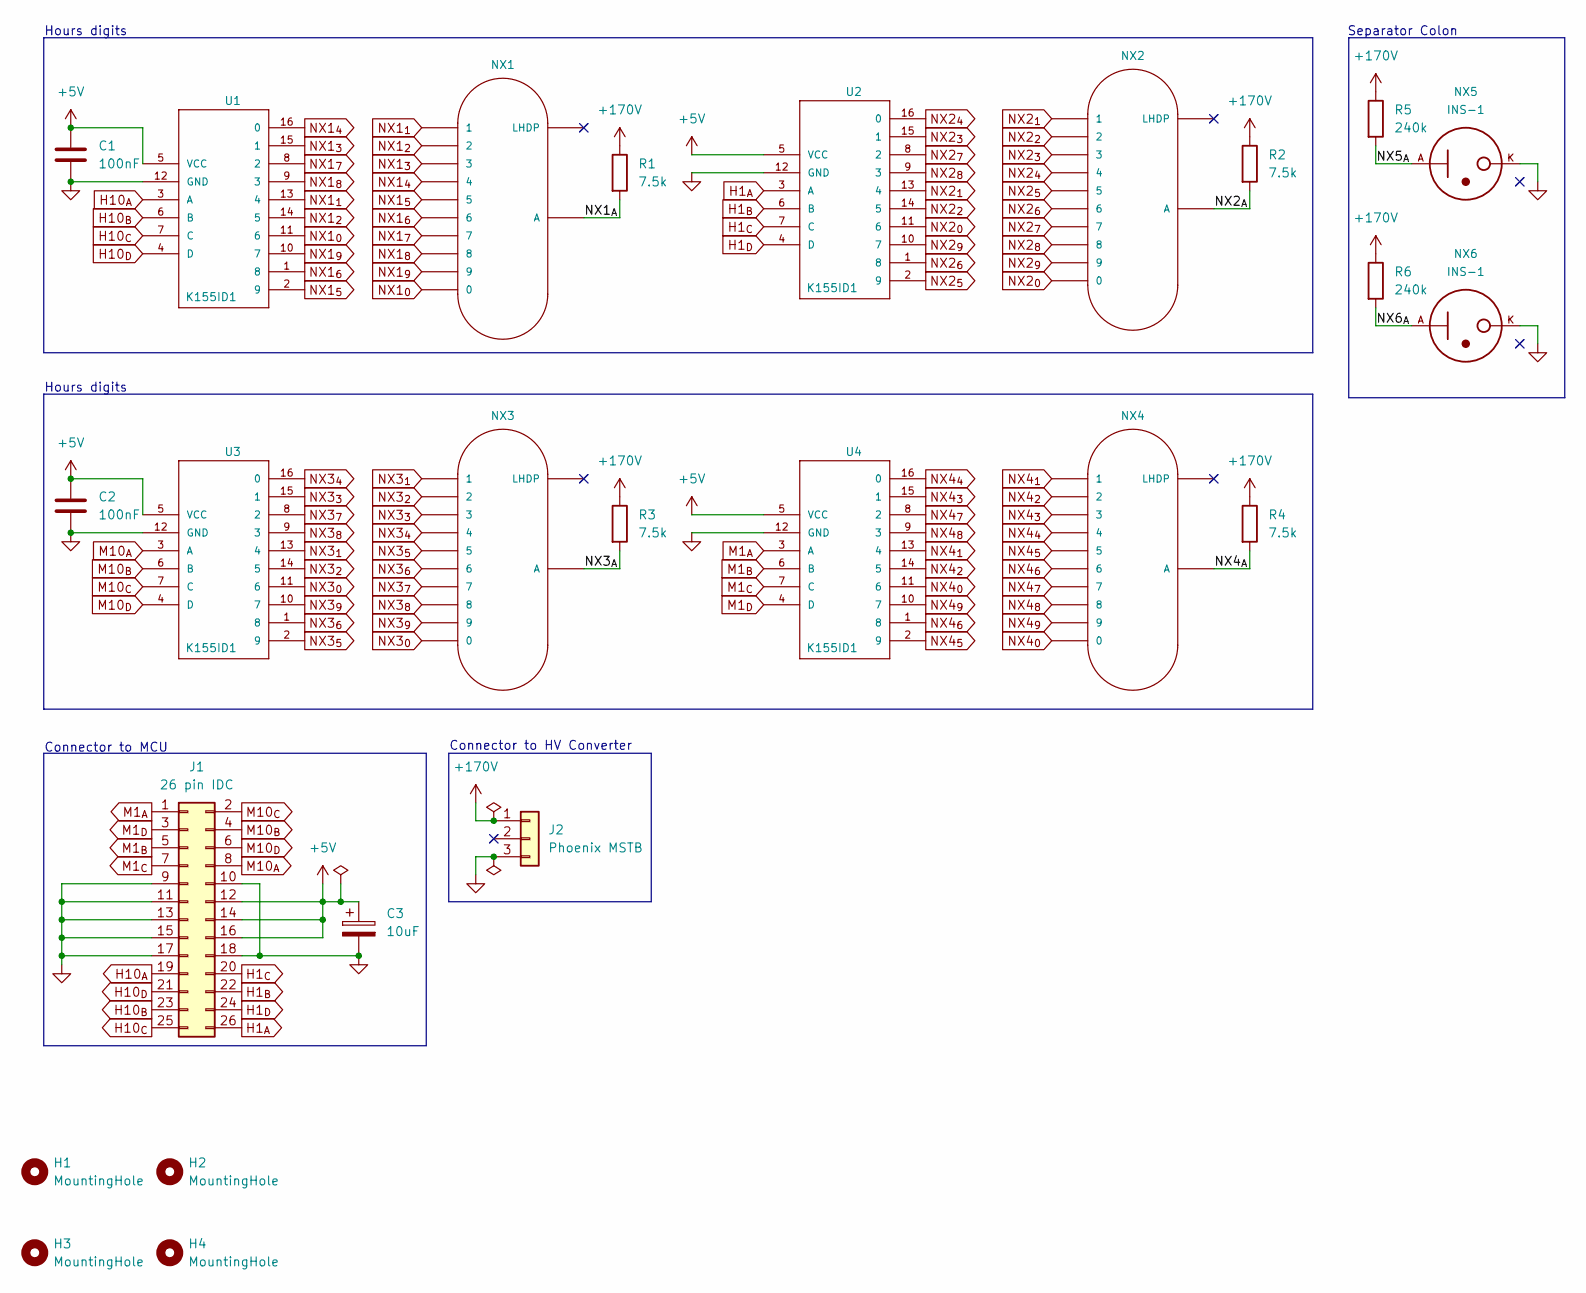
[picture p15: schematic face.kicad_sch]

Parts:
C1, C2: 100nF; C_Rect_L5.1mm_W3.2mm_P2.54mm_Goldmax; MFG Part No C320C104K5R5TA
C3: 10uF; CP_Radial_D5.0mm_P2.00mm; MFG Part No A758BG106M1EAAE070
H1, H2, H3, H4: MountingHole; MountingHole_3.2mm_M3_ISO7380
J1: 26 pin IDC; IDC-Header_2x13_P2.54mm_Vertical; MFG Part No 75869-105LF
J2: Phoenix MSTB; PhoenixContact_MSTBVA_2,5_3-G-5,08_1x03_P5.08mm_Vertical; MFG Part No 1755749
NX1, NX2, NX3, NX4: IN-12B; IN-12-DSUB
NX5, NX6: INS-1; INS-1_Recessed
R1, R2, R3, R4: 7.5k; R_Axial_DIN0207_L6.3mm_D2.5mm_P10.16mm_Horizontal; MFG Part No MFR-25FTE52-7K5
R5, R6: 240k; R_Axial_DIN0207_L6.3mm_D2.5mm_P10.16mm_Horizontal; MFG Part No CFR-25JR-52-240K
U1, U2, U3, U4: K155ID1; DIP16

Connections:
+5V: C1.1, C2.1, C3.1, J1.12, J1.14, J1.16, U1.5 (VCC), U2.5 (VCC), U3.5 (VCC), U4.5 (VCC)
+170V: J2.1, R1.1, R2.1, R3.1, R4.1, R5.1, R6.1
/NX1_{A}: NX1.A, R1.2
/NX2_{A}: NX2.A, R2.2
/NX3_{A}: NX3.A, R3.2
/NX4_{A}: NX4.A, R4.2
/NX5_{A}: NX5.A, R5.2
/NX6_{A}: NX6.A, R6.2
GND: C1.2, C2.2, C3.2, J1.9, J1.10, J1.11, J1.13, J1.15, J1.17, J1.18, J2.3, NX5.K, NX6.K, U1.12 (GND), U2.12 (GND), U3.12 (GND), U4.12 (GND)
H1_{A}: J1.26, U2.3 (A)
H1_{B}: J1.22, U2.6 (B)
H1_{C}: J1.20, U2.7 (C)
H1_{D}: J1.24, U2.4 (D)
H10_{A}: J1.19, U1.3 (A)
H10_{B}: J1.23, U1.6 (B)
H10_{C}: J1.25, U1.7 (C)
H10_{D}: J1.21, U1.4 (D)
M1_{A}: J1.1, U4.3 (A)
M1_{B}: J1.5, U4.6 (B)
M1_{C}: J1.7, U4.7 (C)
M1_{D}: J1.3, U4.4 (D)
M10_{A}: J1.8, U3.3 (A)
M10_{B}: J1.4, U3.6 (B)
M10_{C}: J1.2, U3.7 (C)
M10_{D}: J1.6, U3.4 (D)
NX1_{0}: NX1.0, U1.11 (6)
NX1_{1}: NX1.1, U1.13 (4)
NX1_{2}: NX1.2, U1.14 (5)
NX1_{3}: NX1.3, U1.15 (1)
NX1_{4}: NX1.4, U1.16 (0)
NX1_{5}: NX1.5, U1.2 (9)
NX1_{6}: NX1.6, U1.1 (8)
NX1_{7}: NX1.7, U1.8 (2)
NX1_{8}: NX1.8, U1.9 (3)
NX1_{9}: NX1.9, U1.10 (7)
NX2_{0}: NX2.0, U2.11 (6)
NX2_{1}: NX2.1, U2.13 (4)
NX2_{2}: NX2.2, U2.14 (5)
NX2_{3}: NX2.3, U2.15 (1)
NX2_{4}: NX2.4, U2.16 (0)
NX2_{5}: NX2.5, U2.2 (9)
NX2_{6}: NX2.6, U2.1 (8)
NX2_{7}: NX2.7, U2.8 (2)
NX2_{8}: NX2.8, U2.9 (3)
NX2_{9}: NX2.9, U2.10 (7)
NX3_{0}: NX3.0, U3.11 (6)
NX3_{1}: NX3.1, U3.13 (4)
NX3_{2}: NX3.2, U3.14 (5)
NX3_{3}: NX3.3, U3.15 (1)
NX3_{4}: NX3.4, U3.16 (0)
NX3_{5}: NX3.5, U3.2 (9)
NX3_{6}: NX3.6, U3.1 (8)
NX3_{7}: NX3.7, U3.8 (2)
NX3_{8}: NX3.8, U3.9 (3)
NX3_{9}: NX3.9, U3.10 (7)
NX4_{0}: NX4.0, U4.11 (6)
NX4_{1}: NX4.1, U4.13 (4)
NX4_{2}: NX4.2, U4.14 (5)
NX4_{3}: NX4.3, U4.15 (1)
NX4_{4}: NX4.4, U4.16 (0)
NX4_{5}: NX4.5, U4.2 (9)
NX4_{6}: NX4.6, U4.1 (8)
NX4_{7}: NX4.7, U4.8 (2)
NX4_{8}: NX4.8, U4.9 (3)
NX4_{9}: NX4.9, U4.10 (7)

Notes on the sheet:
Connector to MCU
Hours digits
Separator Colon
Connector to HV Converter

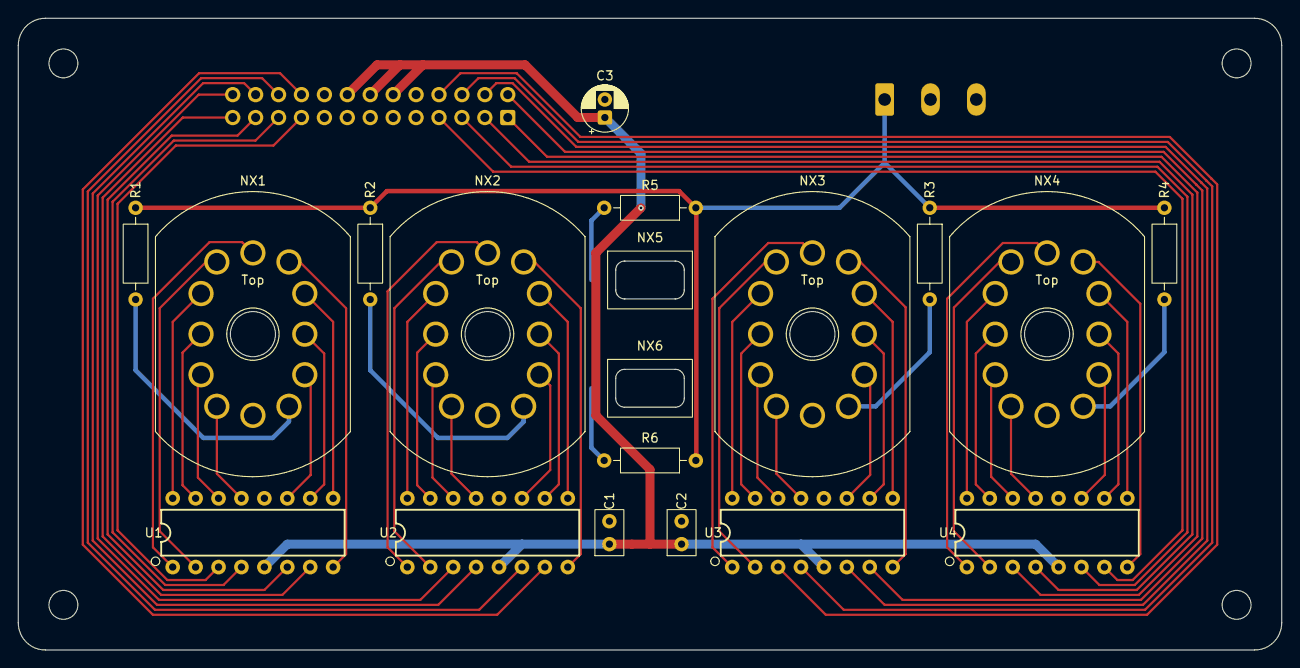
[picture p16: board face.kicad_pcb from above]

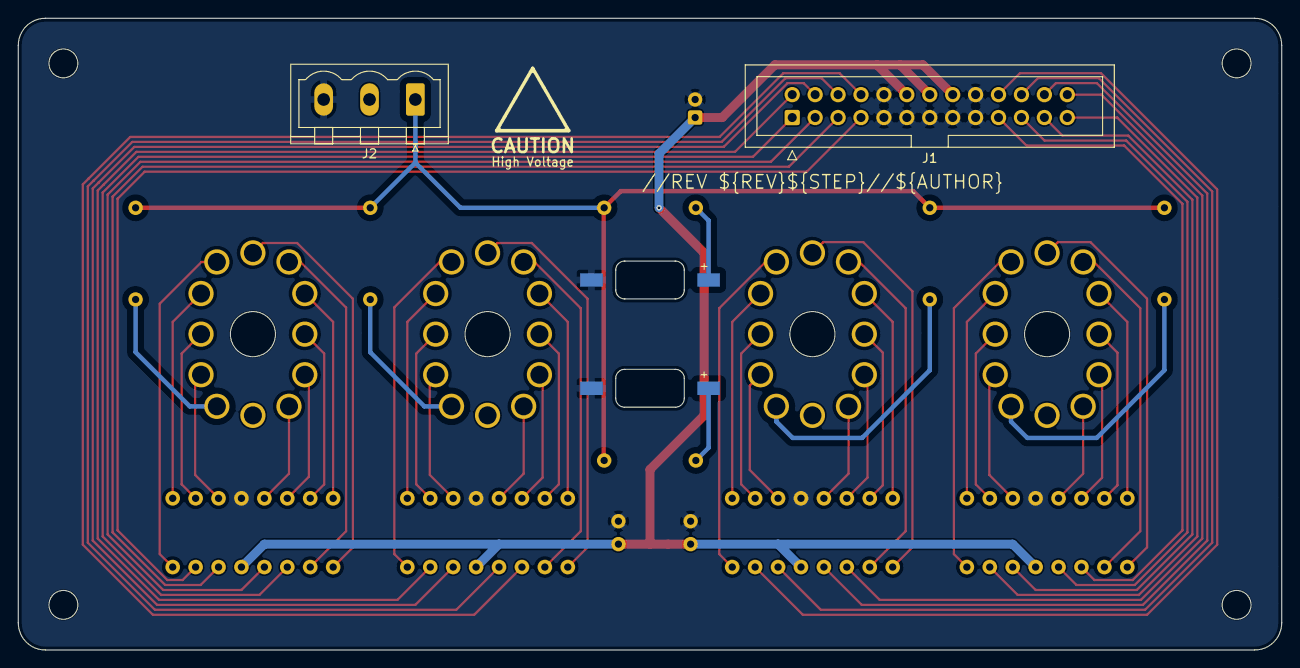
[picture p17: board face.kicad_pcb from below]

Board: 2 copper layers, 140.0 x 70.0 mm, 25 parts (2 on the bottom side), 65 nets.

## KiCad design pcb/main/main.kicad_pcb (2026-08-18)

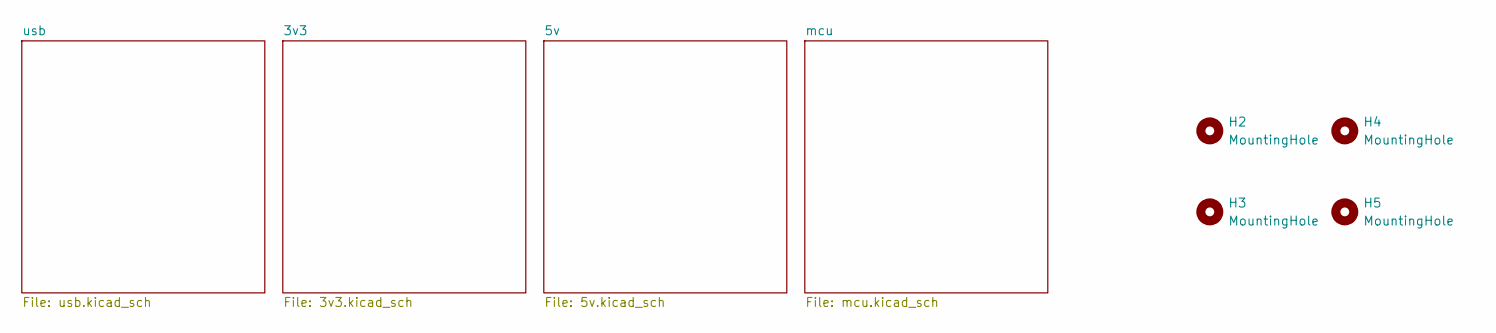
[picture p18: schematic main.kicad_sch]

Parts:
H2, H3, H4, H5: MountingHole; MountingHole_3.2mm_M3_ISO7380

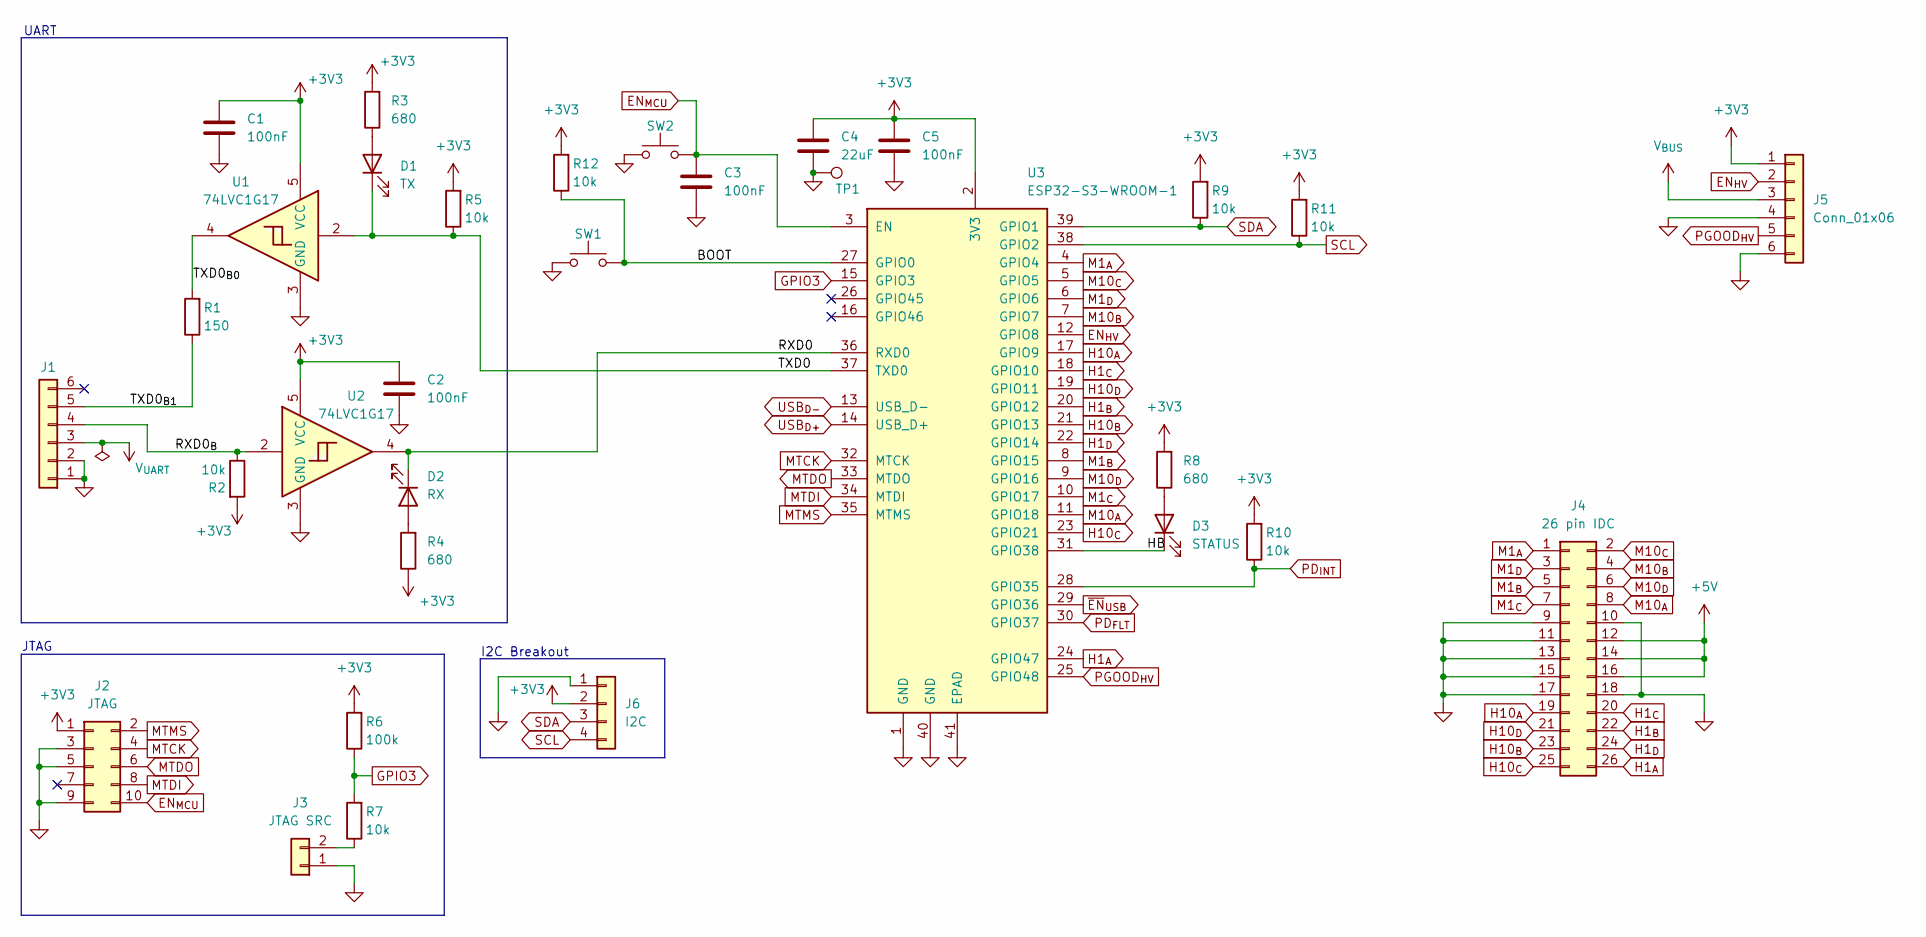
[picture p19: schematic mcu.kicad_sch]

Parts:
C1, C2, C3, C5: 100nF; C_0402_1005Metric; MFG Part No CL05B104KB54PNC; LCSC C307331
C4: 22uF; C_1206_3216Metric; MFG Part No CL31A226KPHNNNE; LCSC C5672
D1: TX; LED_0603_1608Metric; MFG Part No NCD0603Y2; LCSC C89811
D2: RX; LED_0603_1608Metric; MFG Part No NCD0603Y2; LCSC C89811
D3: STATUS; LED_0603_1608Metric; MFG Part No NCD0603Y2; LCSC C89811
J1: UART; PinHeader_1x06_P2.54mm_Vertical
J2: JTAG; Samtec_FTSH-105-01-L-DV-K_2x05_P1.27mm_Vertical_SMD; MFG Part No FTSH-105-01-L-DV-K
J3: JTAG SRC; PinHeader_1x02_P1.27mm_Vertical; MFG Part No M50-3530242
J4: 26 pin IDC; IDC-Header_2x13_P2.54mm_Vertical; MFG Part No 75869-105LF
J5: Conn_01x06; JST_XH_S6B-XH-A_1x06_P2.50mm_Horizontal; MFG Part No S6B-XH-A
J6: I2C; PinHeader_1x04_P2.54mm_Vertical
R1: 150; R_0402_1005Metric; MFG Part No RC0402JR-0710KL; LCSC C25082
R2, R9, R10, R11, R12: 10k; R_0402_1005Metric; MFG Part No RC0402JR-0710KL; LCSC C25744
R3, R4, R8: 680; R_0402_1005Metric; MFG Part No 0402WGF6800TCE; LCSC C25130
R5, R7: 10k; R_0402_1005Metric; MFG Part No 0402WGF1002TCE; LCSC C25744
R6: 100k; R_0402_1005Metric; MFG Part No RC0402FR-07100KL; LCSC C25741
SW1: Boot; SW_Panasonic_EVQ_4.9x4.9mm; MFG Part No EVQ-PT9A15
SW2: Reset; SW_Panasonic_EVQ_4.9x4.9mm; MFG Part No EVQ-PT9A15
TP1: GND; TestPoint_Pad_D1.0mm
U1, U2: 74LVC1G17; SOT-23-5; MFG Part No 74LVC1G17GV,125
U3: ESP32-S3-WROOM-1; MFG Part No ESP32-S3-WROOM-1-N8

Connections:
+3V3: C1.1, C2.1, C4.1, C5.1, J2.1, J5.1, J6.2, R2.2, R3.2, R4.1, R5.2, R6.2, R8.2, R9.2, R10.2, R11.2, R12.2, U1.5 (VCC), U2.5 (VCC), U3.2 (3V3); also elsewhere on the board
+5V: J4.12, J4.14, J4.16; also elsewhere on the board
/mcu/BOOT: R12.1, SW1.2, U3.27 (GPIO0)
/mcu/HB: D3.1 (K), U3.31 (GPIO38)
/mcu/RXD0: D2.1 (K), U2.4, U3.36 (RXD0)
/mcu/RXD0_{B}: J1.4, R2.1, U2.2
/mcu/TXD0: D1.1 (K), R5.1, U1.2, U3.37 (TXD0)
/mcu/TXD0_{B0}: R1.2, U1.4
/mcu/TXD0_{B1}: J1.5, R1.1
EN_{HV}: J5.2, U3.12 (GPIO8)
EN_{MCU}: C3.1, J2.10, SW2.2, U3.3 (EN); also elsewhere on the board
GND: C1.2, C2.2, C3.2, C4.2, C5.2, J1.1, J1.2, J2.3, J2.5, J2.9, J3.1, J4.9, J4.10, J4.11, J4.13, J4.15, J4.17, J4.18, J5.4, J5.6, J6.1, SW1.1, SW2.1, TP1.1 (1_1), U1.3 (GND), U2.3 (GND), U3.1 (GND), U3.40 (GND), U3.41 (EPAD); also elsewhere on the board
GPIO3: R6.1, R7.2, U3.15 (GPIO3)
H1_{A}: J4.26, U3.24 (GPIO47)
H1_{B}: J4.22, U3.20 (GPIO12)
H1_{C}: J4.20, U3.18 (GPIO10)
H1_{D}: J4.24, U3.22 (GPIO14)
H10_{A}: J4.19, U3.17 (GPIO9)
H10_{B}: J4.23, U3.21 (GPIO13)
H10_{C}: J4.25, U3.23 (GPIO21)
H10_{D}: J4.21, U3.19 (GPIO11)
M1_{A}: J4.1, U3.4 (GPIO4)
M1_{B}: J4.5, U3.8 (GPIO15)
M1_{C}: J4.7, U3.10 (GPIO17)
M1_{D}: J4.3, U3.6 (GPIO6)
M10_{A}: J4.8, U3.11 (GPIO18)
M10_{B}: J4.4, U3.7 (GPIO7)
M10_{C}: J4.2, U3.5 (GPIO5)
M10_{D}: J4.6, U3.9 (GPIO16)
MTCK: J2.4, U3.32 (MTCK)
MTDI: J2.8, U3.34 (MTDI)
MTDO: J2.6, U3.33 (MTDO)
MTMS: J2.2, U3.35 (MTMS)
unnamed: D1.2 (A), R3.1
unnamed: D2.2 (A), R4.2
unnamed: D3.2 (A), R8.1
unnamed: J3.2, R7.1
PD_{FLT}: U3.30 (GPIO37); also elsewhere on the board
PD_{INT}: R10.1, U3.28 (GPIO35); also elsewhere on the board
PGOOD_{HV}: J5.5, U3.25 (GPIO48)
SCL: J6.4, R11.1, U3.38 (GPIO2); also elsewhere on the board
SDA: J6.3, R9.1, U3.39 (GPIO1); also elsewhere on the board
USB_{D+}: U3.14 (USB_D+); also elsewhere on the board
USB_{D-}: U3.13 (USB_D-); also elsewhere on the board
V_{BUS}: J5.3; also elsewhere on the board
V_{UART}: J1.3; also elsewhere on the board
~EN_{USB}: U3.29 (GPIO36); also elsewhere on the board

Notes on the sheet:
JTAG
UART
I2C Breakout

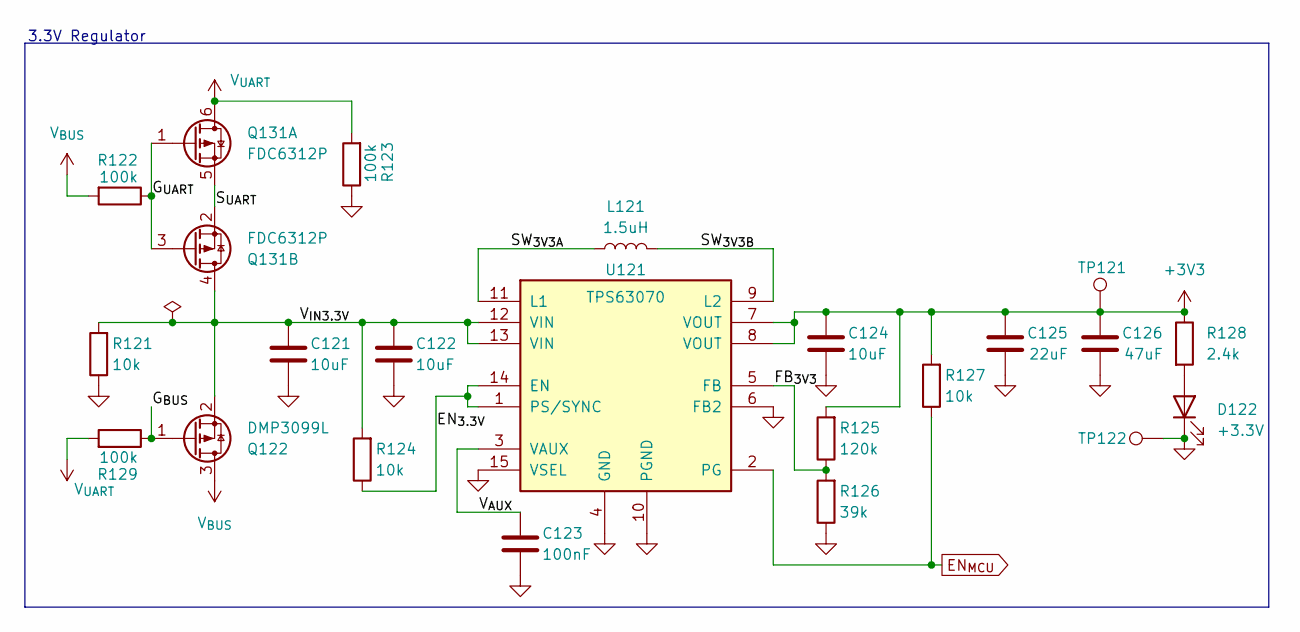
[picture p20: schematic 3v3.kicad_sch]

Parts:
C121: 10uF; C_0805_2012Metric; MFG Part No CL21A106KAYNNNE; LCSC C15850
C122: 10uF; C_0603_1608Metric; MFG Part No CL10A106MA8NRNC; LCSC C96446
C123: 100nF; C_0402_1005Metric; MFG Part No CL05B104KB54PNC; LCSC C1525
C124: 10uF; C_0402_1005Metric; MFG Part No CL05A106MQ5NUNC; LCSC C15525
C125: 22uF; C_1206_3216Metric; MFG Part No CL31A226KPHNNNE; LCSC C5672
C126: 47uF; C_1206_3216Metric; MFG Part No CL31A476MPHNNNE; LCSC C96123
D122: +3.3V; LED_0603_1608Metric; MFG Part No KT-0603R; LCSC C2286
L121: 1.5uH; L_Bourns_SRN5040TA; MFG Part No SRN5040TA-1R5M
Q122: DMP3099L; SOT-23-3; MFG Part No DMP3099L-13; LCSC C412516
Q131: FDC6312P; SOT-23-6; MFG Part No FDC6312P; LCSC C241767
R121, R124, R127: 10k; R_0402_1005Metric; MFG Part No 0402WGF1002TCE; LCSC C25744
R122, R129: 100k; R_0402_1005Metric; MFG Part No RC0402FR-07100KL; LCSC C25741
R123: 100k; R_0402_1005Metric; MFG Part No RC0402FR-07100KL; LCSC C60491
R125: 120k; R_0402_1005Metric; MFG Part No 0402WGF1203TCE; LCSC C25750
R126: 39k; R_0402_1005Metric; MFG Part No 0402WGF3902TCE; LCSC C25783
R128: 2.4k; R_0402_1005Metric; MFG Part No 0402WGF2401TCE; LCSC C25882
TP121: +3V3; TestPoint_Pad_D1.0mm
TP122: GND; TestPoint_Pad_D1.0mm
U121: TPS63070; VQFN-15_2.5x3mm_TI_RNM0015A; MFG Part No TPS630702RNMR

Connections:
+3V3: C124.1, C125.1, C126.1, R125.2, R127.2, R128.1, TP121.1 (1_1), U121.7 (VOUT), U121.8 (VOUT); also elsewhere on the board
/3v3/EN_{3.3V}: R124.1, U121.1 (PS/SYNC), U121.14 (EN)
/3v3/FB_{3V3}: R125.1, R126.2, U121.5 (FB)
/3v3/G_{BUS}: Q122.1 (G), R129.1
/3v3/G_{UART}: Q131.1 (G), Q131.3 (G), R122.1
/3v3/SW_{3V3A}: L121.1, U121.11 (L1)
/3v3/SW_{3V3B}: L121.2, U121.9 (L2)
/3v3/S_{UART}: Q131.2 (S), Q131.5 (S)
/3v3/V_{AUX}: C123.1, U121.3 (VAUX)
/3v3/V_{IN3.3V}: C121.1, C122.1, Q122.2 (S), Q131.4 (D), R121.2, R124.2, U121.12 (VIN), U121.13 (VIN)
EN_{MCU}: R127.1, U121.2 (PG); also elsewhere on the board
GND: C121.2, C122.2, C123.2, C124.2, C125.2, C126.2, D122.1 (K), R121.1, R123.1, R126.1, TP122.1 (1_1), U121.4 (GND), U121.6 (FB2), U121.10 (PGND), U121.15 (VSEL); also elsewhere on the board
unnamed: D122.2 (A), R128.2
V_{BUS}: Q122.3 (D), R122.2; also elsewhere on the board
V_{UART}: Q131.6 (D), R123.2, R129.2; also elsewhere on the board

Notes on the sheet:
3.3V Regulator

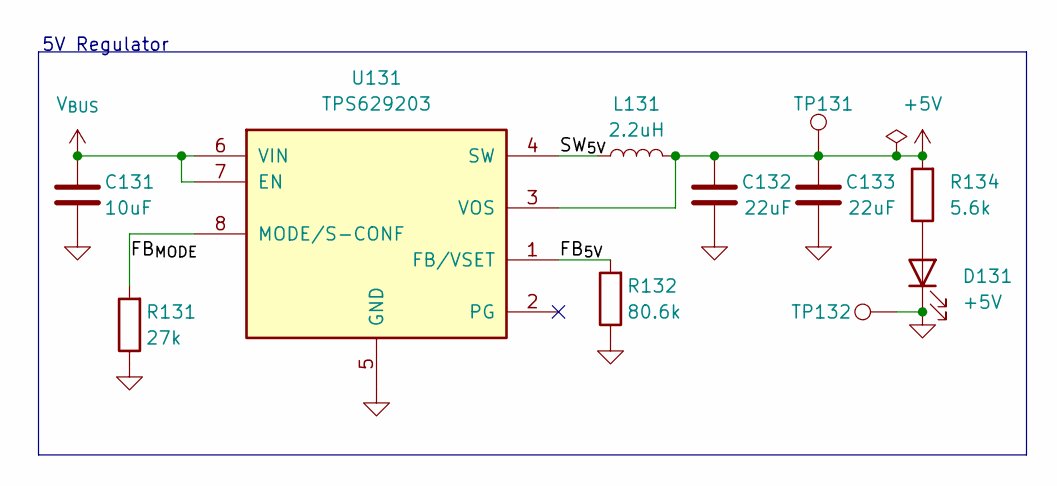
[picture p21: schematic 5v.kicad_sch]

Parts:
C131: 10uF; C_0805_2012Metric; MFG Part No CL21A106KAYNNNE; LCSC C15850
C132, C133: 22uF; C_1206_3216Metric; MFG Part No CL31A226KPHNNNE; LCSC C5672
D131: +5V; LED_0603_1608Metric; MFG Part No KT-0603R; LCSC C2286
L131: 2.2uH; L_Bourns_SRN5040TA; MFG Part No SRN5040TA-2R2M
R131: 27k; R_0402_1005Metric; MFG Part No 0402WGF2702TCE; LCSC C25771
R132: 80.6k; R_0402_1005Metric; MFG Part No RC0402FR-0780K6L; LCSC C155698
R134: 5.6k; R_0402_1005Metric; MFG Part No 0402WGF5601TCE; LCSC C25908
TP131: +5V; TestPoint_Pad_D1.0mm
TP132: GND; TestPoint_Pad_D1.0mm
U131: TPS629203; SOT-583-8; MFG Part No TPS629203DRLR

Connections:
+5V: C132.1, C133.1, L131.2, R134.2, TP131.1 (1_1), U131.3 (VOS); also elsewhere on the board
/5v/FB_{5V}: R132.2, U131.1 (FB/VSET)
/5v/FB_{MODE}: R131.2, U131.8 (MODE/S-CONF)
/5v/SW_{5V}: L131.1, U131.4 (SW)
GND: C131.2, C132.2, C133.2, D131.1 (K), R131.1, R132.1, TP132.1 (1_1), U131.5 (GND); also elsewhere on the board
unnamed: D131.2 (A), R134.1
V_{BUS}: C131.1, U131.6 (VIN), U131.7 (EN); also elsewhere on the board

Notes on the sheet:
5V Regulator

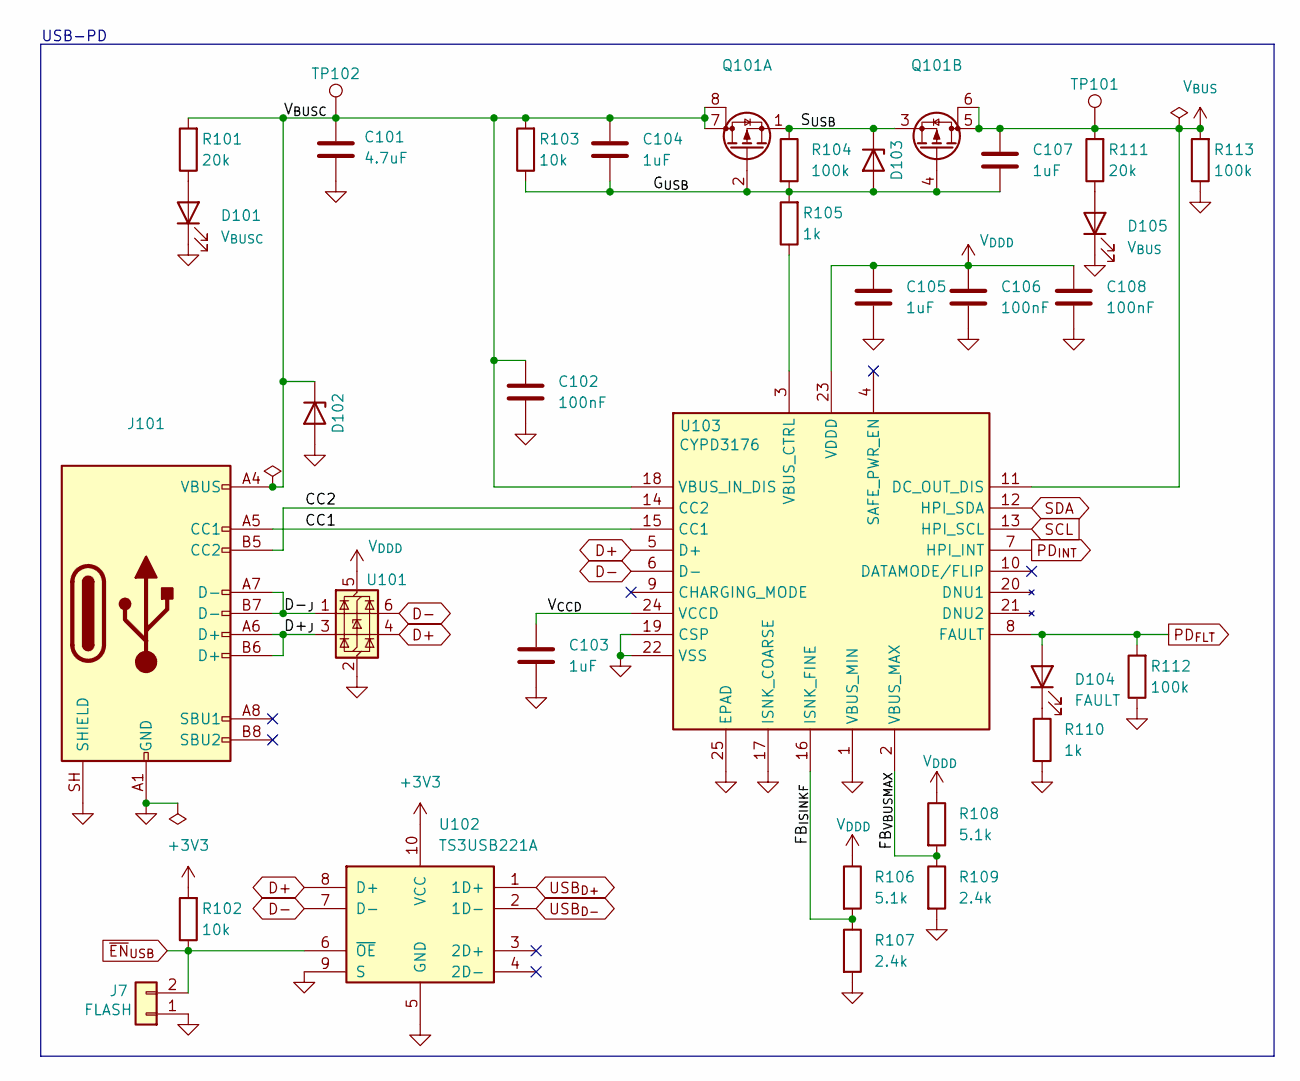
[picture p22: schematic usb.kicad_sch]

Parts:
C101: 4.7uF; C_0805_2012Metric; MFG Part No CL21A475KAQNNNE; LCSC C1779
C102, C106, C108: 100nF; C_0402_1005Metric; MFG Part No CL05B104KB54PNC; LCSC C307331
C103, C104, C105, C107: 1uF; C_0402_1005Metric; MFG Part No CL05A105KA5NQNC; LCSC C52923
D101: V_{BUSC}; LED_0603_1608Metric; MFG Part No KT-0603R; LCSC C2286
D102: SD15Q-7; D_SOD-323; MFG Part No SD15Q-7; LCSC C19950473
D103: MM3Z10VST1G; D_SOD-323_HandSoldering; MFG Part No MM3Z10VST1G
D104: FAULT; LED_0603_1608Metric; MFG Part No KT-0603R; LCSC C2286
D105: V_{BUS}; LED_0603_1608Metric; MFG Part No KT-0603R; LCSC C2286
J7: FLASH; PinHeader_1x02_P1.27mm_Vertical; MFG Part No M50-3530242
J101: USB_C_Receptacle_USB2.0_16P; USB_C_Receptacle_JAE_DX07S016JA1R1500; MFG Part No DX07S016JA1R1500; LCSC C3197885
Q101: FDS4935A; SOIC-8_3.9x4.9mm_P1.27mm; MFG Part No FDS4935A
R101, R111: 20k; R_0402_1005Metric; MFG Part No RC0402FR-0720KL; LCSC C25765
R102, R103: 10k; R_0402_1005Metric; MFG Part No RC0402JR-0710KL; LCSC C25744
R104, R113: 100k; R_0402_1005Metric; MFG Part No RC0402FR-07100KL; LCSC C25741
R105, R110: 1k; R_0402_1005Metric; MFG Part No 0402WGF1001TCE; LCSC C11702
R106, R108: 5.1k; R_0402_1005Metric; MFG Part No RC0402FR-075K1L; LCSC C25905
R107, R109: 2.4k; R_0402_1005Metric; MFG Part No 0402WGF2401TCE; LCSC C25882
R112: 100k; R_0402_1005Metric; MFG Part No 0402WGF1003TCE; LCSC C25741
TP101: V_{BUS}; TestPoint_Pad_D1.0mm
TP102: VBUS_{C}; TestPoint_Pad_D1.0mm
U101: USBLC6-2SC6; SOT-23-6; MFG Part No USBLC6-2SC6; LCSC C7519
U102: TS3USB221A; UQFN-10_1.5x2mm_P0.5mm_TI_RSE0010A; MFG Part No TS3USB221ARSER; LCSC C128396
U103: CYPD3176; QFN-24-1EP_4x4mm_P0.5mm_EP2.75x2.75mm_ThermalVias; MFG Part No CYPD3176-24LQXQ

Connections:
+3V3: R102.2, U102.10 (VCC); also elsewhere on the board
/usb/CC1: J101.A5 (CC1), U103.15 (CC1)
/usb/CC2: J101.B5 (CC2), U103.14 (CC2)
/usb/D+_{J}: J101.A6 (D+), J101.B6 (D+), U101.3 (I/O2)
/usb/D-_{J}: J101.A7 (D-), J101.B7 (D-), U101.1 (I/O1)
/usb/FB_{ISINKF}: R106.2, R107.1, U103.16 (ISNK_FINE)
/usb/FB_{VBUSMAX}: R108.2, R109.1, U103.2 (VBUS_MAX)
/usb/G_{USB}: C104.2, C107.2, D103.2 (A), Q101.2 (G), Q101.4 (G), R103.1, R104.2, R105.2
/usb/S_{USB}: D103.1 (K), Q101.1 (S), Q101.3 (S), R104.1
/usb/V_{BUSC}: C101.1, C102.1, C104.1, D102.1 (K), J101.A4 (VBUS), J101.A9 (VBUS), J101.B4 (VBUS), J101.B9 (VBUS), Q101.7 (D), Q101.8 (D), R101.2, R103.2, TP102.1 (1_1), U103.18 (VBUS_IN_DIS)
/usb/V_{CCD}: C103.1, U103.24 (VCCD)
D+: U101.4 (I/O2), U102.8 (D+), U103.5 (D+)
D-: U101.6 (I/O1), U102.7 (D-), U103.6 (D-)
GND: C101.2, C102.2, C103.2, C105.2, C106.2, C108.2, D101.1 (K), D102.2 (A), D105.1 (K), J7.1, J101.A1 (GND), J101.A12 (GND), J101.B1 (GND), J101.B12 (GND), J101.SH (SHIELD), R107.2, R109.2, R110.2, R112.1, R113.1, U101.2 (GND), U102.5 (GND), U102.9 (S), U103.1 (VBUS_MIN), U103.17 (ISNK_COARSE), U103.19 (CSP), U103.22 (VSS), U103.25 (EPAD); also elsewhere on the board
unnamed: D101.2 (A), R101.1
unnamed: D104.1 (K), R110.1
unnamed: D105.2 (A), R111.1
unnamed: R105.1, U103.3 (VBUS_CTRL)
PD_{FLT}: D104.2 (A), R112.2, U103.8 (FAULT); also elsewhere on the board
PD_{INT}: U103.7 (HPI_INT); also elsewhere on the board
SCL: U103.13 (HPI_SCL); also elsewhere on the board
SDA: U103.12 (HPI_SDA); also elsewhere on the board
USB_{D+}: U102.1 (1D+); also elsewhere on the board
USB_{D-}: U102.2 (1D-); also elsewhere on the board
V_{BUS}: C107.1, Q101.5 (D), Q101.6 (D), R111.2, R113.2, TP101.1 (1_1), U103.11 (DC_OUT_DIS); also elsewhere on the board
V_{DDD}: C105.1, C106.1, C108.1, R106.1, R108.1, U101.5 (VBUS), U103.23 (VDDD)
~EN_{USB}: J7.2, R102.1, U102.6 (~OE); also elsewhere on the board

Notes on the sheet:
USB-PD

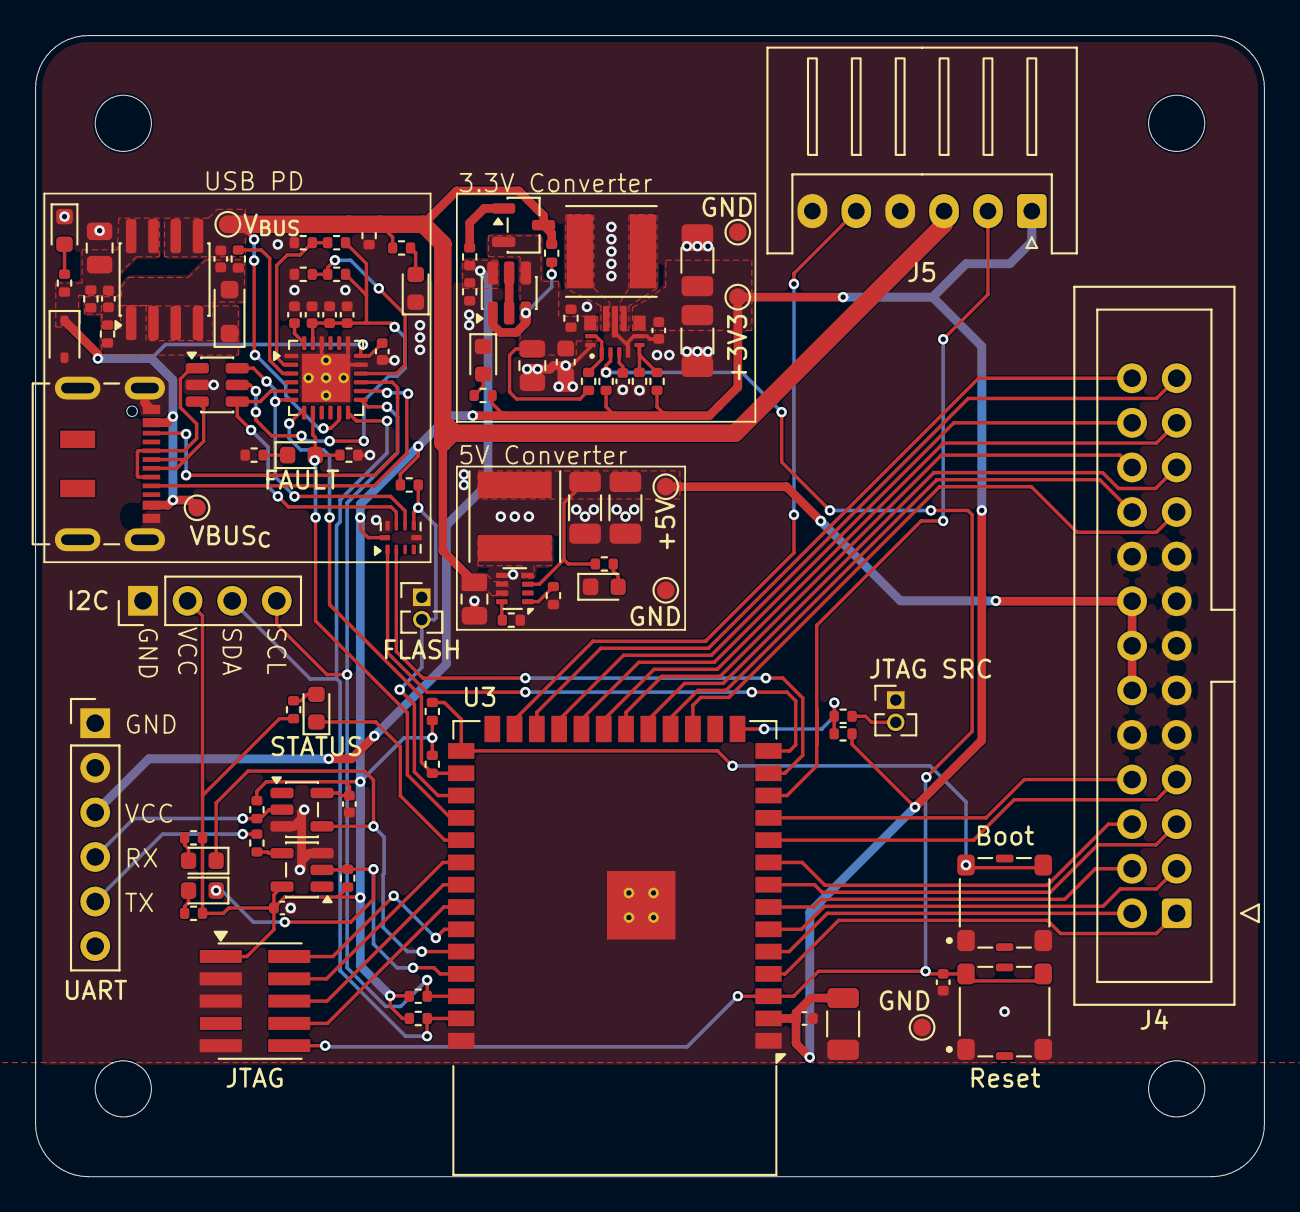
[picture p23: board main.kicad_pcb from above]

Board: 2 copper layers, 70.0 x 65.0 mm, 103 parts (0 on the bottom side), 78 nets.

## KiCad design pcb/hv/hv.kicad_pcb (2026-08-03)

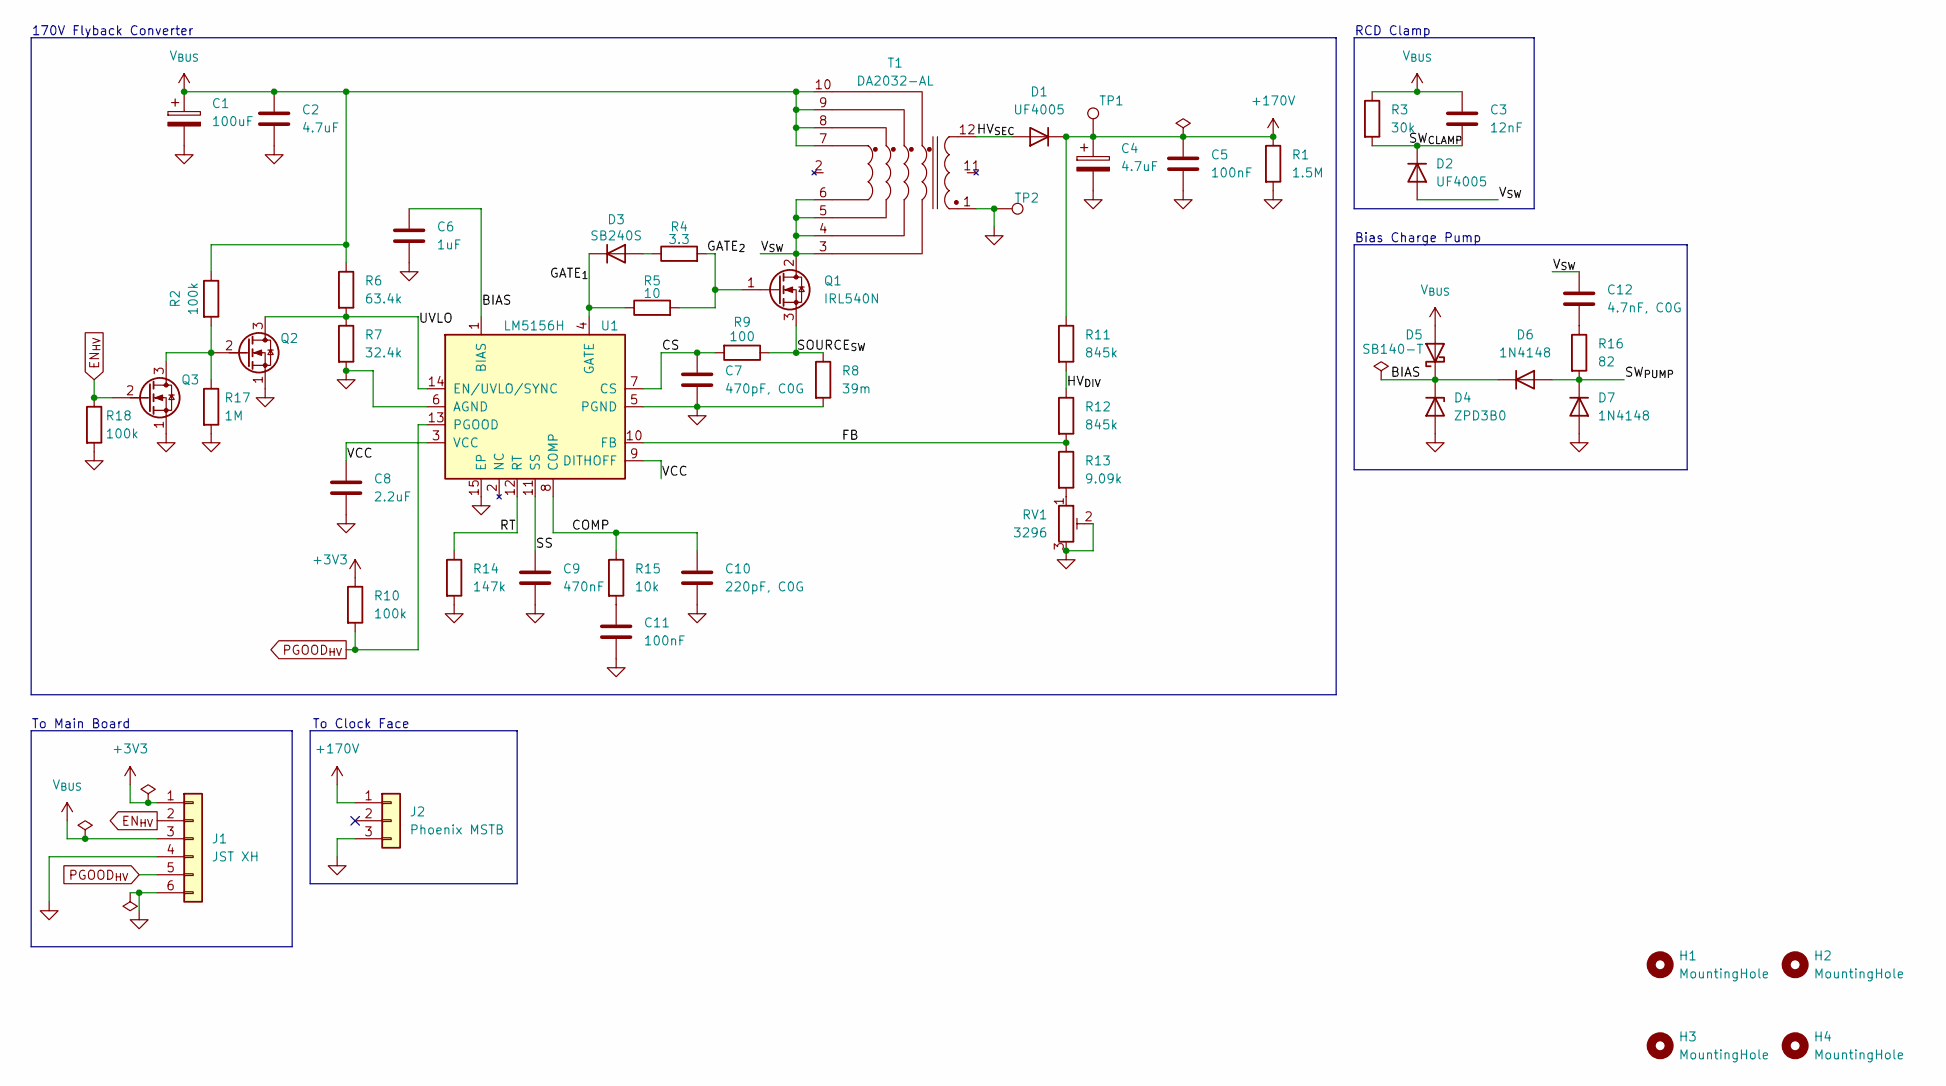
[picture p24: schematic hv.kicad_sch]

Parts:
C1: 100uF; CP_Radial_D8.0mm_P3.50mm; MFG Part No A750KK107M1EAAE040
C2: 4.7uF; C_Rect_L5.1mm_W3.2mm_P5.08mm_Goldmax; MFG Part No C322C475K5R5TA
C3: 12nF; C_Rect_L7.2mm_W2.5mm_P5.00mm_PHE426; MFG Part No PHE426DJ5120JR05
C4: 4.7uF; CP_Radial_D8.0mm_P3.50mm; MFG Part No A759KS475M2EAAE496
C5: 100nF; C_Rect_L7.9mm_W5.9mm_P5.00mm_ECQE; MFG Part No ECQ-E2104KB
C6: 1uF; C_Rect_L7.1mm_W4.1mm_P5.08mm_Goldmax; MFG Part No C330C105K5R5TA7303
C7: 470pF, C0G; C_Rect_L3.8mm_W2.5mm_P2.54mm_Goldmax; MFG Part No C315C471J1G5TA
C8: 2.2uF; C_Axial_L5.1mm_D3.1mm_P7.50mm_Horizontal; MFG Part No C410C225K3R5TA
C9: 470nF; C_Rect_L5.1mm_W3.2mm_P5.08mm_Goldmax; MFG Part No C322C474K5R5TA7301
C10: 220pF, C0G; C_Rect_L5.1mm_W3.2mm_P5.08mm_Goldmax; MFG Part No C322C221J2G5TA
C11: 100nF; C_Rect_L5.1mm_W3.2mm_P5.08mm_Goldmax; MFG Part No C322C104K5R5TA
C12: 4.7nF, C0G; C_Rect_L3.8mm_W2.5mm_P2.54mm_Goldmax; MFG Part No C315C472J2G5TA
D1: UF4005; D_DO-41_SOD81_P10.16mm_Horizontal; MFG Part No UF4005
D2: UF4005; D_DO-41_SOD81_P7.62mm_Horizontal; MFG Part No UF4005
D3: SB240S; D_DO-41_SOD81_P7.62mm_Horizontal; MFG Part No SB240S-E3/54
D4: ZPD3B0; D_DO-35_SOD27_P7.62mm_Horizontal; MFG Part No ZPD3B0
D5: SB140-T; D_DO-41_SOD81_P7.62mm_Horizontal; MFG Part No SB140-T
D6, D7: 1N4148; D_DO-35_SOD27_P7.62mm_Horizontal; MFG Part No 1N4148TR
H1, H2, H3, H4: MountingHole; MountingHole_3.2mm_M3_ISO7380
J1: JST XH; JST_XH_S6B-XH-A_1x06_P2.50mm_Horizontal; MFG Part No S6B-XH-A
J2: Phoenix MSTB; PhoenixContact_MSTBA_2,5_3-G-5,08_1x03_P5.08mm_Horizontal; MFG Part No 1757255
Q1: IRL540N; TO-220-3_Vertical; MFG Part No IRL540NPBF
Q2, Q3: TN2106N3-G; TO-92L; MFG Part No TN2106N3-G
R1: 1.5M; R_Axial_DIN0309_L9.0mm_D3.2mm_P12.70mm_Horizontal; MFG Part No CFR-50JB-52-1M5
R2, R10, R18: 100k; R_Axial_DIN0204_L3.6mm_D1.6mm_P5.08mm_Horizontal; MFG Part No CFR-12JB-52-100K
R3: 30k; R_Axial_DIN0207_L6.3mm_D2.5mm_P7.62mm_Horizontal; MFG Part No CFR-25JB-52-30K
R4: 3.3; R_Axial_DIN0204_L3.6mm_D1.6mm_P5.08mm_Horizontal; MFG Part No CFR-12JB-52-3R3
R5: 10; R_Axial_DIN0204_L3.6mm_D1.6mm_P5.08mm_Horizontal; MFG Part No CFR25SJT-52-10R
R6: 63.4k; R_Axial_DIN0207_L6.3mm_D2.5mm_P7.62mm_Horizontal; MFG Part No MFR-25FRF52-63K4
R7: 32.4k; R_Axial_DIN0207_L6.3mm_D2.5mm_P7.62mm_Horizontal; MFG Part No MFR-25FRF52-32K4
R8: 39m; R_2512_6332Metric_Pad1.40x3.35mm_HandSolder; MFG Part No TLRP3A20WR039FTE
R9: 100; R_Axial_DIN0204_L3.6mm_D1.6mm_P5.08mm_Horizontal; MFG Part No CFR25SJT-52-100R
R11, R12: 845k; R_Axial_DIN0207_L6.3mm_D2.5mm_P7.62mm_Horizontal; MFG Part No MFR-25FBF52-845K
R13: 9.09k; R_Axial_DIN0207_L6.3mm_D2.5mm_P7.62mm_Horizontal; MFG Part No MFR-25FBF52-9K09
R14: 147k; R_Axial_DIN0207_L6.3mm_D2.5mm_P7.62mm_Horizontal; MFG Part No MFR-25FRF52-147K
R15: 10k; R_Axial_DIN0204_L3.6mm_D1.6mm_P5.08mm_Horizontal; MFG Part No CFR-12JB-52-10K
R16: 82; R_Axial_DIN0309_L9.0mm_D3.2mm_P12.70mm_Horizontal; MFG Part No CFR-50JB-52-82R
R17: 1M; R_Axial_DIN0204_L3.6mm_D1.6mm_P5.08mm_Horizontal; MFG Part No CFR-12JB-52-1M
RV1: 3296; Potentiometer_Bourns_3296W_Vertical; MFG Part No 3296W-1-202LF
T1: DA2032-AL; MFG Part No DA2032-AL
TP1: +170V; TestPoint_Keystone_5000-5004_Miniature; MFG Part No 5001
TP2: GND; TestPoint_Keystone_5000-5004_Miniature; MFG Part No 5000
U1: LM5156H; Texas_HTSSOP-14-1EP_4.4x5mm_P0.65mm_EP3.4x5mm_Mask3.155x3.2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; MFG Part No LM51561HPWPR

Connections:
+3V3: J1.1, R10.1
+170V: C4.1, C5.1, D1.1 (K), J2.1, R1.1, R11.1, TP1.1 (1_1)
/BIAS: C6.2, D4.1 (K), D5.1 (K), D6.1 (K), U1.1 (BIAS)
/COMP: C10.2, R15.1, U1.8 (COMP)
/CS: C7.2, R9.2, U1.7 (CS)
/FB: R12.2, R13.1, U1.10 (FB)
/GATE_{1}: D3.1 (K), R5.1, U1.4 (GATE)
/GATE_{2}: Q1.1 (G), R4.2, R5.2
/HV_{DIV}: R11.2, R12.1
/HV_{SEC}: D1.2 (A), T1.12
/RT: R14.1, U1.12 (RT)
/SOURCE_{SW}: Q1.3 (S), R8.1, R9.1
/SS: C9.2, U1.11 (SS)
/SW_{CLAMP}: C3.1, D2.1 (K), R3.2
/SW_{PUMP}: D6.2 (A), D7.1 (K), R16.2
/UVLO: Q2.3 (D), R6.2, R7.1, U1.14 (EN/UVLO/SYNC)
/VCC: C8.2, U1.3 (VCC), U1.9 (DITHOFF)
/V_{SW}: C12.1, D2.2 (A), Q1.2 (D), T1.3, T1.4, T1.5, T1.6
EN_{HV}: J1.2, Q3.2 (G), R18.1
GND: C1.2, C2.2, C4.2, C5.2, C6.1, C7.1, C8.1, C9.1, C10.1, C11.1, D4.2 (A), D7.2 (A), J1.4, J1.6, J2.3, Q2.1 (S), Q3.1 (S), R1.2, R7.2, R8.2, R14.2, R17.2, R18.2, RV1.2, RV1.3, T1.1, TP2.1 (1_1), U1.5 (PGND), U1.6 (AGND), U1.15 (EP)
unnamed: C11.2, R15.2
unnamed: C12.2, R16.1
unnamed: D3.2 (A), R4.1
unnamed: Q2.2 (G), Q3.3 (D), R2.2, R17.1
unnamed: R13.2, RV1.1
PGOOD_{HV}: J1.5, R10.2, U1.13 (PGOOD)
V_{BUS}: C1.1, C2.1, C3.2, D5.2 (A), J1.3, R2.1, R3.1, R6.1, T1.7, T1.8, T1.9, T1.10

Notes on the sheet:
To Main Board
To Clock Face
Bias Charge Pump
RCD Clamp
170V Flyback Converter

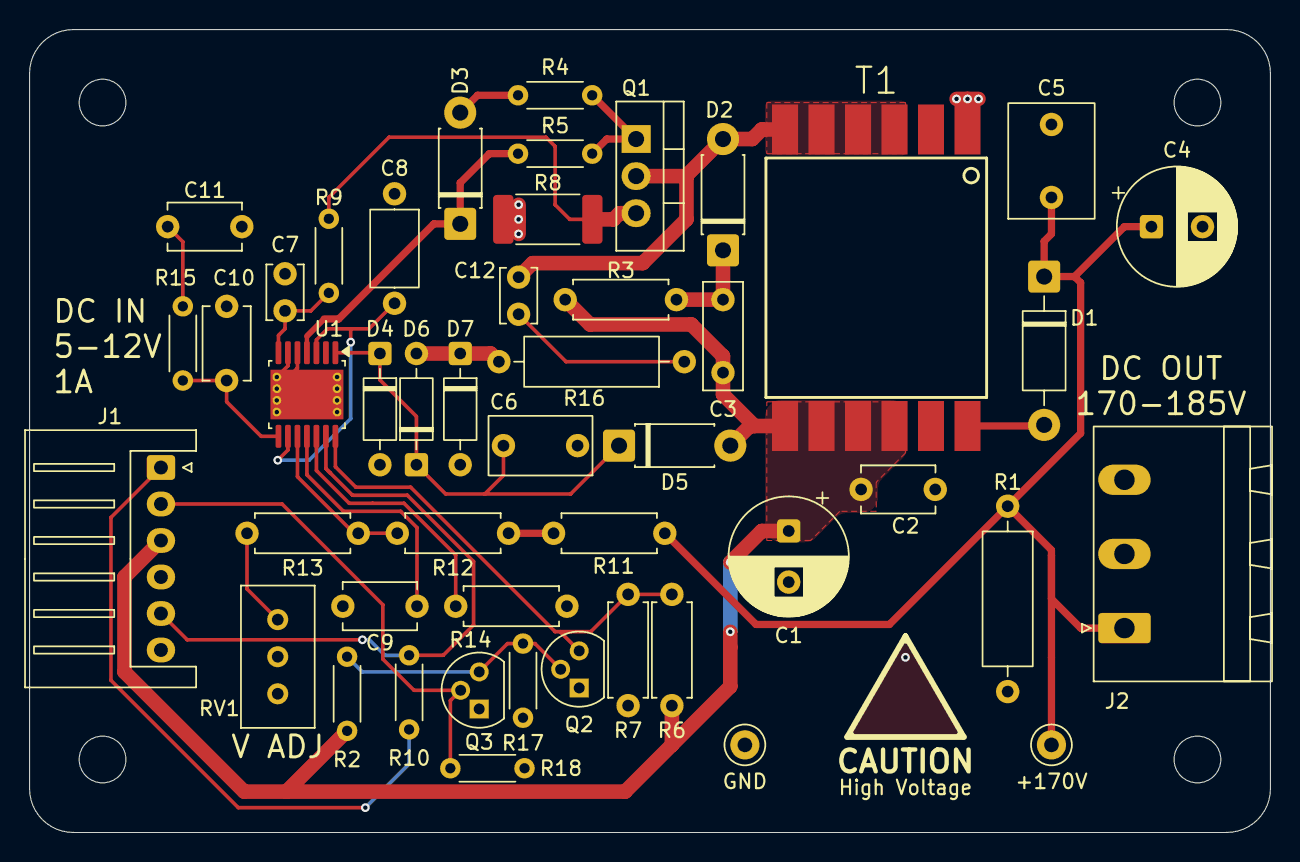
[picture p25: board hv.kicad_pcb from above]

Board: 2 copper layers, 85.0 x 55.0 mm, 51 parts (0 on the bottom side), 27 nets.

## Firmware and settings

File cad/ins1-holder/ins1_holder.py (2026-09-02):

"""INS-1 holder - a rigid collar, printed in PETG, that steadies the two colon lamps.

The recessed footprint seats each lamp on the edge of a milled slot and nothing
above the board holds it: 18 mm of glass stands on a 4.2 mm wide seat. This
part is glued to the front of the board over both lamps and takes the side
loads. It slides down over the lamps after they are soldered, so every opening
in it passes the barrel and the dome, and nothing in it touches the pinch or
the shoulder.

Frame: the FaceBoard VarSet frame. Origin midway between the two lamps on the
board's front face; X along the board (the pinch blade's wide axis, and the
direction of the IN-12 neighbours), Y up the board (the lamps sit at
+-PITCH/2), Z the lamp axis out of the board. The lamp's own frame has its
origin at the exhaust pip and the lamp seats where its section first fills the
slot, so lamp z = holder z + Z_BOARD with Z_BOARD = ins1.seat_height(). The
frame is also the print orientation: plate on the bed, bores vertical.

    plate     rounded rectangle, the glue face, cornered like the slots
    collar    over both lamps, waisted between them: two circles joined by
              concave arcs tangent to both; its top edge is a ruled loft to
              an inset outline, a chamfer with no chamfer operation
    per lamp  counterbore over the shoulder, bore over the barrel, four crush
              ribs standing proud of the bore, a lead-in cone at the mouth

Fits are for a hard plastic. The bore clears the barrel by BORE_CLEAR a side;
the ribs are what touch the glass, and they are 0.8 wide so a slicer keeps
them. The tubes in hand measure TUBE_D_MEASURED across the barrel, wider than
the model's 6.50 and spread by 0.03, and the ribs crush to take up that
spread and whatever the printer adds to it. FITS lists the
variants, one STL each, and each names the press it wants on the smallest
tube as printed; the rib diameter is drawn from that, PRINT_UNDER larger,
because a printed bore comes out that much under its drawing. The report
states the press on the largest tube too. The counterbore clears the 7.00 wide
blade section by SHOULDER_CLEAR a side over the height where the section is
wider than the barrel, and runs a little past it.

Sources: the lamp's sections and seat from ins1.py, measured off the vendor
model; the slot from washer.py, which took it from the INS-1_Recessed
footprint; the lamp pitch and the IN-12 positions from the face board through
boards.py. The footprint's 3D model offset (-9.74) assumed a 0.85 washer under
the lamp; without one the lamp sits at the slot's own seat, 10.59, and that is
what this part is built to.

The tall variant
----------------

holder_tall() lifts the lamps so that only the pip and the leads pass the
board: the flat underside of the press stands on the holder's floor, T_PLATE_T
above the board, and the floor is pierced only for the dia 3.00 pip and the two
leads. The lens then stands T_LENS above the board rather than Z_APEX - Z_BOARD.
Nothing seats in the slot, so the slot's corners are free, and four tabs under
the plate key the holder into them, clear of the pip and the leads.

The tube goes in leads first from the top, with the blade along X as the slot
will demand anyway. That sets two things: the bore is drawn to pass the blade's
flank corners, T_BLADE_CLEAR a side as printed, so the ribs stand taller than
in the short variant; and the ribs sit at 45 deg, where the blade's outline is
2.7 from the axis and never near them. Below the ribs the cavity is a plain
cylinder T_CAVITY_CLEAR clear of those corners: nothing there touches glass.
The ribs are the same FITS as the short variant and are all that holds the
tube up; the floor is what holds it down.

Run headless to build, report and write the STLs for the slicer, one per
variant and fit:

    python .claude/skills/freecad/scripts/fc_tool.py run cad/ins1-holder/ins1_holder.py

In the GUI, build() shows a holder over both lamps and a stub of board;
build(variant="tall") the tall one.
"""

import importlib
import math
import os
import sys
from typing import NamedTuple

import FreeCAD as App
import Part

HERE = os.path.dirname(os.path.abspath(__file__))
CAD = os.path.normpath(os.path.join(HERE, ".."))
for _sub in ("ins1", "case"):
    _path = os.path.join(CAD, _sub)
    if _path not in sys.path:
        sys.path.insert(0, _path)
import ins1 as G  # noqa: E402
import washer as W  # noqa: E402  (the slot, and rounded_rect)
import boards  # noqa: E402

# A reload of this module in the GUI does not reload these.
importlib.reload(G)
importlib.reload(W)
importlib.reload(boards)

try:
    from FreeCAD import Gui
except ImportError:
    Gui = None

DOC_NAME = "INS1_Holder"

# --- the board, through boards.py (pcb/face/face.kicad_pcb) --------------
_FACE = boards.board_values(boards.BOARDS["face"])
_ENV = boards.envelope_values()
LAMP_Y = (_FACE["colon1_y"], _FACE["colon2_y"])  # upper first: +6.00, -6.00
PITCH = LAMP_Y[0] - LAMP_Y[1]  # 12.00
IN12_X = min(
    abs(_FACE["tube2_x"]), abs(_FACE["tube3_x"])
)  # 18.00, the nearest digit's axis
IN12_R = _ENV["tube_w"] / 2  # 10.50, the digit's stadium end radius (in12.BODY_X)
IN12_STRAIGHT = (
    _ENV["tube_h"] - _ENV["tube_w"]
)  # 10.00, its straight run (in12.BODY_Y - BODY_X)
BOARD_T = _FACE["board_t"]  # 1.60
SLOT_W, SLOT_H, SLOT_R = W.SLOT_W, W.SLOT_H, W.SLOT_R  # 7.60 x 4.20, R1.00

# --- the lamp, from ins1.py ------------------------------------------------
Z_BOARD = G.seat_height()  # 10.59, the board's front face in the lamp frame
TUBE_D_MEASURED = (6.57, 6.60)  # calipers across six barrels, smallest and largest; one
#                                 tube at 6.70 was a clear outlier and is left out
TUBE_D_OVER = sum(TUBE_D_MEASURED) / 2 - 2 * G.BARREL_R  # 0.135 over the model's 6.50
BARREL_R = G.BARREL_R + TUBE_D_OVER / 2  # 3.3175, the mean tube; sizes the bore and collar
PRINT_UNDER = 0.15  # a printed bore under its drawing, on the diameter. Ribs drawn at
#                     6.60 were a hard press on the 6.57 tube, which puts them near
#                     6.45 as printed; refine from the next pair
PRESS_HALF = G.PRESS_W  # 3.50, half of the 7.00 blade
Z_ROUND = G.Z_SHOULDER_END - Z_BOARD  # 1.01, section is the round barrel above here
Z_NARROW = (
    G.Z_W_BAND_END - Z_BOARD
)  # 0.67, section is no wider than the barrel above here
Z_APEX = G.Z_APEX - Z_BOARD  # 18.01, the lens

# --- fits, per side, for PETG ---------------------------------------------
BORE_CLEAR = 0.25  # bore radius over the barrel; the tube never rides on the bore


class Fit(NamedTuple):
    """The press wanted on the smallest measured tube, per side, as printed:
    positive is interference, zero a slip. Larger tubes press harder by half
    their extra diameter, and the ribs crush to take it."""

    press_min: float
    note: str


# Names are for the slicer's file list.
FITS = {
    "close": Fit(0.03, "0.03 a side on the smallest tube, 0.045 on the largest; printed good"),
    "loose": Fit(0.015, "0.015 a side on the smallest tube; a slip at 0.00 printed with no grip"),
}
RIB_W = 0.80  # two extrusion lines; a 0.4 rib is one line and slicers drop it
RIB_N = 4
RIB_ANGLE0 = 45.0  # first rib, off the X axis; the section is round where they are
SHOULDER_CLEAR = 0.30  # counterbore radius over the 7.00 blade width
SHOULDER_MARGIN = 0.30  # counterbore runs this far above Z_ROUND

# --- the part --------------------------------------------------------------
PLATE_W = 12.60  # across X; the IN-12 glass is at 7.55 either side, see _report
PLATE_R = (
    4.00  # corner radius; the slots are R1.00 on 4.20, this is the same look at 12.60
)
PLATE_T = 2.00
COLLAR_D = 10.40  # round the lamps: bore 7.00 plus a 1.70 wall
WAIST_W = 5.00  # across X between the lamps; the concave arcs never come nearer a
#                 bore than the collar wall does, see _report
HEIGHT = 9.00  # above the board; the lens stands 9.0 clear of it
TOP_CHAMFER = 0.60
BORE_LEAD = 0.50  # 45 deg mouth, so the dome finds the bore
RIB_MARGIN = 0.40  # ribs stop this short of the counterbore and the mouth
RIB_BURY = 0.30  # ribs reach this far into the wall, so the fuse has something to hold
OVER = 0.01  # cutters run past the faces they open on

R_BORE = BARREL_R + BORE_CLEAR  # 3.60
R_CBORE = PRESS_HALF + SHOULDER_CLEAR  # 3.80
Z_CBORE = Z_ROUND + SHOULDER_MARGIN  # 1.31
PLATE_L = PITCH + PLATE_W  # along Y
RIB_Z0 = Z_CBORE + RIB_MARGIN
RIB_Z1 = HEIGHT - BORE_LEAD - RIB_MARGIN


def r_rib(fit: Fit) -> float:
    """Radius of the rib faces as drawn: the smallest tube less the press, plus
    what the printer takes off, all on the diameter."""
    return (TUBE_D_MEASURED[0] - 2 * fit.press_min + PRINT_UNDER) / 2


def press_on(fit: Fit, tube_d: float) -> float:
    """Interference per side on a tube of diameter tube_d, as printed; negative is clearance."""
    return (tube_d - (2 * r_rib(fit) - PRINT_UNDER)) / 2


# --- the tall variant -------------------------------------------------------
def _blade_points() -> list:
    """The blade's outline at the press, as (angle deg, radius) about the lamp axis."""
    out = []
    for p in G.press_outline(0.0).discretize(Distance=0.02):
        out.append((math.degrees(math.atan2(p.y, p.x)) % 360.0, math.hypot(p.x, p.y)))
    return out


_BLADE = _blade_points()
BLADE_R_MAX = max(r for _, r in _BLADE)  # 3.65, the flank corners; what the bore must pass


def blade_r_near(angle: float, half_span: float) -> float:
    """The blade's greatest radius within half_span degrees of angle: what a rib there meets."""
    return max((r for a, r in _BLADE if abs((a - angle + 180.0) % 360.0 - 180.0) <= half_span),
               default=0.0)


T_PLATE_T = 1.60  # floor; the press's flat underside stands on its top face
T_LAMP_Z0 = G.Z_FACE - T_PLATE_T  # 3.00: lamp z at the board's front face
T_LENS = G.Z_APEX - T_LAMP_Z0  # 25.60 above the board
T_PIP_CLEAR = 0.30  # floor hole over the dia 3.00 pip, per side
T_LEAD_CLEAR = 0.45  # floor slot over the dia 0.50 leads, per side and past their ends
T_BLADE_CLEAR = 0.30  # bore over the blade's corners, per side, as printed; the tube goes
#                       in blade first and the corners are the vendor model's, not measured
T_CAVITY_CLEAR = 0.55  # cavity radius over the blade's corners; nothing touches down there
T_COLLAR_D = 11.00  # wider than the short variant's, for the wall round the cavity
T_RIB_LEN = 6.00  # grip on the barrel
T_TAB_DEPTH = 1.20  # into the 1.60 board
T_TAB_FIT = 0.15  # tab to the milled slot, per side
T_TAB_CLEAR = 0.45  # tab to a lead's surface, and to the pip's

T_R_PIP_HOLE = G.R_PIP + T_PIP_CLEAR  # 1.80
T_LEAD_SLOT_L = 2 * (G.LEAD_PITCH / 2 + G.LEAD_R + T_LEAD_CLEAR)  # 6.90
T_LEAD_SLOT_W = 2 * (G.LEAD_R + T_LEAD_CLEAR)  # 1.40
T_R_BORE = BLADE_R_MAX + T_BLADE_CLEAR + PRINT_UNDER / 2  # 3.92 drawn
T_R_CAVITY = BLADE_R_MAX + T_CAVITY_CLEAR  # 4.20
T_Z_CAVITY_TOP = G.Z_SHOULDER_END - T_LAMP_Z0  # 8.60, the section is round above here
T_RIB_Z0 = T_Z_CAVITY_TOP + RIB_MARGIN
T_RIB_Z1 = T_RIB_Z0 + T_RIB_LEN
T_HEIGHT = T_RIB_Z1 + RIB_MARGIN + BORE_LEAD  # 15.90
T_TAB_Y0 = G.LEAD_R + T_TAB_CLEAR  # 0.70, the tab's inner edge, off the lead
T_TAB_X0 = math.sqrt((G.R_PIP + T_TAB_CLEAR) ** 2 - T_TAB_Y0 ** 2)  # 1.82, off the pip


def rib_stand(fit: Fit) -> float:
    """How far the ribs stand proud of the bore; the 45 deg ramps are this long too."""
    return R_BORE - r_rib(fit)


# =========================================================================
# outlines
# =========================================================================
def _v(x, y, z):
    return App.Vector(x, y, z)


class Peanut:
    """Two circles of radius R about (0, +-c), joined by concave arcs of radius r
    about (+-d, 0) tangent to both, so the outline is w wide at the waist.

    From w: (d, 0) is R + r from (0, c) and d = w/2 + r, which gives r. Offsetting
    the outline inward by t keeps every centre, shrinks R by t and grows r by t,
    so one class describes the collar and its chamfer's top.
    """

    def __init__(self, big_r: float, waist_w: float, pitch: float):
        self.R = big_r
        self.c = pitch / 2
        w = waist_w / 2
        self.r = (w * w + self.c**2 - big_r**2) / (2 * (big_r - w))
        self.d = w + self.r
        # tangent point in the first quadrant: on the upper circle, toward (d, 0)
        ux, uy = self.d, -self.c
        norm = math.hypot(ux, uy)
        self.tx, self.ty = big_r * ux / norm, self.c + big_r * uy / norm

    def inset(self, t: float) -> "Peanut":
        p = Peanut.__new__(Peanut)
        p.R, p.c, p.r, p.d = self.R - t, self.c, self.r + t, self.d
        ux, uy = p.d, -p.c
        norm = math.hypot(ux, uy)
        p.tx, p.ty = p.R * ux / norm, p.c + p.R * uy / norm
        return p

    @property
    def waist(self) -> float:
        return 2 * (self.d - self.r)

    def wire(self, z: float) -> Part.Wire:
        R, c, r, d, tx, ty = self.R, self.c, self.r, self.d, self.tx, self.ty
        edges = [
            Part.Arc(_v(tx, ty, z), _v(0, c + R, z), _v(-tx, ty, z)).toShape(),
            Part.Arc(_v(-tx, ty, z), _v(-(d - r), 0, z), _v(-tx, -ty, z)).toShape(),
            Part.Arc(_v(-tx, -ty, z), _v(0, -c - R, z), _v(tx, -ty, z)).toShape(),
            Part.Arc(_v(tx, -ty, z), _v(d - r, 0, z), _v(tx, ty, z)).toShape(),
        ]
        return Part.Wire(edges)

    def area(self) -> float:
        """Closed form: the chord rectangle, plus the big segments, less the concave ones."""
        R, c, r, d, tx, ty = self.R, self.c, self.r, self.d, self.tx, self.ty
        chords = 2 * tx * 2 * ty
        big = math.pi - 2 * math.atan2(ty - c, tx)  # atan2 is negative: span over pi
        concave = 2 * math.atan2(ty, d - tx)
        return (
            chords
            + 2 * (R * R / 2) * (big - math.sin(big))
            - 2 * (r * r / 2) * (concave - math.sin(concave))
        )


COLLAR = Peanut(COLLAR_D / 2, WAIST_W, PITCH)
T_COLLAR = Peanut(T_COLLAR_D / 2, WAIST_W, PITCH)


def rounded_rect_area(w: float, h: float, r: float) -> float:
    return w * h - (4 - math.pi) * r * r


def prism(wire: Part.Wire, height: float) -> Part.Shape:
    return Part.Face(wire).extrude(_v(0, 0, height))


# =========================================================================
# geometry
# =========================================================================
def plate(t: float = PLATE_T) -> Part.Shape:
    return prism(W.rounded_rect(PLATE_W, PLATE_L, PLATE_R, 0.0), t)


def collar(outline: Peanut = COLLAR, plate_t: float = PLATE_T, height: float = HEIGHT) -> Part.Shape:
    """The waisted collar, with its top edge chamfered by a ruled loft to an inset outline."""
    body = prism(outline.wire(plate_t), height - TOP_CHAMFER - plate_t)
    cap = Part.makeLoft(
        [outline.wire(height - TOP_CHAMFER), outline.inset(TOP_CHAMFER).wire(height)],
        True,
        True,
    )
    return body.fuse([cap])


def counterbore(y0: float) -> Part.Shape:
    """Clearance over the shoulder, where the section is still 7.00 wide."""
    return Part.makeCylinder(R_CBORE, Z_CBORE + OVER, _v(0, y0, -OVER))


def bore(y0: float, r: float = R_BORE, z0: float = 0.0, height: float = HEIGHT) -> Part.Shape:
    return Part.makeCylinder(r, height - z0 + 2 * OVER, _v(0, y0, z0 - OVER))


def lead_in(y0: float, r: float = R_BORE, height: float = HEIGHT) -> Part.Shape:
    """A 45 deg cone at the mouth, half of it above the top face."""
    return Part.makeCone(
        r,
        r + 2 * BORE_LEAD,
        2 * BORE_LEAD,
        _v(0, y0, height - BORE_LEAD),
        _v(0, 0, 1),
    )


def rib(y0: float, angle: float, fit: Fit, r_bore: float = R_BORE,
        z0: float = RIB_Z0, z1: float = RIB_Z1) -> Part.Shape:
    """One crush rib: a flat-faced bar on the bore wall, ramped 45 deg at both ends.

    Drawn in the r-z plane along +X, extruded across Y, then turned to its
    angle. Its back is buried RIB_BURY into the wall.
    """
    face_r = r_rib(fit)
    ramp = r_bore - face_r
    profile = [
        (r_bore + RIB_BURY, z0),
        (r_bore, z0),
        (face_r, z0 + ramp),
        (face_r, z1 - ramp),
        (r_bore, z1),
        (r_bore + RIB_BURY, z1),
    ]
    points = [_v(r, -RIB_W / 2, z) for r, z in profile]
    face = Part.Face(Part.makePolygon(points + [points[0]]))
    shape = face.extrude(_v(0, RIB_W, 0))
    shape.rotate(_v(0, 0, 0), _v(0, 0, 1), angle)
    shape.translate(_v(0, y0, 0))
    return shape


def holder(fit: Fit) -> Part.Shape:
    shape = plate().fuse([collar()])
    for y0 in LAMP_Y:
        for tool in (counterbore(y0), bore(y0), lead_in(y0)):
            shape = shape.cut(tool)
    for y0 in LAMP_Y:
        for k in range(RIB_N):
            shape = shape.fuse([rib(y0, RIB_ANGLE0 + 360.0 * k / RIB_N, fit)])
    if not shape.isValid() or len(shape.Solids) != 1:
        raise RuntimeError("holder is not a single valid solid")
    return shape


# --- the tall variant -------------------------------------------------------
def floor_opening(y0: float) -> Part.Shape:
    """What passes the floor: the pip, and the two leads with room to be a little bent."""
    hole = Part.makeCylinder(T_R_PIP_HOLE, T_PLATE_T + 2 * OVER, _v(0, y0, -OVER))
    slot = prism(W.rounded_rect(T_LEAD_SLOT_L, T_LEAD_SLOT_W, T_LEAD_SLOT_W / 2 - 1e-3, -OVER),
                 T_PLATE_T + 2 * OVER)
    slot.translate(_v(0, y0, 0))
    return hole.fuse([slot])


def cavity(y0: float) -> Part.Shape:
    """Room for the blade and the shoulder above the floor, up to where the section is round."""
    return Part.makeCylinder(T_R_CAVITY, T_Z_CAVITY_TOP - T_PLATE_T + OVER, _v(0, y0, T_PLATE_T))


def tab(y0: float, sx: float, sy: float) -> Part.Shape:
    """One keying tab under the plate, in one corner of the board's slot.

    The slot outline shrunk by the fit, kept only where it is clear of the pip
    and the nearer lead: x past T_TAB_X0 and y past T_TAB_Y0, signs sx, sy.
    """
    outline = prism(W.slot_rect(-T_TAB_FIT, -T_TAB_DEPTH), T_TAB_DEPTH + OVER)
    keep = Part.makeBox(SLOT_W, SLOT_H, T_TAB_DEPTH + 2 * OVER,
                        _v(T_TAB_X0 if sx > 0 else -T_TAB_X0 - SLOT_W,
                           T_TAB_Y0 if sy > 0 else -T_TAB_Y0 - SLOT_H,
                           -T_TAB_DEPTH - OVER))
    shape = outline.common(keep)
    shape.translate(_v(0, y0, 0))
    return shape


def holder_tall(fit: Fit) -> Part.Shape:
    shape = plate(T_PLATE_T).fuse([collar(T_COLLAR, T_PLATE_T, T_HEIGHT)])
    for y0 in LAMP_Y:
        for tool in (floor_opening(y0), cavity(y0),
                     bore(y0, T_R_BORE, T_PLATE_T, T_HEIGHT), lead_in(y0, T_R_BORE, T_HEIGHT)):
            shape = shape.cut(tool)
    for y0 in LAMP_Y:
        for k in range(RIB_N):
            shape = shape.fuse([rib(y0, RIB_ANGLE0 + 360.0 * k / RIB_N, fit,
                                    T_R_BORE, T_RIB_Z0, T_RIB_Z1)])
        for sx in (1, -1):
            for sy in (1, -1):
                shape = shape.fuse([tab(y0, sx, sy)])
    if not shape.isValid() or len(shape.Solids) != 1:
        raise RuntimeError("tall holder is not a single valid solid")
    return shape


VARIANTS = {
    "": (holder, lambda: Z_BOARD),
    "tall": (holder_tall, lambda: T_LAMP_Z0),
}


# --- the neighbours, for the document and the report ---------------------
def lamp(y0: float, lamp_z0: float = Z_BOARD) -> Part.Shape:
    """The lamp's outer glass, with lamp z = lamp_z0 at the board's front face."""
    shape = G.outer_glass()
    shape.translate(_v(0, y0, -lamp_z0))
    return shape


def board_stub() -> Part.Shape:
    slab = prism(W.rounded_rect(30.0, 30.0, 1.0, -BOARD_T), BOARD_T)
    for y0 in LAMP_Y:
        slot = prism(W.slot_rect(0.0, -BOARD_T - OVER), BOARD_T + 2 * OVER)
        slot.translate(_v(0, y0, 0))
        slab = slab.cut(slot)
    return slab


def in12_edge(y: float) -> float:
    """X of the nearest IN-12 glass at height y up the board.

    The digit's outline in the board plane is a stadium, IN12_R end radius on
    an IN12_STRAIGHT run, so past the straight the edge curves away.
    """
    dy = max(0.0, abs(y) - IN12_STRAIGHT / 2)
    return IN12_X - math.sqrt(IN12_R**2 - dy**2)


# =========================================================================
# report
# =========================================================================
def _mm(value: float) -> str:
    text = f"{value:.3f}"
    return "0.000" if text == "-0.000" else text


def _prismoid(h: float, a0: float, am: float, a1: float) -> float:
    return h / 6 * (a0 + 4 * am + a1)


def target_volume(fit: Fit) -> float:
    """The holder's volume from its dimensions, independent of the booleans."""
    body = rounded_rect_area(PLATE_W, PLATE_L, PLATE_R) * PLATE_T
    body += COLLAR.area() * (HEIGHT - TOP_CHAMFER - PLATE_T)
    body += _prismoid(
        TOP_CHAMFER,
        COLLAR.area(),
        COLLAR.inset(TOP_CHAMFER / 2).area(),
        COLLAR.inset(TOP_CHAMFER).area(),
    )
    cbore_area = math.pi * R_CBORE**2
    bore_area = math.pi * R_BORE**2
    r2 = R_BORE + BORE_LEAD
    mouth = (
        math.pi / 3 * BORE_LEAD * (R_BORE**2 + R_BORE * r2 + r2**2)
        - bore_area * BORE_LEAD
    )
    per_lamp = cbore_area * Z_CBORE + bore_area * (HEIGHT - Z_CBORE) + mouth
    stand = rib_stand(fit)
    ribs = RIB_N * stand * (RIB_Z1 - RIB_Z0 - stand) * RIB_W
    return body - len(LAMP_Y) * (per_lamp - ribs)


def _section_extents(shape: Part.Shape, z: float, y0: float) -> tuple:
    """(half-width in X, half-height in Y) of shape's section about the axis at (0, y0)."""
    hx = hy = 0.0
    for wire in shape.slice(_v(0, 0, 1), z):
        for p in wire.discretize(Distance=0.05):
            hx = max(hx, abs(p.x))
            hy = max(hy, abs(p.y - y0))
    return hx, hy


def _wires_at(shape: Part.Shape, z: float) -> list:
    return sorted(shape.slice(_v(0, 0, 1), z), key=lambda w: Part.Face(w).Area)
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

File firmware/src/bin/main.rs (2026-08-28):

#![no_std]
#![no_main]
#![deny(
    clippy::mem_forget,
    reason = "mem::forget is generally not safe to do with esp_hal types, especially those \
    holding buffers for the duration of a data transfer."
)]
#![deny(clippy::large_stack_frames)]

use core::panic::PanicInfo;
use core::sync::atomic::AtomicBool;
use core::sync::atomic::Ordering;

use defmt::error;
use defmt::info;
use embassy_executor::Spawner;
use esp_hal::clock::CpuClock;
use esp_hal::interrupt::software::SoftwareInterruptControl;
use esp_hal::timer::timg::TimerGroup;
use nixie_clock::hv;
use nixie_clock::nixie_pins;
use nixie_clock::pd;
use nixie_clock::status;
use nixie_clock::status::BootPhase;
use nixie_clock::tctm;

extern crate alloc;

esp_bootloader_esp_idf::esp_app_desc!(
    env!("NIXIE_FIRMWARE_ID"),
    env!("CARGO_PKG_NAME"),
    env!("NIXIE_BUILD_TIME"),
    env!("NIXIE_BUILD_DATE"),
    esp_bootloader_esp_idf::ESP_IDF_COMPATIBLE_VERSION,
    esp_bootloader_esp_idf::MMU_PAGE_SIZE,
    0,
    u16::MAX,
    esp_bootloader_esp_idf::SECURE_VERSION
);

#[panic_handler]
fn panic(info: &PanicInfo) -> ! {
    static PANICKING: AtomicBool = AtomicBool::new(false);
    critical_section::with(|_| {
        if !PANICKING.swap(true, Ordering::Relaxed) {
            tctm::panic_flush();
            defmt::error!("{}", defmt::Display2Format(info));
            tctm::panic_flush();
        }
        loop {
            core::hint::spin_loop();
        }
    })
}

#[allow(
    clippy::large_stack_frames,
    reason = "it's not unusual to allocate larger buffers etc. in main"
)]
#[esp_rtos::main]
async fn main(spawner: Spawner) -> ! {
    // generator version: 1.3.0
    // generator parameters: --chip esp32s3 -o esp32s3-wroom-1 -o unstable-hal -o alloc -o wifi -o embassy -o vscode -o esp -o probe-rs -o defmt -o panic-rtt-target

    tctm::init_logging();
    info!(
        "Reset reason: {}",
        defmt::Debug2Format(&esp_hal::system::reset_reason())
    );
    info!(
        "Firmware {=str} ({})",
        env!("NIXIE_FIRMWARE_ID"),
        env!("NIXIE_BUILD_TIMESTAMP")
    );

    let config = esp_hal::Config::default().with_cpu_clock(CpuClock::max());
    let peripherals = esp_hal::init(config);
    let status_led = status::init(peripherals.LEDC, peripherals.GPIO38);

    // These GPIO pins are in use by some feature of the module and should not be used.
    let _ = peripherals.GPIO27;
    let _ = peripherals.GPIO28;
    let _ = peripherals.GPIO29;
    let _ = peripherals.GPIO30;
    let _ = peripherals.GPIO31;
    let _ = peripherals.GPIO32;

    esp_alloc::heap_allocator!(#[esp_hal::ram(reclaimed)] size: 73744);

    let timg0 = TimerGroup::new(peripherals.TIMG0);
    let sw_interrupt = SoftwareInterruptControl::new(peripherals.SW_INTERRUPT);
    esp_rtos::start(timg0.timer0, sw_interrupt.software_interrupt0);

    info!("Embassy initialized...");

    status::spawn(status_led, &spawner);

    status::report(BootPhase::Pd);
    pd::init(
        peripherals.I2C0,
        peripherals.GPIO1,
        peripherals.GPIO2,
        peripherals.GPIO35,
        peripherals.GPIO37,
        peripherals.GPIO36,
        &spawner,
    );

    status::report(BootPhase::Hv);
    hv::init(peripherals.GPIO8, peripherals.GPIO48, &spawner);

    status::report(BootPhase::Net);
    let seed = {
        let _trng = esp_hal::rng::TrngSource::new(peripherals.RNG, peripherals.ADC1);
        let rng = esp_hal::rng::Rng::new();
        ((rng.random() as u64) << 32) | (rng.random() as u64)
    };
    let wifi_stack = nixie_clock::net::init(peripherals.WIFI, seed, &spawner);
    nixie_clock::tctm::init(wifi_stack, &spawner);

    status::report(BootPhase::Time);
    nixie_clock::time::init(wifi_stack, &spawner);

    status::report(BootPhase::Display);
    let clock_pins = nixie_pins!(peripherals);
    nixie_clock::nixie::init(clock_pins, &spawner);

    wifi_stack.wait_config_up().await;
    match wifi_stack.config_v4() {
        Some(config) => info!("Connected at IP {}", config.address),
        None => error!("No wifi config after up"),
    }

    // All of the operational logic lives in tasks. Park main now that setup is complete.
    status::report(BootPhase::Running);
    core::future::pending::<()>().await;
    unreachable!("core::future::pending never completes");
}

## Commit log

2026-07-21 Initial commit. Nixie clock tubes and BCD controllers, plus 170V flyback booster. Missing MCU to set and manage time and USB-C PD power input
    [pcb.kicad_pcb, pcb.kicad_sch, power.kicad_sch]
2026-07-21 Add USB-PD and 3.3V and 5v converters
    [pcb.kicad_pcb, power.kicad_sch, untitled.kicad_sch]
2026-07-21 Add title and revision to schematic and board silkscreen, do a bit of tidying of the schematics
    [hv.kicad_sch, pcb.kicad_pcb, pcb.kicad_sch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]
2026-07-22 Add readme, license, fix psu_design. move datasheets readme to tube_notes
    [pcb.kicad_pcb]
2026-07-22 Add ESP32, finish wiring. Rev A complete
    [hv.kicad_sch, mcu.kicad_sch, pcb.kicad_pcb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]
2026-07-27 Partial Rev B, committing before splitting projects
    [3v3.kicad_sch, 5v.kicad_sch, hv.kicad_sch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]
2026-07-27 Split project into 3
    [3v3.kicad_sch, 5v.kicad_sch, face.kicad_pcb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]
2026-07-27 Rev B RC1
    [3v3.kicad_sch, face.kicad_pcb, face.kicad_sch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]
2026-07-27 Rev B RC2
    [3v3.kicad_sch, main.kicad_pcb, mcu.kicad_sch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]
2026-07-27 Rev B RC3
    [3v3.kicad_sch, main.kicad_pcb]
2026-07-27 Fix part # typos
    [usb.kicad_sch]
2026-07-27 Final Rev B
    [face.kicad_pcb, face.kicad_sch, hv.kicad_pcb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]
2026-07-29 HV converter Rev C redesign around LM5156
    [3v3.kicad_sch, 5v.kicad_sch, face.kicad_pcb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]
2026-07-29 Clock Face Rev C
    [face.kicad_pcb, face.kicad_sch, hv.kicad_pcb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]
2026-07-29 Fillet face corners
    [face.kicad_pcb]
2026-07-31 Main board Rev C
    [3v3.kicad_sch, 5v.kicad_sch, INS-1.FCStd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]
2026-07-31 Updated schematic and improved make release to reduce manual jlc work
    [3v3.kicad_sch, 5v.kicad_sch, main.kicad_pcb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]
2026-07-31 More schematic and parts tweaks
    [3v3.kicad_sch, 5v.kicad_sch, INS-1V2.FCStd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]
2026-07-31 Parts updates, a few board tweaks
    [3v3.kicad_sch, 5v.kicad_sch, main.kicad_pcb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]
2026-07-31 Update release process, update analysis to use INS-1 throughout
    [3v3.kicad_sch, face.kicad_sch, hv.kicad_pcb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]
2026-07-31 Fix footprints in face
    [face.kicad_pcb]
2026-07-31 Update face schematic footprints
    [face.kicad_sch]
2026-07-31 Update fab attributes, update silscreen to include step
    [face.kicad_pcb, hv.kicad_pcb, main.kicad_pcb]
2026-07-31 Fix silscreen, footprint errors
    [hv.kicad_pcb]
2026-07-31 Fix hv footprints again
    [hv.kicad_pcb]
2026-07-31 Add digikey profile, fix incorrect mpn on main
    [usb.kicad_sch]
2026-08-01 Fix ballast/divider resistors to match first line of table 5-2
    [face.kicad_sch, hv.kicad_sch]
2026-08-01 Fix part number on hv divider resistor
    [hv.kicad_sch]
2026-08-02 Improve several 3D models, design testing base plate
    [base.step, face.step, hv.kicad_pcb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]
2026-08-03 Update ins1 tube model, update hv/main connector to 1 vbus, 2 gnd connections, update hv inhibit circuit to be default inhibit and require positive enable from MCU
    [face.kicad_pcb, face.kicad_sch, hv.kicad_pcb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]
2026-08-03 Update INS-1 model in KiCAD
    [face.kicad_pcb, face.kicad_sch]
2026-08-04 Update IN-12 model to the one we've created
    [3v3.kicad_sch, IN12.FCStd, INS1.FCStd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]
2026-08-05 Fix schematic/footprint tools to require naming a board to inspect
2026-08-05 Initial commit of firmware skeleton
    [INS-1.FCStd, INS-1V2.FCStd, INS1-Wires.step]
2026-08-18 Initial wifi connection logic complete, fix a minor trace inconsistency on face pcb
    [face.kicad_pcb]
2026-08-18 Bump main to Rev D1, add EN_USB jumper to board, fix UART LED locations.
    [main.kicad_pcb, usb.kicad_sch]
2026-08-18 Tweaks to the new jumper
    [main.kicad_pcb, usb.kicad_sch]
2026-08-20 Fix a couple of minor bugs
    - Move wifi up logging to the end of main so that all tasks spawn first
    - Fix hv_fail_count reset in nixie.rs
    [main.rs, nixie.rs]
2026-08-20 Fix a couple of unlikely panics to log instead, make sntp timestamp generator based on build time instead of seconds since boot
    [main.rs, mod.rs]
2026-08-21 Add detailed status LED handling, declare 1.0
2026-08-21 Update readme, add real picture of the HV board
2026-08-22 Move hv rail handling to its own module
2026-08-22 Add missing hv init and boot phase status
    [main.rs, mod.rs]
2026-08-23 Fix various issues, clock working reliably on 5V
    [hv.rs, nixie.rs]
2026-08-23 Introduce wire crate to hold shared wire protocol message definitions for a host-side client
2026-08-24 Updated HV startup time to allow for slower soft starts by changing C9 on the HV board
2026-08-25 Update cad skill
2026-08-25 Change C9 to 2.2uF, slows slow start to ~200ms
    [hv.kicad_sch]
2026-08-27 Hold HV rail off until NTP is up
2026-08-28 3d printable case
    [Case.FCStd]
2026-08-28 More tcp client groundwork
2026-08-29 More cad
    [Case.FCStd, ins1_holder.stl]
2026-08-29 Update face to Rev D, update IN-12 footprint to accomodate properly sized pin sockets.
    [face.kicad_pcb, face.kicad_sch]
2026-09-02 More CAD tweaks
    [Case.FCStd, ins1_holder.stl]

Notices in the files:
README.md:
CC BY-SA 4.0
